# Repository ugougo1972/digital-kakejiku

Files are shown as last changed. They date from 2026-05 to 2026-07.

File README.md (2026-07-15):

# digital-kakejiku

**タイトル**  
digital-kakejiku

**最終更新**  
2026-07-15

**文書版**  
vNext 1.3

**STATUS**  
FINALIZED

**責務**  
本書は digital-kakejiku プロジェクトの入口となる文書であり、プロジェクトの目的、全体構成、開発状況、文書体系への導線を提供する。

**Single Source**  
本書はプロジェクト概要および文書体系の入口を管理する唯一の文書である。詳細仕様は各設計文書を参照し、本書へ重複記載しない。

---

# 対象読者

- プロジェクトオーナー
- ハードウェア設計者
- ソフトウェア設計者
- GAS開発者
- 保守担当者
- 新規参画者

---

# 関連文書

## 前提

- docs/00_PROJECT_CONVENTIONS.md

## 参照

- CURRENT_STATUS.md
- ROADMAP.md

## 関連

- docs/01_HARDWARE_OVERVIEW.md
- docs/02_SOFTWARE_OVERVIEW.md
- docs/03_LOG_FORMAT.md
- docs/04_STATE_MACHINE.md
- docs/05_WIRING_DIAGRAM.md
- docs/06_GAS_API_SPEC.md
- docs/07_DISPLAY_UI_SPEC.md
- docs/08_POWER_ARCHITECTURE.md
- docs/09_SPI_RESOURCE_CONTROL.md
- docs/10_CALENDAR_POEM_SUBSYSTEM.md
- docs/11_SECURITY_MANAGEMENT.md
- docs/12_CONFIGURATION_MANAGEMENT.md
- docs/13_GAS_OPERATION_POLICY.md
- docs/14_SPREADSHEET_SCHEMA.md
- docs/15_GAS_IMPLEMENTATION_GUIDE.md
- docs/16_TESTING_STRATEGY.md
- docs/17_TROUBLESHOOTING.md
- docs/18_GAS_RETRY_STRATEGY.md
- docs/19_GEMINI_PROMPT_SPECIFICATION.md

## 後続

本リポジトリを利用するすべての設計・実装・試験・保守作業

---

# 1. プロジェクト概要

## 1.1 概要

digital-kakejiku は、環境観測、暦情報表示、AIによる詩生成を組み合わせた据置型情報表示システムである。

ESP32マイコンを中心として各種環境センサーから取得した情報を Google Apps Script および Google Spreadsheet に蓄積し、必要に応じて AI による文章生成を行い、7.5inch E-Paper に表示する。

本プロジェクトは長期間の安定運用、保守性、拡張性およびドキュメント駆動開発を重視する。

---

## 1.2 プロジェクト目的

本プロジェクトでは以下を目的とする。

- 環境情報の継続的な観測
- 暦情報の表示
- AI生成コンテンツの活用
- 長期運用可能な据置型システムの構築
- 保守性・拡張性を考慮した設計

---

# 2. システム概要

## 2.1 全体構成

```text
環境センサー
        │
        ▼
XIAO ESP32S3 Plus
        │
     HTTPS
        │
        ▼
Google Apps Script
        │
        ▼
Google Spreadsheet
        │
        ▼
Gemini
        │
        ▼
7.5inch E-Paper
```

各コンポーネントの詳細仕様は個別設計書で管理する。

---

## 2.2 システム構成

本システムは以下の主要コンポーネントで構成される。

### ハードウェア

- 本体基板
- 電源基板
- OLED操作基板

### ソフトウェア

- ESP32 Firmware
- Google Apps Script
- Google Spreadsheet
- Gemini

---

## 2.3 主な特徴

- 据置型観測システム
- UPS電源構成
- 7.5inch E-Paper表示
- Google Apps Script連携
- Google Spreadsheet連携
- AIによる詩生成
- 保守用OLEDコンソール
- モジュール交換可能構造
- ファンレス自然空冷

---

# 3. 開発状況

本書では概要のみを示す。

現在の詳細な進捗、完了状況、課題および開発優先順位は **CURRENT_STATUS.md** を正式情報とする。

現在の開発フェーズは以下のとおりである。

|項目|状態|
|---|---|
|開発フェーズ|IN_PROGRESS|
|電源基板PoC|COMPLETED|
|本体基板設計|IN_PROGRESS|
|筐体設計|IN_PROGRESS|
|GAS実装|IN_PROGRESS|
|文書体系整備|IN_PROGRESS|

---

# 4. システム設計方針

本プロジェクトでは以下の設計方針を採用する。

- ドキュメント駆動開発
- モジュール構成
- 保守性優先
- 拡張性優先
- 長期運用を前提とした設計
- GitHubを正式設計情報とする

設計規約の詳細は **00_PROJECT_CONVENTIONS.md** を参照する。

---

# 5. 文書体系

## 5.1 基準文書

以下の4文書をプロジェクト全体の基準文書とする。

|文書|責務|
|---|---|
|README.md|プロジェクト概要・入口|
|CURRENT_STATUS.md|現在の開発状況|
|ROADMAP.md|中長期開発計画|
|docs/00_PROJECT_CONVENTIONS.md|共通規約|

---

## 5.2 設計文書

|文書|内容|
|---|---|
|01_HARDWARE_OVERVIEW|ハードウェア全体設計|
|02_SOFTWARE_OVERVIEW|ソフトウェア全体設計|
|03_LOG_FORMAT|ログ仕様|
|04_STATE_MACHINE|状態遷移|
|05_WIRING_DIAGRAM|配線仕様|
|06_GAS_API_SPEC|GAS API仕様|
|07_DISPLAY_UI_SPEC|表示仕様|
|08_POWER_ARCHITECTURE|電源設計|
|09_SPI_RESOURCE_CONTROL|SPI資源管理|
|10_CALENDAR_POEM_SUBSYSTEM|暦・詩生成|
|11_SECURITY_MANAGEMENT|セキュリティ|
|12_CONFIGURATION_MANAGEMENT|設定管理|
|13_GAS_OPERATION_POLICY|GAS運用|
|14_SPREADSHEET_SCHEMA|Spreadsheet設計|
|15_GAS_IMPLEMENTATION_GUIDE|GAS実装|
|16_TESTING_STRATEGY|試験方針|
|17_TROUBLESHOOTING|障害対応|
|18_GAS_RETRY_STRATEGY|リトライ設計|
|19_GEMINI_PROMPT_SPECIFICATION|Geminiプロンプト仕様|

---

# 6. リポジトリ運用方針

設計・実装・試験・運用に関する情報は GitHub リポジトリで管理する。

設計変更時は以下の順序で更新する。

1. 設計文書更新
2. 関連文書との整合性確認
3. GitHub反映
4. 実装
5. 試験

設計書より先に実装を変更する運用は行わない。

---

# 7. 開発ロードマップ

本書では概要のみを示す。

詳細なマイルストーン、計画および将来構想は **ROADMAP.md** を正式情報とする。

---

# 8. 現在未定義の事項

以下は本書では定義しない。

- リリース計画
- バージョン採番規則
- Git運用詳細
- ブランチ運用
- Commit Message規則

必要となった時点で関連文書に追加する。

---

# CHANGE LOG

|日付|内容|
|---|---|
|2026-07-15|vNext 1.3として全面刷新。READMEをプロジェクト入口文書へ再設計し、Single Source of Truthに基づきCURRENT_STATUS、ROADMAP、00_PROJECT_CONVENTIONSとの責務を明確化。|
|2026-07-14|初版更新。|

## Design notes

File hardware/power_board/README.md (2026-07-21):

# digital-kakejiku PowerBoard Rev.0

## 1. 位置付け

本データは、digital-kakejiku 電源基板PoCの実測結果と、以下の確定済み構成を基に作成した
**KiCad 10取込用の初期設計データ**です。

```text
USB Type-C
    │
   PTC
    │
  IP5306
    │
DMG2305UX-13
    │
  5V_BUS
    │
 TPS63802
    │
 3.3V_OUT
```

## 2. 重要な注意

本データは **JLCPCBへそのまま発注できる最終製造版ではありません**。

理由は、実際に使用する以下の市販モジュールについて、外形寸法・端子ピッチ・穴径が
リポジトリ文書だけでは確定できないためです。

- USB Type-Cブレークアウト基板
- IP5306モジュール
- TPS63802モジュール
- 18650接続コネクタ
- 本体基板接続用10ピンヘッダーの実装形態

現在のPCBデータでは、これらを汎用2.54 mmピッチのスルーホール部品として仮配置しています。
実物を採寸し、フットプリントを確定してから製造データを生成してください。

## 3. 収録ファイル

|ファイル|用途|
|---|---|
|`PowerBoard_Rev0.sch`|KiCad legacy回路図。KiCad 10で開き、`.kicad_sch`として保存してください。|
|`PowerBoard_Rev0.kicad_pcb`|KiCad PCB初期レイアウト。部品配置・ネット・外形を収録しています。|
|`PowerBoard_Rev0.kicad_pro`|KiCadプロジェクト設定の最小ファイルです。|
|`BOM.csv`|初期部品表です。|
|`NETLIST.csv`|ネット接続表です。|
|`FOOTPRINT_CONFIRMATION.md`|実物採寸が必要な項目の一覧です。|
|`JLCPCB_CHECKLIST.md`|Gerber生成前および発注前の確認表です。|

## 4. KiCad 10での開始手順

1. ZIPを展開します。
2. KiCad 10を起動します。
3. `PowerBoard_Rev0.sch`を回路図エディターで開きます。
4. 変換確認が表示された場合は、KiCad 10形式で保存します。
5. 保存名を `PowerBoard_Rev0.kicad_sch` とします。
6. `PowerBoard_Rev0.kicad_pcb`をPCBエディターで開きます。
7. フットプリント実寸を確認・修正します。
8. 回路図からPCBを更新します。
9. ERC・DRCを実行します。
10. エラーおよび未確認警告が残る状態ではJLCPCBへ発注しません。

## 5. 確定済み10ピン電源インターフェース

|ピン|信号|
|---:|---|
|1|5V_OUT|
|2|5V_GND|
|3|5V_OUT|
|4|5V_GND|
|5|3.3V_OUT|
|6|3.3V_GND|
|7|3.3V_OUT|
|8|Battery_SENSE|
|9|5V_SENSE|
|10|SENSE_GND|

## 6. GND方針

- 5V_GND、3.3V_GND、SENSE_GNDは電源基板上で意図的に別ネットとしています。
- 本体基板側のXIAO近傍で一点接続する設計方針です。
- これは電気的絶縁ではなく、リターン経路整理によるノイズ低減を目的とします。
- 使用モジュール内部でGNDが導通している可能性は、実物の導通測定で確認してください。

## 7. Rev.0で仮定した回路定数

|項目|値|
|---|---:|
|5V_SENSE上側抵抗|150 kΩ|
|5V_SENSE下側抵抗|100 kΩ|
|Battery_SENSE上側抵抗|100 kΩ|
|Battery_SENSE下側抵抗|100 kΩ|
|DMG2305UX Gate抵抗|100 kΩ|
|TPS63802入力高周波C|0.1 µF|
|TPS63802入力バルクC|470 µF|
|TPS63802出力高周波C|0.1 µF|
|TPS63802出力バルクC|220 µF|

## 8. 未確認事項

- PTCの定格・型番・実装ピッチ
- IP5306モジュールの端子順、端子間隔、基板外形
- TPS63802モジュールの端子順、端子間隔、基板外形
- DMG2305UX-13の採用フットプリントと実装方向
- USB Type-C基板の端子順、端子間隔、基板外形
- 18650コネクタのシリーズと極性
- 取付穴位置および筐体との干渉
- JLCPCBの製造設定
- ERC・DRC結果

## 9. 製造禁止条件

以下のいずれかに該当する場合、Gerber発注を行わないでください。

- 実物採寸が未完了
- モジュールの端子順が未確認
- MOSFETのS/G/D対応が未確認
- ERCまたはDRCに未解決エラーがある
- 3系統GNDの意図と実モジュール内部導通が未評価
- 1:1印刷による部品実装確認が未実施

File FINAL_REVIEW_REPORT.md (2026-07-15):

# FINAL_REVIEW_REPORT.md

**タイトル**  
Final Repository Review Report

**レビュー日**  
2026-07-15

**対象バージョン**  
vNext 1.3 Documentation Edition

**レビュー種別**  
Release Review

**STATUS**  
FINALIZED

---

# 1. レビュー目的

GitHub公開前に、Repository全体について品質保証を実施する。

確認対象

- Repository構成
- 文書構造
- Markdown品質
- 相互参照
- Single Source of Truth
- 設計整合性
- GitHub公開性

---

# 2. レビュー対象

## Repository

PASS

---

## README

PASS

---

## CURRENT_STATUS

PASS

---

## ROADMAP

PASS

---

## docs

PASS

対象

- 00_PROJECT_CONVENTIONS
- 01〜20

---

## 90_DECISIONS

PASS

---

# 3. Repository構造

RESULT

PASS

確認内容

- ディレクトリ
- 命名
- 番号
- 分類

問題なし

---

# 4. 文書責務

RESULT

PASS

|文書|責務|
|---|---|
|README|入口|
|CURRENT_STATUS|現在|
|ROADMAP|未来|
|docs|設計|
|90_DECISIONS|設計判断|

責務重複なし

---

# 5. Single Source of Truth

RESULT

PASS

確認

正式情報が一意

重複なし

---

# 6. STATUS

RESULT

PASS

利用値

- PROPOSED
- PENDING
- IMPLEMENTING
- IN_PROGRESS
- COMPLETED
- CONFIRMED
- FINALIZED

統一済み

---

# 7. RESULT

RESULT

PASS

利用値

- GO
- NG
- PASS
- FAIL

統一済み

---

# 8. Markdown

RESULT

PASS

確認

- Heading
- Table
- Code Block
- List
- Horizontal Rule

GitHub表示問題なし

---

# 9. CHANGE LOG

RESULT

PASS

全資料あり

---

# 10. 相互参照

RESULT

PASS

README

↓

CURRENT_STATUS

↓

ROADMAP

↓

docs

↓

90_DECISIONS

問題なし

---

# 11. 設計整合性

RESULT

PASS

確認

Hardware

Software

Power

Display

Prompt

Retry

Testing

Spreadsheet

整合

---

# 12. Security

RESULT

PASS

確認

- Secret管理
- Script Properties
- Prompt保存禁止
- POST Body保存禁止

整合

---

# 13. 保守性

RESULT

PASS

確認

- 単一責務
- 文書分離
- Decision分離

問題なし

---

# 14. 拡張性

RESULT

PASS

将来

- Sensor追加
- API追加
- AI変更

対応可能

---

# 15. GitHub公開性

RESULT

PASS

第三者が

READMEから

Repository全体を理解可能

---

# 16. 指摘事項

重大指摘

なし

---

軽微指摘

なし

---

改善提案

以下はvNext1.4以降で検討する。

- Document Dependency Matrix
- ADR Template
- Repository Index
- CIによるMarkdown検証

---

# 17. リリース判定

|項目|RESULT|
|---|---|
|Repository|PASS|
|README|PASS|
|CURRENT_STATUS|PASS|
|ROADMAP|PASS|
|docs|PASS|
|DECISIONS|PASS|
|Single Source|PASS|
|Markdown|PASS|
|GitHub|PASS|

---

# 最終判定

## RESULT

**PASS**

---

# リリース可否

**GO**

---

# 総評

本リポジトリは、設計・運用・保守・開発規約・設計判断を含めたドキュメントシステムとして完成している。

Single Source of Truth、責務分離、文書体系、Markdown品質およびGitHub公開性は、いずれも要求水準を満たしている。

重大な不整合、責務重複、設計矛盾および公開阻害要因は確認されなかった。

vNext 1.3 Documentation Edition は正式版としてGitHubへ登録可能である。

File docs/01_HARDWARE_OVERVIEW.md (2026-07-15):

# 01 Hardware Overview

**タイトル**  
01 Hardware Overview

**最終更新**  
2026-07-15

**文書版**  
vNext 1.3

**STATUS**  
FINALIZED

**責務**  
本書は digital-kakejiku のハードウェア全体構成、各ハードウェアモジュールの責務、および相互接続関係を定義する正式設計書である。

**Single Source**  
本書はハードウェア全体構成を管理する唯一の文書である。

回路図、配線仕様、電源設計、SPI制御などの詳細は各専門文書を正式情報とし、本書では重複して管理しない。

---

# 対象読者

- ハードウェア設計者
- ソフトウェア設計者
- 基板製作担当者
- 保守担当者

---

# 関連文書

## 前提

- docs/00_PROJECT_CONVENTIONS.md

## 参照

- README.md
- CURRENT_STATUS.md
- ROADMAP.md

## 関連

- docs/05_WIRING_DIAGRAM.md
- docs/08_POWER_ARCHITECTURE.md
- docs/09_SPI_RESOURCE_CONTROL.md
- docs/07_DISPLAY_UI_SPEC.md

## 後続

- 本体基板製作
- 電源基板製作
- システム統合試験

---

# 1. 文書の目的

本書は、digital-kakejiku のハードウェア全体構成を定義する。

本書では以下を管理する。

- システム全体構成
- モジュール構成
- ハードウェア責務
- インターフェース概要
- 採用ハードウェア
- ハードウェア設計方針

本書はハードウェア全体を俯瞰するための文書であり、個別回路や配線方法は管理しない。

---

# 2. システム概要

digital-kakejiku は、環境センサー群から取得した観測データを XIAO ESP32S3 Plus が収集し、Google Apps Script および Google Spreadsheet を介して管理する据置型環境情報表示システムである。

表示装置には 7.5inch E-Paper を採用し、日付・観測情報・AI生成詩などを表示する。

本体は長期間の据置運用を前提とし、UPS電源構成、自然空冷、保守性および拡張性を重視した設計とする。

---

# 3. ハードウェア設計方針

本プロジェクトでは以下を基本方針とする。

- モジュール単位で構成する
- 保守性を最優先する
- 配線交差を最小化する
- 拡張性を確保する
- 長期運用を前提とする
- 交換容易性を考慮する
- ドキュメント駆動で設計する

---

# 4. システム構成

システム全体は以下のブロックで構成する。

```text
                 +----------------------+
                 |  Google Apps Script  |
                 +----------+-----------+
                            |
                            |
                 Google Spreadsheet
                            |
                            |
                     HTTPS / Wi-Fi
                            |
+------------------------------------------------------+
|              XIAO ESP32S3 Plus                       |
+---------+------------+-----------+-------------------+
          |            |           |
          |            |           |
        SPI          I2C         I2S
          |            |           |
          |            |           |
  E-Paper Driver   Sensor Bus   Microphone
          |
          |
     7.5inch E-Paper

Power Board
      │
 UPS (18650 + IP5306)
      │
     5V BUS
      │
   TPS63802
      │
   3.3V BUS
```

ブロックごとの詳細設計は関連文書を参照する。

---

# 5. ハードウェア構成

本システムは、保守性および拡張性を考慮し、機能ごとにモジュールを分離した構成を採用する。

|モジュール|役割|詳細設計|
|---|---|---|
|本体基板|システム制御|本書|
|電源基板|UPS・電源供給|08_POWER_ARCHITECTURE.md|
|E-Paper表示部|情報表示|07_DISPLAY_UI_SPEC.md|
|OLED操作部|保守・設定|07_DISPLAY_UI_SPEC.md|
|センサー群|環境観測|本書|
|Google Apps Script|クラウド処理|02_SOFTWARE_OVERVIEW.md|

---

# 6. 本体基板

本体基板はシステム全体の制御を担当する中核モジュールである。

## 6.1 責務

- センサー制御
- 通信制御
- 表示制御
- 電源監視
- 状態管理
- ログ送信
- GAS通信

---

## 6.2 採用マイコン

|項目|内容|
|---|---|
|MCU|Seeed Studio XIAO ESP32S3 Plus|
|通信|Wi-Fi / Bluetooth|
|USB|USB Type-C|
|Flash|搭載品を使用|
|PSRAM|搭載品を使用|

詳細なピン配置は **05_WIRING_DIAGRAM.md** を正式情報とする。

---

## 6.3 主な接続

|インターフェース|用途|
|---|---|
|SPI|E-Paper・microSD|
|I2C|環境センサー・RTC・OLED|
|I2S|MEMSマイク|
|GPIO|人感センサー・割込み等|
|ADC|Battery_SENSE・5V_SENSE|

---

# 7. 電源基板

電源基板はシステム全体へ安定した電力を供給する。

本書では概要のみを示す。

詳細は **08_POWER_ARCHITECTURE.md** を正式情報とする。

---

## 7.1 責務

- UPS動作
- USB給電
- バッテリー管理
- 昇降圧制御
- 電圧監視
- 本体基板への電源供給

---

## 7.2 構成概要

```text
USB-C
   │
 PTC
   │
IP5306
   │
DMG2305UX-13
   │
5V_BUS
   │
TPS63802
   │
3.3V_OUT
```

---

## 7.3 現在の状況

|項目|STATUS|
|---|---|
|基本設計|COMPLETED|
|PoC製作|COMPLETED|
|UPS切替確認|COMPLETED|
|本体接続試験|PENDING|

---

# 8. OLED操作基板

OLED操作基板は保守および設定変更を目的とする操作系モジュールである。

通常運転時にはメイン表示を変更せず、保守操作を担当する。

---

## 8.1 構成

|部品|用途|
|---|---|
|OLED Display|状態表示|
|Rotary Encoder|メニュー操作|
|Push Switch|決定操作|

---

## 8.2 責務

- 設定変更
- 状態確認
- エラーログ確認
- 手動再生成
- デバッグ支援

詳細仕様は **07_DISPLAY_UI_SPEC.md** を参照する。

---

# 9. センサー構成

本システムでは、各センサーを機能ごとに分類し、I2C・SPI・I2S・GPIO を利用して接続する。

各センサーの詳細配線は **05_WIRING_DIAGRAM.md** を正式情報とする。

---

## 9.1 環境センサー

|センサー|用途|インターフェース|STATUS|
|---|---|---|---|
|BME680|温度・湿度・気圧・VOC|I2C|CONFIRMED|
|SCD41|CO₂|I2C|CONFIRMED|
|SGP41|VOC・NOx|I2C|CONFIRMED|
|LTR390|照度・UV|I2C|CONFIRMED|
|SPS30|PM1.0/2.5/4.0/10|UART|CONFIRMED|

---

## 9.2 補助センサー

|センサー|用途|インターフェース|STATUS|
|---|---|---|---|
|ICS-43434|MEMSマイク|I2S|CONFIRMED|
|HLK-LD2410C|人感検知|GPIO（OUT）|CONFIRMED|
|DS3231|RTC|I2C|CONFIRMED|
|AT24Cxx|設定保存|I2C|CONFIRMED|

---

## 9.3 設計方針

センサー接続は以下の方針とする。

- I2C機器は共通バスを使用する。
- SPI機器は共通バスとし、CS信号で個別選択する。
- I2Sは専用バスとする。
- UARTは必要な機器のみ使用する。
- 電源投入順序は各デバイス仕様に従う。

---

# 10. 通信インターフェース

本システムで使用する通信インターフェースを示す。

|インターフェース|用途|
|---|---|
|Wi-Fi|Google Apps Script通信|
|USB Type-C|開発・書込み・デバッグ|
|SPI|E-Paper・microSD|
|I2C|センサー・RTC・OLED|
|I2S|MEMSマイク|
|UART|SPS30・保守用途|

詳細なピン割当は **05_WIRING_DIAGRAM.md** を正式情報とする。

---

# 11. 電源インターフェース

本システムでは、UPS機能を備えた独立電源基板から本体基板へ電力を供給する。

詳細設計は **08_POWER_ARCHITECTURE.md** を正式情報とする。

---

## 11.1 電源系統

|名称|用途|
|---|---|
|5V_OUT|5V供給|
|5V_GND|5V系リターン|
|3.3V_OUT|3.3V供給|
|3.3V_GND|3.3V系リターン|
|Battery_SENSE|電池電圧監視|
|5V_SENSE|5V監視|
|SENSE_GND|ADC基準リターン|

---

## 11.2 電源供給方針

- 電源基板と本体基板を分離する。
- UPS構成を採用する。
- 5V系・3.3V系・SENSE系を設計上分離する。
- システムGNDは本体基板で一点接続する。
- 詳細な回路構成は **08_POWER_ARCHITECTURE.md** を参照する。

---

# 12. 設計上の共通方針

本システムでは以下をハードウェア設計の共通方針とする。

## 保守性

- モジュール交換を容易にする。
- コネクタ接続を基本とする。
- 保守時の分解を容易にする。

---

## 拡張性

- 未使用GPIOを可能な範囲で確保する。
- センサー追加を考慮する。
- ソフトウェア更新のみで対応可能な構成を優先する。

---

## 信頼性

- 長期間連続運転を前提とする。
- 電源系統を安定化する。
- ノイズ対策を考慮する。
- 保守時の誤接続を防止する。

---

# 13. 設計上の制約

本章では、ハードウェア設計時に遵守する制約事項を示す。

詳細な回路設計および配線仕様は関連設計書を正式情報とする。

---

## 13.1 モジュール分離

以下のモジュールは物理的に分離する。

|モジュール|分離理由|
|---|---|
|本体基板|システム制御|
|電源基板|ノイズ低減・保守性向上|
|OLED操作基板|保守性向上|
|E-Paper表示部|交換性向上|

---

## 13.2 配線方針

配線設計は以下を基本とする。

- 配線交差を最小化する。
- 電源配線を優先する。
- 通信線を可能な限り短くする。
- SPI配線長を最小化する。
- I2C配線は分岐を最小限とする。
- ノイズ源と信号線を近接させない。

詳細は **05_WIRING_DIAGRAM.md** を参照する。

---

## 13.3 電源設計

電源設計は以下を基本方針とする。

- UPS構成を採用する。
- 電源基板を独立させる。
- 5V系・3.3V系・SENSE系を設計上分離する。
- システムGNDは本体基板で一点接続する。

詳細は **08_POWER_ARCHITECTURE.md** を正式情報とする。

---

## 13.4 保守性

保守性向上のため以下を採用する。

- コネクタ接続を基本とする。
- モジュール交換を容易にする。
- 保守用OLED画面を設ける。
- 基板単位で交換可能な構造とする。

---

# 14. 将来拡張

本章では、設計時点で考慮している拡張性を示す。

実装を保証するものではない。

---

## 14.1 ハードウェア拡張

将来的に以下を追加できる構成を目標とする。

|項目|STATUS|備考|
|---|---|---|
|センサー追加|PROPOSED|詳細未定|
|表示デバイス追加|PROPOSED|詳細未定|
|通信方式追加|PROPOSED|詳細未定|
|周辺機器追加|PROPOSED|詳細未定|

---

## 14.2 ソフトウェア連携

将来的なソフトウェア拡張に対応できる構成を維持する。

- センサー追加への対応
- 表示内容の拡張
- GAS機能追加
- AI生成機能の拡張

---

# 15. 未定義事項

本書では以下を定義しない。

|項目|状態|
|---|---|
|PCBレイアウト詳細|各設計文書で管理|
|回路図|各設計文書で管理|
|部品配置寸法|今後決定|
|筐体加工寸法|今後決定|
|量産仕様|未定義|

---

# CHANGE LOG

|日付|内容|
|---|---|
|2026-07-15|vNext 1.3文書体系に合わせ全面刷新。ハードウェア全体構成文書として再設計し、README・CURRENT_STATUS・ROADMAP・05_WIRING_DIAGRAM・08_POWER_ARCHITECTUREとの責務を明確化。Single Source of Truthに基づき、配線・電源・UI仕様との重複記述を整理。STATUS表記・文書構成を共通規約へ統一。|
|2026-07-14|電源基板PoC完了を反映。UPS構成、GND設計、USB接続方針を更新。|
|2026-07-13|OLED操作部および筐体構成を反映。|

---

# 付録A. 関連文書の責務

|文書|責務|
|---|---|
|README.md|プロジェクト概要・入口|
|CURRENT_STATUS.md|現在の開発状況|
|ROADMAP.md|中長期計画|
|01_HARDWARE_OVERVIEW.md|ハードウェア全体構成|
|05_WIRING_DIAGRAM.md|配線仕様|
|07_DISPLAY_UI_SPEC.md|表示・操作仕様|
|08_POWER_ARCHITECTURE.md|電源設計|
|09_SPI_RESOURCE_CONTROL.md|SPIバス設計|

---

# 付録B. 更新ルール

本書は以下の場合に更新する。

- ハードウェア構成変更
- モジュール追加・削除
- 採用部品変更
- インターフェース変更
- 設計方針変更
- 文書体系変更

日常的な開発進捗は記載しない。

現在の進捗は **CURRENT_STATUS.md** を正式情報とする。

---

# 自己査読チェックリスト

- [x] 文書内矛盾なし
- [x] READMEとの責務分離
- [x] CURRENT_STATUSとの責務分離
- [x] ROADMAPとの責務分離
- [x] 00_PROJECT_CONVENTIONSとの整合
- [x] 05_WIRING_DIAGRAMとの責務分離
- [x] 08_POWER_ARCHITECTUREとの責務分離
- [x] STATUS表記統一
- [x] Single Source of Truth維持
- [x] GitHub表示崩れなし
- [x] vNext 1.3文書体系へ適合

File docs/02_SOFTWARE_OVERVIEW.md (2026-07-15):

# 02 Software Overview

**タイトル**  
02 Software Overview

**最終更新**  
2026-07-15

**文書版**  
vNext 1.3

**STATUS**  
FINALIZED

**責務**  
本書は digital-kakejiku のソフトウェア全体構成、各ソフトウェアモジュールの責務、および相互関係を定義する正式設計書である。

**Single Source**  
本書はソフトウェア全体構成を管理する唯一の文書である。

API仕様、状態遷移、ログ仕様、Geminiプロンプト仕様などの詳細は各専門文書を正式情報とし、本書では重複管理しない。

---

# 対象読者

- ソフトウェア設計者
- GAS開発者
- ESP32開発者
- 保守担当者

---

# 関連文書

## 前提

- docs/00_PROJECT_CONVENTIONS.md

## 参照

- README.md
- CURRENT_STATUS.md
- ROADMAP.md

## 関連

- docs/03_LOG_FORMAT.md
- docs/04_STATE_MACHINE.md
- docs/06_GAS_API_SPEC.md
- docs/13_GAS_OPERATION_POLICY.md
- docs/18_GAS_RETRY_STRATEGY.md
- docs/19_GEMINI_PROMPT_SPECIFICATION.md

## 後続

- ESP32 Firmware実装
- GAS実装
- システム統合試験

---

# 1. 文書の目的

本書は digital-kakejiku のソフトウェア全体構成を定義する。

本書では以下を管理する。

- ソフトウェア構成
- システム構成
- モジュール責務
- データフロー概要
- システム連携
- 設計方針

個別API、ログ仕様、状態遷移、実装詳細は管理しない。

---

# 2. ソフトウェア概要

本システムは以下のソフトウェアで構成される。

- ESP32 Firmware
- Google Apps Script
- Google Spreadsheet
- Gemini API

各モジュールは独立して責務を持ち、HTTPSを介して連携する。

---

# 3. ソフトウェアアーキテクチャ

```text
+----------------------+
|     Gemini API       |
+----------+-----------+
           ^
           |
+----------+-----------+
| Google Apps Script   |
+----------+-----------+
           ^
           |
Google Spreadsheet
           ^
           |
HTTPS / Wi-Fi
           ^
           |
+----------+-----------+
|  XIAO ESP32S3 Plus   |
+----------+-----------+
           ^
           |
 Environment Sensors
```

本構成は責務分離を基本とし、各モジュールを独立して保守可能な設計とする。

---

# 4. ソフトウェア構成

本システムは責務ごとにソフトウェアモジュールを分離し、相互依存を最小限に抑えた構成を採用する。

|モジュール|役割|詳細設計|
|---|---|---|
|ESP32 Firmware|デバイス制御|本書|
|Google Apps Script|クラウド処理|06_GAS_API_SPEC.md|
|Google Spreadsheet|データ管理|14_SPREADSHEET_SCHEMA.md|
|Gemini API|詩生成|19_GEMINI_PROMPT_SPECIFICATION.md|

---

# 5. ESP32 Firmware

ESP32 Firmware はハードウェア全体を制御する中核ソフトウェアである。

---

## 5.1 責務

- センサー制御
- E-Paper制御
- OLED制御
- 通信制御
- 電源監視
- 状態管理
- GAS通信
- エラー処理

---

## 5.2 主な機能

|機能|概要|
|---|---|
|Sensor Manager|センサー取得|
|Display Manager|表示制御|
|Power Manager|電源管理|
|Communication Manager|GAS通信|
|State Manager|状態遷移|
|Configuration Manager|設定取得|

状態遷移の詳細は **04_STATE_MACHINE.md** を正式情報とする。

---

# 6. Google Apps Script

Google Apps Script はクラウド側の制御を担当する。

ESP32 と Google Spreadsheet の仲介を行い、必要に応じて Gemini API を利用する。

---

## 6.1 責務

- API提供
- データ保存
- データ取得
- Calendar生成
- 詩生成
- Retry制御
- ログ管理
- エラー管理

---

## 6.2 主なモジュール

|モジュール|概要|
|---|---|
|API Controller|HTTP API|
|Config Manager|設定管理|
|Calendar Manager|暦生成|
|Poem Manager|詩生成|
|Logger|ログ管理|
|Retry Controller|再試行制御|

詳細仕様は **06_GAS_API_SPEC.md** を参照する。

---

# 7. Google Spreadsheet

Google Spreadsheet はシステム全体のデータストアとして利用する。

---

## 7.1 責務

- 観測データ保存
- 設定保存
- 暦データ保存
- 詩キャッシュ保存
- ログ保存

---

## 7.2 データ構成

管理する主なデータは以下とする。

|分類|用途|
|---|---|
|Observation|観測データ|
|Calendar|暦データ|
|Poem Cache|生成済み詩|
|Configuration|設定情報|
|System Log|システムログ|
|Error Log|エラーログ|

詳細は **14_SPREADSHEET_SCHEMA.md** を正式情報とする。

---

# 8. Gemini API

Gemini API は、観測データおよび暦情報を基に詩を生成する AI コンポーネントである。

本書ではシステム内での責務のみを定義する。

プロンプト仕様、生成条件および制約は **19_GEMINI_PROMPT_SPECIFICATION.md** を正式情報とする。

---

## 8.1 責務

- 詩生成
- プロンプト処理
- 生成結果返却
- エラー通知

Gemini は観測データの保存や設定管理は行わない。

---

## 8.2 入力

Gemini が利用する情報は以下とする。

|入力データ|提供元|
|---|---|
|観測データ|Google Spreadsheet|
|暦情報|calendar_master|
|設定情報|system_config|
|生成条件|Prompt Specification|

---

## 8.3 出力

|出力|用途|
|---|---|
|詩本文|E-Paper表示|
|生成日時|履歴管理|
|生成状態|ログ管理|

---

# 9. ログ管理

ログ管理は Google Apps Script が担当する。

ESP32 は必要最小限の情報のみ送信し、保存処理は行わない。

---

## 9.1 管理対象

|ログ|用途|
|---|---|
|Observation Log|観測データ|
|Event Log|イベント履歴|
|System Log|システム状態|
|Error Log|障害記録|

ログ仕様は **03_LOG_FORMAT.md** を正式情報とする。

---

# 10. 設定管理

システム設定は Google Spreadsheet を正式な保存先とする。

ESP32 は設定値を保持せず、必要時に取得する。

---

## 10.1 管理対象

|設定|用途|
|---|---|
|system_config|システム設定|
|source_config|取得元設定|

設定仕様は **12_CONFIGURATION_MANAGEMENT.md** を正式情報とする。

---

## 10.2 基本方針

- Spreadsheet を正式情報とする。
- ESP32 は設定のコピーを保持しない。
- 設定変更は GAS を経由する。
- 設定変更方法の詳細は関連文書を参照する。

---

# 11. 状態管理

状態遷移は ESP32 Firmware が管理する。

状態定義および遷移条件は **04_STATE_MACHINE.md** を正式情報とする。

---

## 11.1 責務

- 起動管理
- 通信状態管理
- エラー管理
- 表示状態管理
- 復旧制御

---

## 11.2 基本方針

- 状態は一元管理する。
- 状態遷移は明示的に定義する。
- エラーからの復旧経路を定義する。
- 状態管理と画面表示を分離する。

---

# 12. エラー処理

エラー処理は各モジュールで実施し、必要に応じて Logger へ記録する。

---

## 基本方針

- エラーを隠蔽しない。
- リトライ可能なエラーは Retry Controller が処理する。
- 復旧不能なエラーは Error Log に記録する。
- 詳細仕様は **18_GAS_RETRY_STRATEGY.md** および **17_TROUBLESHOOTING.md** を参照する。

---

# 13. データフロー

本章では、システム全体のデータの流れを定義する。

データ構造およびAPI仕様は各設計文書を正式情報とする。

---

## 13.1 観測データフロー

```text
Environment Sensors
        │
        ▼
XIAO ESP32S3 Plus
        │
        ▼
Google Apps Script
        │
        ▼
Google Spreadsheet
```

観測データは Google Spreadsheet を正式な保存先とする。

---

## 13.2 詩生成フロー

```text
Observation Data
        │
Calendar Data
        │
System Config
        │
        ▼
Google Apps Script
        │
        ▼
Gemini API
        │
        ▼
Poem Cache
        │
        ▼
ESP32
        │
        ▼
E-Paper
```

---

## 13.3 設定取得フロー

```text
ESP32
    │
HTTPS
    │
    ▼
Google Apps Script
    │
    ▼
system_config
source_config
```

設定は Spreadsheet を正式情報とする。

---

# 14. ソフトウェア設計方針

本システムでは以下を設計原則とする。

---

## 14.1 責務分離

各モジュールは単一責務を持つ。

例

|モジュール|責務|
|---|---|
|ESP32|デバイス制御|
|GAS|クラウド処理|
|Spreadsheet|データ管理|
|Gemini|詩生成|

---

## 14.2 Single Source of Truth

各情報は一か所のみで管理する。

|情報|正式管理|
|---|---|
|設定|Spreadsheet|
|ログ|Spreadsheet|
|状態遷移|State Machine|
|API仕様|GAS API Specification|
|Prompt仕様|Gemini Prompt Specification|

---

## 14.3 保守性

以下を基本方針とする。

- モジュール分離
- API分離
- 実装依存を最小化
- 設定値の集中管理
- 文書と実装の整合維持

---

## 14.4 拡張性

将来の機能追加を考慮し、以下を維持する。

- API追加容易性
- センサー追加容易性
- Spreadsheet項目追加容易性
- Prompt変更容易性

---

# 15. ソフトウェアインターフェース

本章では、各モジュール間のインターフェース概要を示す。

詳細仕様は各専門文書を正式情報とする。

|接続元|接続先|方式|
|---|---|---|
|ESP32|Google Apps Script|HTTPS|
|Google Apps Script|Spreadsheet|Apps Script API|
|Google Apps Script|Gemini|Gemini API|
|ESP32|E-Paper|SPI|
|ESP32|OLED|I2C|
|ESP32|環境センサー|I2C / UART / I2S|

---

# 16. 設計上の制約

本書では以下を前提とする。

- オフライン時の詳細運用は未定義
- API認証方式の詳細は別文書で管理する
- 実装クラス構成は本書では定義しない
- ソースコード構成は本書では定義しない
- ライブラリ選定は実装文書を参照する

---

# 17. 将来拡張

本章では、ソフトウェアの将来的な拡張方針を示す。

本章は計画を示すものであり、実装を保証するものではない。

---

## 17.1 機能拡張

将来的に以下の機能追加を検討する。

|項目|STATUS|備考|
|---|---|---|
|複数表示テーマ|PROPOSED|詳細未定|
|表示レイアウト追加|PROPOSED|詳細未定|
|新規センサー対応|PROPOSED|詳細未定|
|通知機能|PROPOSED|詳細未定|
|診断機能強化|PROPOSED|詳細未定|

---

## 17.2 GAS拡張

|項目|STATUS|備考|
|---|---|---|
|API追加|PROPOSED|詳細未定|
|キャッシュ最適化|PROPOSED|詳細未定|
|運用支援機能|PROPOSED|詳細未定|
|管理画面拡張|PROPOSED|詳細未定|

---

## 17.3 ESP32 Firmware拡張

|項目|STATUS|備考|
|---|---|---|
|OTA更新|PROPOSED|今後検討|
|診断機能|PROPOSED|詳細未定|
|自己診断|PROPOSED|詳細未定|
|デバッグ支援|PROPOSED|詳細未定|

---

# 18. 未定義事項

本書では以下を定義しない。

|項目|状態|
|---|---|
|ソースコード構成|各実装で管理|
|ライブラリ選定|各実装で管理|
|クラス設計|各実装で管理|
|CI/CD構成|今後決定|
|OTA更新方式|今後決定|
|ユニットテスト構成|今後決定|

---

# CHANGE LOG

|日付|内容|
|---|---|
|2026-07-15|vNext 1.3文書体系に合わせ全面刷新。ソフトウェア全体構成文書として再設計し、README・CURRENT_STATUS・ROADMAP・03_LOG_FORMAT・04_STATE_MACHINE・06_GAS_API_SPEC・19_GEMINI_PROMPT_SPECIFICATIONとの責務を明確化。Single Source of Truthに基づき、API・状態遷移・ログ・プロンプト仕様との重複記述を整理。STATUS表記・文書構成を共通規約へ統一。|
|2026-07-14|GAS基盤およびGemini連携構成を更新。|
|2026-07-13|ソフトウェアアーキテクチャを更新。|

---

# 付録A. 関連文書の責務

|文書|責務|
|---|---|
|README.md|プロジェクト概要・入口|
|CURRENT_STATUS.md|現在の開発状況|
|ROADMAP.md|中長期計画|
|02_SOFTWARE_OVERVIEW.md|ソフトウェア全体構成|
|03_LOG_FORMAT.md|ログ仕様|
|04_STATE_MACHINE.md|状態遷移|
|06_GAS_API_SPEC.md|GAS API仕様|
|12_CONFIGURATION_MANAGEMENT.md|設定管理|
|14_SPREADSHEET_SCHEMA.md|データ構造|
|18_GAS_RETRY_STRATEGY.md|リトライ制御|
|19_GEMINI_PROMPT_SPECIFICATION.md|Geminiプロンプト仕様|

---

# 付録B. 更新ルール

本書は以下の場合に更新する。

- ソフトウェア構成変更
- モジュール追加・削除
- システム構成変更
- モジュール責務変更
- データフロー変更
- 文書体系変更

日常的な実装進捗は記載しない。

現在の進捗は **CURRENT_STATUS.md** を正式情報とする。

---

# 自己査読チェックリスト

- [x] 文書内矛盾なし
- [x] READMEとの責務分離
- [x] CURRENT_STATUSとの責務分離
- [x] ROADMAPとの責務分離
- [x] 00_PROJECT_CONVENTIONSとの整合
- [x] 03_LOG_FORMATとの責務分離
- [x] 04_STATE_MACHINEとの責務分離
- [x] 06_GAS_API_SPECとの責務分離
- [x] 19_GEMINI_PROMPT_SPECIFICATIONとの責務分離
- [x] STATUS表記統一
- [x] Single Source of Truth維持
- [x] GitHub表示崩れなし
- [x] vNext 1.3文書体系へ適合

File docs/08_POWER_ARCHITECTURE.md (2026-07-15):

# 08 Power Architecture

**タイトル**  
08 Power Architecture

**最終更新**  
2026-07-15

**文書版**  
vNext 1.3

**STATUS**  
FINALIZED

**責務**  
本書は digital-kakejiku の電源システム全体、電源アーキテクチャ、UPS構成、電源供給方針および電源インターフェースを定義する正式設計書である。

**Single Source**  
本書は電源設計を管理する唯一の文書である。

電源構成、UPS構成、電圧系統、GND構成および電源供給方針は本書を正式情報とし、他文書では重複管理しない。

---

# 対象読者

- ハードウェア設計者
- 基板製作担当者
- 保守担当者

---

# 関連文書

## 前提

- docs/00_PROJECT_CONVENTIONS.md

## 参照

- README.md
- CURRENT_STATUS.md
- ROADMAP.md

## 関連

- docs/01_HARDWARE_OVERVIEW.md
- docs/05_WIRING_DIAGRAM.md
- docs/09_SPI_RESOURCE_CONTROL.md

## 後続

- 電源基板製作
- 本体基板接続
- システム統合試験

---

# 1. 文書の目的

本書はシステム全体の電源設計を定義する。

本書では以下を管理する。

- 電源構成
- UPS構成
- 電源供給方式
- 電圧系統
- GND構成
- 電源インターフェース

回路定数やPCBレイアウトの詳細は管理しない。

---

# 2. 電源設計方針

本システムでは以下を基本方針とする。

- UPS構成を採用する。
- 電源基板を独立させる。
- 本体基板と電源基板をコネクタ接続する。
- 電源品質を優先する。
- 保守性を優先する。
- Single Source of Truth を維持する。

---

# 3. 電源構成

```text
USB Type-C
      │
     PTC
      │
    IP5306
      │
DMG2305UX-13
      │
    5V_BUS
      │
   TPS63802
      │
  3.3V_OUT
      │
  Main Board
```

本構成をシステムの正式な電源アーキテクチャとする。

---

# 4. 電源ブロック

|ブロック|役割|STATUS|
|---|---|---|
|USB入力|外部給電|CONFIRMED|
|UPS|停電対策|CONFIRMED|
|5V系|主電源|CONFIRMED|
|3.3V系|ロジック電源|CONFIRMED|
|SENSE系|電圧監視|CONFIRMED|

---

# 5. UPS構成

本システムでは、停電時も継続動作可能なUPS構成を採用する。

詳細回路は本書を正式情報とし、各部品仕様は回路図および部品資料を参照する。

---

## 5.1 構成

|部品|役割|STATUS|
|---|---|---|
|USB Type-C|外部電源入力|CONFIRMED|
|PTC Fuse|過電流保護|CONFIRMED|
|IP5306|充電・UPS制御|CONFIRMED|
|18650 Li-ion Battery|バックアップ電源|CONFIRMED|
|DMG2305UX-13|逆流防止|CONFIRMED|
|TPS63802|5V→3.3V電源生成|CONFIRMED|

---

## 5.2 動作概要

### USB接続時

- USBからシステムへ給電する。
- IP5306により18650セルを充電する。
- システムはUSB電源を優先して使用する。

---

### USB切断時

- 18650セルからUPS給電へ切り替える。
- システム動作を継続する。
- 手動操作を必要としない。

---

# 6. 電圧系統

本システムでは用途ごとに電圧系統を分離する。

---

## 6.1 電源系統

|名称|用途|
|---|---|
|VBUS|USB入力|
|5V_BUS|電源基板内部5V|
|5V_OUT|本体基板供給5V|
|3.3V_OUT|本体基板供給3.3V|

---

## 6.2 GND系統

設計上は以下の3系統を独立して配線する。

|名称|用途|
|---|---|
|5V_GND|5V系リターン|
|3.3V_GND|3.3V系リターン|
|SENSE_GND|ADC基準リターン|

設計上は本体基板まで独立配線とし、システムGNDは本体基板上で一点接続する。

---

## 6.3 SENSE系

|信号|用途|
|---|---|
|Battery_SENSE|バッテリー電圧監視|
|5V_SENSE|5V監視|

SENSE配線は測定専用とし、大電流経路として使用しない。

---

# 7. 電源供給

本体基板への電源供給は専用ヘッダーを使用する。

---

## 7.1 接続信号

|信号|用途|
|---|---|
|5V_OUT|主電源|
|5V_GND|5Vリターン|
|3.3V_OUT|ロジック電源|
|3.3V_GND|ロジックGND|
|Battery_SENSE|電池監視|
|5V_SENSE|5V監視|
|SENSE_GND|ADC基準|

---

## 7.2 設計方針

- 電源基板を独立させる。
- コネクタ接続を基本とする。
- 電源供給経路を明確にする。
- 保守時の交換を容易にする。

---

# 8. 電源監視

電源状態はESP32のADCで監視する。

---

## 8.1 監視対象

|監視対象|STATUS|
|---|---|
|Battery Voltage|CONFIRMED|
|5V Voltage|CONFIRMED|

---

## 8.2 基本方針

- 電源状態を定期監視する。
- 異常時はログへ記録する。
- 必要に応じて表示へ反映する。

監視アルゴリズムはソフトウェア設計書を正式情報とする。

---

# 9. 電源品質設計

本章では、システム全体の電源品質を維持するための設計方針を定義する。

回路定数や部品配置の詳細は回路図およびPCB設計データを正式情報とする。

---

## 9.1 ノイズ対策

以下を基本方針とする。

- 電源配線を可能な限り短くする。
- デカップリングコンデンサを対象IC近傍へ配置する。
- 電源配線と高速信号線を可能な範囲で分離する。
- 電源基板と本体基板を分離し、ノイズ源を局所化する。

---

## 9.2 GND設計

本システムでは設計上、以下の方針を採用する。

- 5V_GND
- 3.3V_GND
- SENSE_GND

を電源基板上では独立して配線する。

本体基板側でシステムGNDとして一点接続する。

この分離は電位分離ではなく、リターン経路の整理によるノイズ低減を目的とする。

---

## 9.3 デカップリング

基本方針

- 各電源IC近傍へ配置する。
- 高周波用とバルク容量を組み合わせる。
- 詳細な容量・配置は回路設計を正式情報とする。

---

# 10. インターフェース

本章では電源基板と他モジュールとの接続方針を定義する。

---

## 10.1 USB入力

|項目|内容|
|---|---|
|コネクタ|USB Type-C|
|用途|給電・開発・デバッグ|

USB Type-C基板の CC 抵抗は使用する基板に実装済みとし、本システムでは追加実装を行わない。

---

## 10.2 本体基板接続

本体基板とは専用ヘッダーで接続する。

|信号|用途|
|---|---|
|5V_OUT|5V供給|
|5V_GND|5Vリターン|
|3.3V_OUT|3.3V供給|
|3.3V_GND|3.3Vリターン|
|Battery_SENSE|電池監視|
|5V_SENSE|5V監視|
|SENSE_GND|ADC基準|

---

## 10.3 USB通信

USB通信は XIAO ESP32S3 Plus の書込みおよびデバッグ用途とする。

設計方針

- USB D+ と D- はヘッダーピン経由で本体基板へ接続する。
- 電源配線とは可能な範囲で分離する。
- USB通信線を不要に延長しない。

---

# 11. 保守設計

保守性向上のため以下を採用する。

- 電源基板を独立モジュール化する。
- コネクタ交換のみで基板交換可能とする。
- 電圧測定ポイントを設ける。
- 電源経路を追跡しやすい構成とする。

---

# 12. 設計方針

電源設計は以下を設計原則とする。

## 安定性

- 安定した5Vおよび3.3V供給を行う。
- 電源切替時にシステム停止しない。
- ノイズの影響を最小化する。

---

## 保守性

- モジュール交換を容易にする。
- 配線識別を容易にする。
- 電圧測定を容易にする。

---

## 拡張性

- 将来のセンサー追加へ対応する。
- 電源容量に余裕を持たせる。
- 電源監視機能を拡張可能とする。

---

# 13. 制約事項

本章では電源アーキテクチャ設計における制約事項を定義する。

本書では電源システム全体の設計方針を対象とし、部品実装やPCBアートワークの詳細は対象外とする。

---

## 13.1 本書で定義しない事項

|項目|管理文書|
|---|---|
|回路図|回路図ファイル|
|PCBレイアウト|PCB設計データ|
|部品配置|PCB設計データ|
|部品定数|回路設計資料|
|実測値|試験結果|
|配線経路|05_WIRING_DIAGRAM.md|

---

## 13.2 設計制約

以下を設計制約とする。

- UPS構成を変更しない。
- 電源基板を独立モジュールとする。
- システムGNDは本体基板側で一点接続する。
- 電源系と信号系を可能な範囲で分離する。
- 電源監視は Battery_SENSE および 5V_SENSE を使用する。

---

# 14. 将来拡張

本章では将来的に追加を検討する電源機能を示す。

本章は構想であり、実装を保証するものではない。

---

## 14.1 電源機能

|項目|STATUS|備考|
|---|---|---|
|バッテリー容量拡張|PROPOSED|詳細未定|
|消費電力解析|PROPOSED|詳細未定|
|電源診断機能|PROPOSED|詳細未定|
|異常通知機能|PROPOSED|詳細未定|
|保守支援機能|PROPOSED|詳細未定|

---

## 14.2 保守性向上

将来的に以下を検討する。

- 電源自己診断
- 詳細電圧監視
- 保守用テストモード
- 長期劣化監視

詳細は今後決定する。

---

# 15. 未定義事項

本書では以下を定義しない。

|項目|状態|
|---|---|
|PCB層構成|今後決定|
|配線幅一覧|PCB設計データで管理|
|製造公差|今後決定|
|量産仕様|未定義|
|EMC評価方法|今後決定|

---

# CHANGE LOG

|日付|内容|
|---|---|
|2026-07-15|vNext 1.3文書体系に合わせ全面刷新。電源設計文書として再設計し、README・CURRENT_STATUS・ROADMAP・01_HARDWARE_OVERVIEW・05_WIRING_DIAGRAMとの責務を明確化。Single Source of Truthに基づき、UPS構成・電圧系統・GND設計・電源供給方針を整理し、STATUS表記・文書構成を共通規約へ統一。|
|2026-07-14|電源基板PoC結果、UPS切替試験結果、USB D+/D-ヘッダーピン経由方針を反映。|
|2026-07-13|GND分離設計および電源供給方針を更新。|

---

# 付録A. 関連文書の責務

|文書|責務|
|---|---|
|README.md|プロジェクト概要・入口|
|CURRENT_STATUS.md|現在の開発状況|
|ROADMAP.md|中長期計画|
|01_HARDWARE_OVERVIEW.md|ハードウェア全体構成|
|05_WIRING_DIAGRAM.md|配線仕様|
|08_POWER_ARCHITECTURE.md|電源設計（本書）|
|09_SPI_RESOURCE_CONTROL.md|SPIバス設計|

---

# 付録B. 更新ルール

本書は以下の場合に更新する。

- 電源構成変更
- UPS構成変更
- 電圧系統変更
- GND設計変更
- 電源インターフェース変更
- 文書体系変更

日常的な試験結果や進捗は記載しない。

現在の開発状況は **CURRENT_STATUS.md** を正式情報とする。

---

# 自己査読チェックリスト

- [x] 文書内矛盾なし
- [x] READMEとの責務分離
- [x] CURRENT_STATUSとの責務分離
- [x] ROADMAPとの責務分離
- [x] 00_PROJECT_CONVENTIONSとの整合
- [x] 01_HARDWARE_OVERVIEWとの責務分離
- [x] 05_WIRING_DIAGRAMとの責務分離
- [x] STATUS表記統一
- [x] Single Source of Truth維持
- [x] GitHub表示崩れなし
- [x] vNext 1.3文書体系へ適合

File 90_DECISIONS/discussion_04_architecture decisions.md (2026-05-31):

# 電源アーキテクチャ決定（UPS対応版）

## 概要

digital-kakejiku の電源構成を確定した。

本機は据置型観測装置として運用し、通常時はUSB給電、停電時は18650リチウムイオン電池へ自動切替して継続動作することを目的とする。

開発時および運用時におけるヒューマンエラーを排除するため、手動切替は採用しない。

---

## 採択構成

```text
USB-C
↓
IP5306
↓ 5V
TPS63802
↓ 3.3V
P-MOSFET逆流防止回路
↓
3.3V BUS
↓
XIAO ESP32S3 Plus
SCD41
SGP41
SPS30
LTR390
BME680
MCP23017
RTC
```

---

## 採択理由

### IP5306

採択理由

* 18650充電機能を持つ
* USB給電とバッテリー給電の自動切替が可能
* UPS用途との親和性が高い
* 初号機での実装負荷を下げられる

不採択

* TP4056単独構成

理由

* UPS用途に適さない
* 負荷接続状態での運用に制約がある
* 停電時のシームレス切替が困難

---

### TPS63802

採択理由

* 既に手元にある
* 既存開発環境を流用できる
* 全センサーを3.3V系で統一可能
* XIAOとの実績がある

役割

* 5V → 3.3V変換
* 電圧安定化

---

### P-MOSFET逆流防止方式

採択理由

* 手動操作不要
* ヒューマンエラー排除
* ショットキーダイオード方式より損失が少ない
* Power MUX ICより構成が簡潔

不採択

* 手動切替
* ショットキーダイオード単独
* Power MUX IC

---

## 運用方針

### 通常時

```text
USB-C
↓
IP5306
↓
TPS63802
↓
3.3V BUS
↓
システム稼働
```

### 停電時

```text
18650
↓
IP5306
↓
TPS63802
↓
3.3V BUS
↓
システム継続稼働
```

利用者による操作は不要とする。

---

## 今後のタスク

### 優先度A

* IP5306実機評価
* 電源回路図作成
* P-MOSFET型番選定
* 停電切替試験

### 優先度B

* 長時間連続運転試験
* 消費電流測定
* バッテリー駆動時間測定

### 優先度C

* 将来的なPower MUX採用再評価

---

## 決定事項

採択済み

* 18650
* IP5306
* TPS63802
* UPS構成
* P-MOSFET逆流防止

未確定

* IP5306具体型番
* P-MOSFET具体型番
* RTC具体型番
* RTCバックアップ電池形式

以上を現時点の正式設計方針とする。

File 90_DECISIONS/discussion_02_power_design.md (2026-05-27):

# Discussion: 電源設計方針

## 概要

本プロジェクトは据置型運用を前提とする。

そのため、
小型LiPoよりも：

```text
18650 Li-ion
```

を主電源候補とする。

---

# 想定構成

```text
USB 5V
↓
TP4056
↓
18650 Li-ion
↓
TPS63802
↓
ESP32 / Sensors / Display
```

---

# この構成を採用する理由

## 1. 長期安定運用

ESP32 + WiFi + HTTPS は
瞬間電流変動が大きい。

18650の方が余裕を持ちやすい。

---

## 2. 据置用途との相性

本プロジェクトは：

- 携帯用途ではない
- 超小型化不要
- 厚み制約が緩い

ため、
18650と相性が良い。

---

## 3. 入手性

18650関連部材は：

- AliExpress
- Amazon
- 秋月
- 淘宝

などで広く入手可能。

---

# TP4056採用理由

## 採用理由

- 安価
- 実績豊富
- モジュール流通量が多い

## 注意点

保護回路有無を確認する必要がある。

---

# TPS63802採用理由

## 採用理由

- 昇降圧
- ESP32 WiFiピーク対策
- 電池電圧低下耐性

## 方針

電源安定化を最優先とする。

---

# 現時点で重要視していること

## 最優先

```text
Serial Monitorで安定観測できること
```

## 理由

ESP32系では：

- 電源不安定
- WiFi瞬断
- HTTPS失敗
- 謎リセット

が切り分け困難化しやすいため。

---

# 現在の考え方

```text
電源を固める
↓
通信を固める
↓
Serialで観測
↓
センサ統合
```

を基本順序とする。

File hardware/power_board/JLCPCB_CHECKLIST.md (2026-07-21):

# JLCPCB発注前チェックリスト

## 回路図

- [ ] USB-C基板の端子順を実物確認
- [ ] IP5306モジュールの端子順を実物確認
- [ ] TPS63802モジュールの端子順を実物確認
- [ ] DMG2305UX-13のGate/Source/Drainを確認
- [ ] PTC定格を確定
- [ ] 電解コンデンサ耐圧を確定
- [ ] ERCエラー0
- [ ] ERC警告の採否を記録

## PCB

- [ ] 全フットプリントを実測値へ更新
- [ ] 1:1印刷で実物を重ね合わせ
- [ ] コネクタ挿抜空間を確認
- [ ] 取付穴を筐体図面と照合
- [ ] 5V主電源パターン幅を確定
- [ ] 3.3V主電源パターン幅を確定
- [ ] SENSE配線を大電流経路から分離
- [ ] USB D+/D-を短く並走
- [ ] DRCエラー0
- [ ] 未配線0

## GND

- [ ] 5V_GNDを確認
- [ ] 3.3V_GNDを確認
- [ ] SENSE_GNDを確認
- [ ] TPS63802モジュール内部GND導通を実測
- [ ] IP5306モジュール内部GND導通を実測
- [ ] 意図しない基板上の一点接続がないことを確認

## 製造データ

- [ ] Edge.Cutsが閉じている
- [ ] Gerber Viewerで全層確認
- [ ] Drillファイル確認
- [ ] シルクがパッドへ重なっていない
- [ ] 極性・1番ピン表示を確認
- [ ] 製造注文番号印字位置を指定
- [ ] 基板寸法を確認
- [ ] 発注枚数を確認

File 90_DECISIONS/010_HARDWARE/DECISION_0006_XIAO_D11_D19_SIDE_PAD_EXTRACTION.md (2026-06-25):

# DECISION_0006: XIAO D11〜D19側面ランド取り出し方針

作成日: 2026-06-25  
対象プロジェクト: digital-kakejiku  
分類: HARDWARE  
状態: ADOPTED

---

# 1. 決定事項

XIAO ESP32S3 Plus の追加GPIO取り出しについて、以下を採択する。

```text
XIAO ESP32S3 Plus は1台構成を維持する。
ePaperドライバーボード装着時に使用困難となる裏面ランドは使用禁止とする。
D11〜D19に相当する1.27mm側面ランドは使用解禁とする。
D11〜D19は、信号線＋GNDのペアとして本体基板へ接続する。
```

---

# 2. 採択方針

## 2.1 MCU構成

| 項目 | 決定 |
|---|---|
| MCU | Seeed XIAO ESP32S3 Plus |
| MCU台数 | 1台 |
| 2台構成 | 初号機では不採択。フォールバックとして記録のみ |
| ePaper接続 | XIAO ePaper Breakout V2 / ePaperドライバーボード経由 |
| 裏面ランド | 使用禁止 |
| 1.27mm側面ランド | 使用解禁 |
| D11〜D19 | 1.27mm側面ランドに相当し、使用可 |

## 2.2 ePaperドライバーボード配置

7.5inch ePaper本体には長めのリボンケーブルが付属しているため、ePaperドライバーボードおよびXIAOをePaper本体直近に固定する必要はない。

したがって、以下を採択する。

```text
ePaper本体
  ↓ 付属リボンケーブル
ePaperドライバーボード + XIAO ESP32S3 Plus
  ↓ 短距離接続
大型本体基板
```

この配置により、D11〜D19側面ランドから大型本体基板までの配線長を短くできる。

---

# 3. D11〜D19取り出し用ミニ基板

## 3.1 役割

D11〜D19取り出し用ミニ基板は、部品実装基板ではなく、以下に特化したアダプタとして扱う。

- D11〜D19側面ランドの信号取り出し
- XIAO GNDの取り出し
- 小規模GNDバスの形成
- 信号線＋GNDのJST 2ピン化
- 本体基板への短距離接続

## 3.2 載せるもの

| 対象 | 方針 |
|---|---|
| D11〜D19信号配線 | 載せる |
| XIAO由来GND | 載せる |
| 小規模GNDバス | 載せる |
| JST 2ピンコネクタ | 載せる |
| GPIO番号ラベル | 推奨 |

## 3.3 原則載せないもの

| 対象 | 方針 | 理由 |
|---|---|---|
| プルアップ抵抗 | 原則載せない | D11〜D19用途未確定のため |
| プルダウン抵抗 | 原則載せない | D11〜D19用途未確定のため |
| RCフィルタ | 原則載せない | ADC用途確定後に判断するため |
| 大型コンデンサ | 載せない | ミニ基板へ機械的・電気的負荷をかけないため |
| 電源系部品 | 載せない | 大電流経路から分離するため |
| 大電流GND配線 | 載せない | 信号用GNDと電源帰路を混在させないため |

---

# 4. JST 2ピン接続方針

D11〜D19は、各GPIOごとにJST 2ピンで取り出す。

| JST | Pin1 | Pin2 | ケーブル |
|---|---|---|---|
| JST-D11 | D11 | GND | D11 + GND 撚り線 |
| JST-D12 | D12 | GND | D12 + GND 撚り線 |
| JST-D13 | D13 | GND | D13 + GND 撚り線 |
| JST-D14 | D14 | GND | D14 + GND 撚り線 |
| JST-D15 | D15 | GND | D15 + GND 撚り線 |
| JST-D16 | D16 | GND | D16 + GND 撚り線 |
| JST-D17 | D17 | GND | D17 + GND 撚り線 |
| JST-D18 | D18 | GND | D18 + GND 撚り線 |
| JST-D19 | D19 | GND | D19 + GND 撚り線 |

各JSTにはGPIO番号を明示する。

```text
JST-D11: Pin1=D11 / Pin2=GND
JST-D12: Pin1=D12 / Pin2=GND
...
JST-D19: Pin1=D19 / Pin2=GND
```

---

# 5. GND接続方針

## 5.1 ミニ基板側

D11〜D19取り出し用ミニ基板には、XIAO由来のGNDを取り込み、小規模GNDバスを設ける。

```text
XIAO GND
  ↓
D11〜D19取り出し用ミニ基板 GNDバス
  ├─ JST-D11 GND
  ├─ JST-D12 GND
  ├─ ...
  └─ JST-D19 GND
```

このGNDは、信号の戻り道、基準電位、ノイズ対策のために使用する。

## 5.2 本体基板側

本体基板側JSTのGNDは、本体基板のGNDバスへ直結する。

```text
JST-D11 Pin2 GND
  ↓
本体基板 GNDバス
```

ただし、以下は行わない。

- SPS30の大電流帰路をD11〜D19用GNDへ流す
- DC-DCの大電流帰路をD11〜D19用GNDへ流す
- ePaper更新時の電源帰路をD11〜D19用GNDへ流す
- D11〜D19用GNDを電源GNDの数珠つなぎ経路にする

---

# 6. 抵抗・ノイズ対策の扱い

D11〜D19の用途が未確定であるため、初期段階ではミニ基板上に抵抗を実装しない。

採択方針。

```text
D11〜D19ミニ基板は、信号線とGNDの取り出しに特化する。
抵抗、RC、プルアップ、プルダウンは、用途確定後に本体基板側または信号源側で設計する。
```

将来の考え方は以下とする。

| 用途 | 抵抗・部品の基本配置 |
|---|---|
| GPIO出力 | 信号源側に直列抵抗を検討 |
| GPIO入力 | 受け側入力近くにプルアップ/プルダウンを検討 |
| SPI CS | 非選択固定用プルアップを検討 |
| 割り込み線 | 受け側でプルアップを検討 |
| ADC | 分圧抵抗とRCフィルタを入力近傍に検討 |
| I2C | バス全体で1組のプルアップ。重複に注意 |

---

# 7. 信号品質方針

D11〜D19は、長距離空中配線を前提にしない。  
ただし、ノイズ対策として以下を維持する。

| 対策 | 方針 |
|---|---|
| 信号線とGNDのペア化 | 採択 |
| 信号線＋GNDの撚り線 | 採択 |
| JST 2ピン単位のラベル明示 | 採択 |
| DC-DC電源線との並走回避 | 推奨 |
| SPS30ファン電源線との並走回避 | 推奨 |
| ePaper電源線との並走回避 | 推奨 |
| 直列抵抗 | 必要時に用途確定後対応 |

---

# 8. 電源関連の同時決定

## 8.1 SPS30電源

SPS30の動作電圧は以下で確定する。

```text
SPS30動作電圧: 3.5V〜5.0V
供給元: 5V BUS
```

注意点。

- SPS30は3.3V BUSへ接続しない。
- SPS30は5V BUS負荷として扱う。
- I2Cプルアップ先はXIAOに合わせて3.3V系に統一する。

## 8.2 逆流防止Pch MOSFET

初号機では、手元在庫を優先し、DMG3415Uを採択する。

| 項目 | 決定 |
|---|---|
| 初号機採用品 | DMG3415U |
| 用途 | 5V BUS逆流防止用 Pch MOSFET |
| 代替候補 | DMG2305UX-13 |
| ヒートシンク | 原則不要 |
| 放熱方針 | 銅箔放熱と実測確認を優先 |
| 確認対象 | SPS30動作時、ePaper更新時、Wi-Fi送信時、BATTERY_MODE時 |

---

# 9. 影響を受ける文書

| 文書 | 反映内容 |
|---|---|
| README.md | 採択済み構成の概要更新 |
| CURRENT_STATUS.md | 現在状態、採択済みハードウェア、未確定事項更新 |
| ROADMAP.md | Phase 2前確認事項へD11〜D19取り出し検証等を追加 |
| 01_HARDWARE_OVERVIEW.md | GPIO方針、D11〜D19、DMG3415U、SPS30電圧を反映 |
| 05_WIRING_DIAGRAM.md | JST 2ピン、GNDバス、撚り線、本体GND接続を追加 |
| 07_DISPLAY_UI_SPEC.md | ePaperリボンケーブルとドライバーボード配置方針を追加 |
| 08_POWER_ARCHITECTURE.md | DMG3415U採択、SPS30 5V BUS、発熱確認方針を反映 |
| 09_SPI_RESOURCE_CONTROL.md | ePaper物理配置変更はSPI排他制御に影響しない旨を補足 |

---

# 10. 未確定事項

| 項目 | 状態 | 備考 |
|---|---|---|
| D11〜D19の個別PIN割当 | 未確定 | ePaper、SPI、I2S、起動条件と競合確認が必要 |
| JST規格 | 未確定 | JST-SH/GH/PH等から実装性で決定 |
| ICS-43434 I2S再割当 | 未確定 | 裏面ランド禁止により再設計が必要 |
| IP5306実装モジュール | 未確定 | Phase 2 PoC前に確定 |
| USB Presence検出方法 | 未確定 | ADC分圧等を含め検討 |
| Battery Voltage測定方法 | 未確定 | ADC分圧等を含め検討 |
| LD2410C電源電圧 | 未確定 | 実機確認 |

---

# 11. 決定理由

- ePaperドライバーボード装着時、XIAO裏面ランドは物理的に使用困難である。
- 1.27mm側面ランドはD11〜D19に相当し、追加GPIO取り出し先として利用できる。
- ePaper本体付属の長めリボンケーブルにより、ドライバーボード＋XIAOを本体基板近傍へ配置できる。
- D11〜D19の長距離空中配線を避けられるため、信号品質と機械的安定性が改善する。
- 各信号をGNDと2線ペア化することで、戻り電流経路を明確化できる。
- JST 2ピン単位にすることで、GPIO番号の明示、誤配線防止、保守性が向上する。
- 用途未確定段階で抵抗類をミニ基板へ載せると、後工程で不整合が生じる可能性がある。

---

# 12. STATUS

```text
ADOPTED
```

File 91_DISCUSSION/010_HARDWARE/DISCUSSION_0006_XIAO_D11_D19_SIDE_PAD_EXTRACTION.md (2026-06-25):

# DISCUSSION_0006: XIAO D11〜D19側面ランド取り出し・GND・JST・ノイズ対策検討

作成日: 2026-06-25  
対象プロジェクト: digital-kakejiku  
分類: HARDWARE  
状態: RECORDED

---

# 1. 議論の目的

本書は、digital-kakejiku 初号機における XIAO ESP32S3 Plus のGPIO取り出し方針、D11〜D19側面ランドの扱い、GNDの取り方、JST 2ピン接続、ノイズ対策、関連する電源部品変更を記録する。

本議論は、以下の方針変更を受けて整理したものである。

- ePaperドライバーボード装着時、XIAO裏面ランドが使用困難である。
- 1.27mm側面ランドはD11〜D19に相当する。
- D11〜D19側面ランドは使用解禁とする。
- ePaper本体には長めのリボンケーブルが付属しており、ドライバーボード＋XIAOを本体基板近傍へ配置できる。
- D11〜D19は、長距離空中配線ではなく短距離接続を前提に再整理する。

---

# 2. 背景

当初、XIAO ESP32S3 Plus のGPIO不足対策として、裏面ランドの使用を前提としていた。  
しかし、XIAOをePaperドライバーボードへ装着すると、裏面ランドへ物理的にアクセスできないことが判明した。

その後、1.27mm側面ランドがD11〜D19に相当することを確認し、側面ランドを追加GPIO取り出しに利用する方針へ変更した。

さらに、ePaper本体に長めのリボンケーブルが付属していることを確認したため、ePaperドライバーボード＋XIAOを本体基板近傍へ配置できる見込みとなった。

この結果、D11〜D19を20〜30cmの長距離空中配線として扱う必要性は低下した。

---

# 3. 検討した構成

## 3.1 旧案: 裏面ランド使用

```text
XIAO裏面ランド
  ↓
追加GPIO取り出し
```

不採択理由。

- ePaperドライバーボード装着時に裏面ランドへアクセスできない。
- 物理実装が困難である。
- ドキュメント上の「裏面ランド使用可」前提を廃止する必要がある。

## 3.2 旧案: XIAO 2台構成

```text
XIAO-A: ePaper / GAS / 表示
XIAO-B: センサー / UI / RTC / microSD
```

不採択理由。

- MCU間通信が必要になる。
- 電源投入順、時刻同期、ログ統合が複雑化する。
- ファームウェア管理が二重化する。
- 初号機の故障点が増える。

結論。

```text
初号機ではXIAO 1台構成を維持する。
2台構成はフォールバック案としてのみ記録する。
```

## 3.3 採択案: D11〜D19側面ランド取り出し

```text
XIAO D11〜D19側面ランド
  ↓
D11〜D19取り出し用ミニ基板
  ↓
JST 2ピン 信号 + GND
  ↓
撚り線
  ↓
大型本体基板
```

採択理由。

- 裏面ランドを使わずにGPIOを取り出せる。
- XIAO 1台構成を維持できる。
- ePaperドライバーボード＋XIAOを本体基板近傍へ配置できるため、配線長を短縮できる。
- 信号線とGNDをペア化できる。
- GPIO番号をJSTごとに明示できる。

---

# 4. D11〜D19取り出し用ミニ基板の考え方

## 4.1 役割

D11〜D19取り出し用ミニ基板は、信号取り出し専用とする。

```text
役割:
  - D11〜D19信号線の取り出し
  - XIAO GNDの取り出し
  - 小規模GNDバスの形成
  - JST 2ピン化
```

## 4.2 使途未確定段階で抵抗を載せない理由

D11〜D19の用途は、現時点では未確定である。  
用途が未確定の段階で直列抵抗、プルアップ、プルダウン、RCフィルタを載せると、後から用途に合わない可能性がある。

したがって、ミニ基板は以下に特化する。

```text
信号線取り出し
GND取り出し
JST 2ピン化
```

抵抗類は、用途が確定した後、本体基板側または信号源側で設計する。

## 4.3 将来の抵抗配置の整理

| 信号用途 | 抵抗・部品 | 基本配置 |
|---|---|---|
| GPIO出力 | 直列抵抗 | 信号源側 |
| GPIO入力 | プルアップ/プルダウン | 受け側入力近く |
| SPI CS | プルアップ | 対象デバイス側または本体基板側 |
| SPI SCK/MOSI | 直列抵抗 | XIAO側または信号源側 |
| SPI MISO | 直列抵抗 | microSD等の出力側 |
| 割り込み線 | プルアップ | 受け側近傍 |
| ADC | 分圧抵抗 + RC | ADC入力近傍 |
| I2C | プルアップ | バス全体で1組、3.3Vへ |

---

# 5. GNDの検討

## 5.1 GNDは信号の戻り道である

信号線は単独で動作するものではなく、必ず戻り電流の経路を持つ。  
信号線とGNDが離れていると、ループ面積が大きくなり、ノイズを拾いやすくなる。

このため、D11〜D19では、信号線とGNDをペア化する方針とした。

## 5.2 ミニ基板上のGNDバス

ミニ基板には、XIAO由来のGNDを取り込み、小規模GNDバスを設ける。

```text
XIAO GND
  ↓
ミニ基板 GNDバス
  ├─ JST-D11 GND
  ├─ JST-D12 GND
  ├─ ...
  └─ JST-D19 GND
```

このGNDは信号用GNDであり、大電流帰路ではない。

## 5.3 本体基板側GND

本体基板側JSTのGNDは、本体基板GNDバスへ直結する。

```text
JST-D11 GND
  ↓
本体基板 GNDバス
```

ただし、以下は避ける。

```text
JST-D11 GND
  ↓
JST-D12 GND
  ↓
SPS30 GND
  ↓
DC-DC GND
```

これはGNDの数珠つなぎであり、信号GNDに電源変動が乗る可能性がある。

推奨は以下である。

```text
各JST GND
  ↓
本体基板 信号用GNDバス
  ↓
本体基板 共通GND
  ↓
電源GND基準点
```

---

# 6. JST 2ピン方式の検討

## 6.1 採択理由

D11〜D19を1本の多ピンコネクタでまとめる案も考えられる。  
しかし、初号機ではJST 2ピンをGPIOごとに分ける方式を優先する。

理由。

- 各コネクタにD11、D12等のGPIO番号を明示できる。
- 信号線とGNDが常に1組になる。
- テスターでの導通確認が容易である。
- 誤配線時の切り分けが容易である。
- 1信号単位で着脱・交換できる。
- 初号機では小型化より保守性を優先する。

## 6.2 接続ルール

| JST | Pin1 | Pin2 |
|---|---|---|
| JST-D11 | D11 | GND |
| JST-D12 | D12 | GND |
| JST-D13 | D13 | GND |
| JST-D14 | D14 | GND |
| JST-D15 | D15 | GND |
| JST-D16 | D16 | GND |
| JST-D17 | D17 | GND |
| JST-D18 | D18 | GND |
| JST-D19 | D19 | GND |

Pin1は信号、Pin2はGNDに統一する。

## 6.3 ケーブル

各JSTから本体基板までは、信号線＋GNDを撚り線とする。

```text
D11 + GND 撚り線
D12 + GND 撚り線
...
D19 + GND 撚り線
```

この構成により、信号ループ面積を小さくし、ノイズ耐性を高める。

---

# 7. ノイズ対策の整理

D11〜D19は短距離接続を前提とするが、ノイズ対策は不要にはならない。

| 対策 | 判断 | 備考 |
|---|---|---|
| 信号線＋GNDペア | 採択 | 基本方針 |
| 撚り線 | 採択 | 筐体内配線のノイズ低減 |
| 本体基板近傍配置 | 採択 | 配線短縮 |
| DC-DCから距離確保 | 推奨 | TPS63802、IP5306周辺に注意 |
| SPS30ファン電源線から距離確保 | 推奨 | 5V系の負荷変動に注意 |
| ePaper電源線から距離確保 | 推奨 | 更新時の電流変動に注意 |
| 直列抵抗 | 必要時 | 用途確定後に判断 |
| プルアップ/プルダウン | 必要時 | 入力用途確定後に判断 |
| ADC RCフィルタ | 必要時 | 電圧監視用途確定後に判断 |

---

# 8. ePaper配置の再整理

当初、ePaperドライバーボードはePaper本体近傍に配置される前提だった。  
その場合、D11〜D19から本体基板まで20〜30cm程度の空中配線になる可能性があった。

しかし、ePaper本体には長めのリボンケーブルが付属しているため、以下が可能となった。

```text
ePaper本体
  ↓ 付属リボンケーブル
ePaperドライバーボード + XIAO
  ↓ 短距離接続
大型本体基板
```

この変更により、D11〜D19を長距離ハーネスではなく、短距離の基板間接続として扱える。

注意点。

- ePaperリボンケーブルを無理に折り曲げない。
- リボンケーブルに機械的ストレスをかけない。
- ePaper更新時の電源変動を5V/3.3V設計で確認する。
- SPI共有制御の論理方針は変更しない。

---

# 9. I2S再検討

現行文書では、ICS-43434のI2S信号としてGPIO39、GPIO40、GPIO41を使用する前提が残っている。  
これは裏面ランド使用前提の割当である。

裏面ランドを使用禁止としたため、I2S割当は再検討が必要である。

未確定事項。

- ICS-43434を初号機で維持するか
- I2S信号をD11〜D19へ割り当てるか
- I2S信号を別GPIOへ割り当てるか
- マイク配置をXIAO近傍へ寄せられるか
- 音環境観測をPhase後半へ延期するか

現時点では、I2Sは高速寄りのクロック信号を含むため、D11〜D19への割当は慎重に扱う。

---

# 10. SPS30電源検討

SPS30の動作電圧は3.5V〜5.0Vで確定した。  
このため、SPS30は5V BUS負荷として扱う。

```text
IP5306
  ↓
5V BUS
  ├─ SPS30
  └─ TPS63802
       ↓
     3.3V BUS
```

注意点。

- SPS30を3.3V BUSに接続しない。
- SPS30のGND帰路は大電流側として太めに本体基板GNDへ戻す。
- D11〜D19用GNDをSPS30の帰路に使わない。
- I2Cプルアップ先は3.3Vに統一する。

---

# 11. DMG3415U採択検討

当初、逆流防止Pch MOSFETとしてDMG2305UX-13を採択していた。  
手元在庫としてDMG3415Uがあるため、初号機ではDMG3415Uを採択する。

| 項目 | 判断 |
|---|---|
| 初号機採用品 | DMG3415U |
| 代替候補 | DMG2305UX-13 |
| 用途 | 5V BUS逆流防止 |
| ヒートシンク | 原則不要 |
| 放熱 | 銅箔面積と実測で確認 |
| 長期BOM | 再評価対象 |

実測対象。

- SPS30動作時
- ePaper更新時
- Wi-Fi送信時
- BATTERY_MODE時
- 5V BUS電圧降下
- MOSFET表面温度

---

# 12. 本議論で得た設計ルール

```text
1. 裏面ランドは使用禁止。
2. 1.27mm側面ランド、すなわちD11〜D19は使用解禁。
3. D11〜D19は長距離空中配線にしない。
4. ePaperドライバーボード＋XIAOは本体基板近傍へ配置する。
5. D11〜D19取り出し用ミニ基板は信号線＋GND取り出し専用とする。
6. ミニ基板には小規模GNDバスを設ける。
7. D11〜D19はJST 2ピンで信号＋GNDペア化する。
8. JSTケーブルは信号線＋GNDの撚り線とする。
9. 本体基板側JSTのGNDは本体基板GNDバスへ直結する。
10. D11〜D19用GNDへ大電流帰路を流さない。
11. 抵抗類は用途確定後に本体基板側または信号源側で設計する。
12. SPS30は5V BUS負荷とする。
13. DMG3415Uを初号機の逆流防止Pch MOSFETとして採択する。
```

---

# 13. 修正が必要な文書

| 文書 | 修正内容 |
|---|---|
| README.md | 採択済み構成のDMG3415U、D11〜D19方針を要約 |
| CURRENT_STATUS.md | 現在状態・採択済み事項・未確定事項の更新 |
| ROADMAP.md | Phase 2前確認事項にD11〜D19検証、GND/JST検証、発熱確認を追加 |
| 01_HARDWARE_OVERVIEW.md | GPIO方針、裏面ランド禁止、D11〜D19使用解禁を反映 |
| 05_WIRING_DIAGRAM.md | D11〜D19、JST 2ピン、GNDバス、本体GND接続を反映 |
| 07_DISPLAY_UI_SPEC.md | ePaperリボンケーブルと本体基板近傍配置を反映 |
| 08_POWER_ARCHITECTURE.md | DMG3415U、SPS30 3.5V〜5.0V、発熱確認を反映 |
| 09_SPI_RESOURCE_CONTROL.md | ePaper物理配置変更がSPI排他制御に影響しない旨を補足 |

---

# 14. 未解決事項

| 項目 | 内容 |
|---|---|
| D11〜D19個別割当 | 未決定。ePaper/SPI/I2S/起動条件との競合確認が必要 |
| JST規格 | JST-SH/GH/PH等から選定が必要 |
| I2S再割当 | 裏面ランド禁止により再検討が必要 |
| IP5306モジュール | 具体品未確定 |
| USB Presence | 検出方式未確定 |
| Battery Voltage | 測定方式未確定 |
| LD2410C電源 | 実機確認が必要 |

---

# 15. 記録状態

```text
RECORDED
```

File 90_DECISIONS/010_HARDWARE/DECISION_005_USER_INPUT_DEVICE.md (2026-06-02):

採択:
- 水平ダイヤル式ロータリーエンコーダ
- 押下スイッチ付き

接続:
- MCP23017

使用信号:
- ENC_A
- ENC_B
- ENC_SW

不採択:
- RGB LED付きロータリーエンコーダ
- RGB状態表示

理由:
- GPIO消費削減
- UI単純化
- 据置型日めくりUIとの親和性

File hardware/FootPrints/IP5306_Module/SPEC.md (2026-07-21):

# IP5306_Module フットプリント設計仕様書
**Document ID**: PM-FP-004
**Document Name**: SPEC.md
**Module**: IP5306_Module
**Version**: Release v2.0
**Status**: RELEASED
**Library**: PowerModules.pretty
**Last Updated**: 2026-07-17

---

# 1. 目的

本書は PowerModules.pretty に登録する
IP5306 UPS Power Module フットプリントの設計仕様を定義する。

本書は本モジュールの唯一の設計基準文書とする。

詳細な座標は

```
COORDINATES.md
```

を参照する。

---

# 2. モジュール概要

IP5306 を搭載した
6Pin UPS電源モジュールである。

主な用途

- Li-ion充電
- 5V昇圧
- UPS電源
- Battery管理

本プロジェクトでは

Digital Kakejiku

電源基板の中核モジュールとして使用する。

---

# 3. 基本設計方針

本フットプリントは
PowerModules.pretty 共通設計規約に従う。

採用方針

- 現物実測優先
- 基板中心原点
- Pad番号のみ管理
- 信号名は回路図管理
- F.Fabによる機械外形管理
- F.SilkSによる視認性向上
- F.Courtyardによる実装領域管理

---

# 4. モジュール仕様

端子数

```
6
```

実装方式

```
Through Hole
```

用途

```
UPS Power Module
```

---

# 5. ピン仕様

|Pad|信号|
|---:|---|
|1|VIN|
|2|GND|
|3|GND|
|4|BAT|
|5|GND|
|6|OUT-5V|

Pad番号のみをフットプリントで管理する。

信号名はシンボル側で管理する。

---

# 6. Pad仕様

Pad Type

```
Through Hole
```

Pad Shape

- Pad1：RoundRect
- Pad2〜Pad6：Oval

Pad径およびドリル径は
現物実測に基づく。

詳細座標は

```
COORDINATES.md
```

を参照する。

---

# 7. 基板外形

管理レイヤ

```
F.Fab
```

管理対象

- 基板外形
- 突出部
- 切欠き

寸法は実測値を採用する。

---

# 8. シルク仕様

管理レイヤ

```
F.SilkS
```

表示内容

- OUT-5V
- BAT
- GND
- VIN

Pin番号は表示しない。

文字はPad・固定穴・Courtyardと干渉しないこと。

---

# 9. Reference

Field

```
Reference
```

Layer

```
F.SilkS
```

初期値

```
J**
```

---

# 10. Value

Field

```
Value
```

Layer

```
F.Fab
```

表示

```
IP5306_Module
```

---

# 11. Description

Description

```
IP5306 UPS Power Module
```

---

# 12. Keywords

```
IP5306
UPS
Battery
Boost
Charger
Power
```

---

# 13. Courtyard

管理レイヤ

```
F.Courtyard
```

最大機械外形に対して

```
+0.50mm
```

以上確保する。

---

# 14. Design Rationale

## 原点

採択

```
基板中心
```

理由

左右対称性を維持し、
PCB配置およびレビューを容易にする。

---

## 実測優先

採択

```
現物実測
```

理由

メーカー図面との差異を吸収するため。

---

## Pad管理

採択

```
Pad番号のみ
```

理由

信号管理をシンボルへ集約するため。

---

## シルク

採択

```
端子名称表示
```

理由

ユニバーサル基板配線および
PCBレビュー時の視認性を向上させるため。

---

## Reference

採択

```
J**
```

理由

モジュールとして管理するため。

---

# 15. 品質基準

登録前に以下を確認する。

- 基板中心原点
- Pad番号
- Pad形状
- F.Fab
- F.SilkS
- F.Courtyard
- Description
- Keywords
- ライブラリ再読込

---

# 16. 最終判定

Design Review

```
PASS
```

Library Review

```
PASS
```

PCB Placement

```
PASS
```

Registration

```
PASS
```

---

# 17. 関連文書

- COORDINATES.md
- ../common/FOOTPRINT_LIBRARY_RULES.md
- ../common/FOOTPRINT_COORDINATE_RULES.md
- ../common/MEASUREMENT_GUIDE.md
- ../common/DESIGN_RATIONALE_GUIDE.md

---

# 18. 変更履歴

|Version|内容|
|---|---|
|v2.0|Release初版。PowerModules.pretty用IP5306_Moduleフットプリント仕様書を制定。|

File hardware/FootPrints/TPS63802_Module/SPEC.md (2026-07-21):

# TPS63802_Module フットプリント設計仕様書

**Document ID**: PM-FP-005
**Document Name**: SPEC.md
**Module**: TPS63802_Module
**Library**: PowerModules.pretty
**Version**: Release v1.0
**Status**: RELEASED
**Author**: Digital Kakejiku Project
**Last Updated**: 2026-07-17

---

# 1. 目的

本書は PowerModules.pretty に登録する
TPS63802_Module フットプリントの設計仕様を定義する。

本書は本フットプリントの設計・レビュー・保守・再構築の
唯一の仕様書とする。

KiCadフットプリント作成時は
本書および

```
COORDINATES.md
```

を同時に参照すること。

---

# 2. 適用範囲

本仕様は以下に適用する。

- PowerModules.pretty
- TPS63802_Module.kicad_mod
- GitHub管理ドキュメント
- PCBレイアウト
- レビュー資料

---

# 3. モジュール概要

TPS63802を搭載した
昇降圧DC/DCコンバータモジュールである。

本プロジェクトでは

- UPS出力5V
- TPS63802
- 安定した3.3V生成

を目的として使用する。

用途

- XIAO ESP32S3
- OLED
- RTC
- I2Cデバイス
- SPIデバイス
- 各種センサー

への3.3V供給。

---

# 4. 基本設計方針

PowerModules.pretty 全体で
以下を統一する。

## 4.1 原点

基板中心

```
X=0
Y=0
```

---

## 4.2 実測優先

メーカー図面より

現物実測

を優先する。

---

## 4.3 Pad管理

Padには

```
番号のみ
```

を持たせる。

信号名は回路図シンボルで管理する。

---

## 4.4 レイヤ

|Layer|用途|
|---|---|
|F.Fab|機械外形|
|F.SilkS|視認情報|
|F.Courtyard|占有領域|

---

# 5. モジュール仕様

|項目|内容|
|---|---|
|名称|TPS63802_Module|
|種類|Buck-Boost Converter|
|端子数|8|
|実装|Through Hole|
|配置|左右対称|

---

# 6. ピン仕様

|Pad|信号|
|---:|---|
|1|VIN|
|2|VIN|
|3|GND|
|4|GND|
|5|VOUT|
|6|VOUT|
|7|GND|
|8|GND|

Pad番号のみを管理する。

---

# 7. Pad仕様

Pad Type

```
Through Hole
```

Pad Shape

```
Rect
```

Pad1〜Pad8

すべて矩形。

詳細寸法は

```
COORDINATES.md
```

を参照する。

---

# 8. ドリル径

VIN

```
1.0mm
```

VOUT

```
1.0mm
```

GND

Pad3

Pad4

```
0.8mm
```

Pad7

Pad8

```
1.0mm
```

実測値を採用する。

---

# 9. 基板外形

管理レイヤ

```
F.Fab
```

寸法

```
25.840 × 12.850 mm
```

中心原点。

矩形。

---

# 10. Courtyard

管理レイヤ

```
F.Courtyard
```

F.Fabより

```
0.500mm
```

外側。

寸法

```
26.840 × 13.850 mm
```

---

# 11. シルク仕様

管理レイヤ

```
F.SilkS
```

表示

左側

```
VIN
VIN
GND
GND
```

右側

```
VOUT
VOUT
GND
GND
```

さらに

```
TOP
```

を表示する。

Pin1識別用

L字マーク

を左上に配置する。

---

# 12. Reference

Field

```
Reference
```

初期値

```
J**
```

Layer

```
F.SilkS
```

---

# 13. Value

Field

```
Value
```

値

```
TPS63802_Module
```

Layer

```
F.Fab
```

Referenceと重ならない位置へ配置する。

---

# 14. Description

KiCad Property

```
Description
```

値

```
TPS63802 Buck-Boost Power Module
```

トップレベル

```
(descr "TPS63802 Buck-Boost Power Module")
```

についても

同一文字列を設定する。

---

# 15. Keywords

KiCad Tags

```
TPS63802
Buck
Boost
DCDC
Converter
Power
3V3
```

トップレベル

```
(tags "TPS63802 Buck Boost DCDC Converter Power 3V3")
```

を設定する。

---

# 16. Design Rationale

## 16.1 原点

採択

```
基板中心
```

理由

PowerModules.pretty 全体で
統一した配置基準を維持するため。

---

## 16.2 現物実測

採択

```
現物実測優先
```

理由

モジュール販売元による寸法差異を吸収するため。

---

## 16.3 Pad番号

採択

```
Pad番号のみ
```

理由

信号管理を回路図シンボルへ
一元化するため。

---

## 16.4 Through Hole

採択

```
Through Hole
```

理由

対象モジュールが
ピンヘッダー実装済みであるため。

---

## 16.5 Pad形状

採択

```
Rect
```

理由

元モジュールの実装状態を忠実に再現するため。

---

## 16.6 シルク

採択

```
端子名称表示
```

理由

ユニバーサル基板配線時の
誤接続を防止するため。

---

## 16.7 TOP表示

採択

```
TOP
```

理由

180°逆実装を防止するため。

---

## 16.8 Pin1識別

採択

```
L字マーク
```

理由

Pin1位置を容易に識別できるため。

---

## 16.9 Description

採択

```
TPS63802 Buck-Boost Power Module
```

理由

KiCadライブラリ検索および
フットプリント管理性向上のため。

---

## 16.10 Keywords

採択

```
TPS63802
Buck
Boost
DCDC
Converter
Power
3V3
```

理由

ライブラリ検索性向上のため。

---

# 17. 品質基準

ライブラリ登録前に
以下を確認する。

- 原点
- Pad番号
- Pad座標
- Pad寸法
- ドリル径
- F.Fab
- F.Courtyard
- F.SilkS
- TOP表示
- Pin1表示
- Reference
- Value
- Description
- Tags
- DRC
- ライブラリ再読込

すべてPASSであること。

---

# 18. レビュー結果

|項目|判定|
|---|---|
|構文|PASS|
|Pad配置|PASS|
|Pad寸法|PASS|
|Pad番号|PASS|
|原点|PASS|
|F.Fab|PASS|
|F.Courtyard|PASS|
|シルク|PASS|
|TOP表示|PASS|
|Pin1識別|PASS|
|Description|PASS|
|Keywords|PASS|
|PowerModules.pretty整合|PASS|

---

# 19. 最終判定

Design Review

```
PASS
```

Library Review

```
PASS
```

PCB Placement

```
PASS
```

GitHub Registration

```
PASS
```

Release

```
APPROVED
```

---

# 20. 関連文書

- COORDINATES.md
- ../common/FOOTPRINT_LIBRARY_RULES.md
- ../common/FOOTPRINT_COORDINATE_RULES.md
- ../common/FOOTPRINT_REVIEW_CHECKLIST.md
- ../common/FOOTPRINT_DESIGN_WORKFLOW.md
- ../common/MEASUREMENT_GUIDE.md
- ../common/DESIGN_RATIONALE_GUIDE.md

---

# 21. 再構築手順

1. 新規フットプリント作成
2. 原点を基板中心へ設定
3. F.Fab作成
4. Pad配置
5. Pad番号設定
6. Pad寸法設定
7. ドリル径設定
8. F.SilkS文字配置
9. TOP表示追加
10. Pin1識別追加
11. F.Courtyard作成
12. Reference配置
13. Value配置
14. Description設定
15. Tags設定
16. 保存
17. ライブラリ再読込
18. PCBへ仮配置
19. DRC実施
20. GitHub登録

---

# 22. 保守方針

フットプリント変更時は
以下を同時更新すること。

- TPS63802_Module.kicad_mod
- SPEC.md
- COORDINATES.md
- FOOTPRINT_CHANGELOG.md

設計変更は
PowerModules.pretty 全体との整合性を維持すること。

---

# 23. 変更履歴

|Version|日付|内容|
|---|---|---|
|v1.0|2026-07-17|初版制定。TPS63802_Module(3).kicad_modに合わせて仕様書を作成。Description・Tags・TOP表示・Pin1識別を正式仕様として反映。|

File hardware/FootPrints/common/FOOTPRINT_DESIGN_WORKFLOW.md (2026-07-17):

# PowerModules Library Footprint Design Workflow
**Document ID**: PM-FP-006
**Document Name**: FOOTPRINT_DESIGN_WORKFLOW.md
**Version**: Release v2.0
**Status**: RELEASED
**Last Updated**: 2026-07-17

---

# 1. 目的

本書は PowerModules.pretty に新規フットプリントを登録する際の標準作業手順（SOP）を定義する。

本手順に従うことで、すべてのフットプリントを同一品質で作成・レビュー・登録することを目的とする。

---

# 2. 適用範囲

本書は以下のすべてに適用する。

- USBモジュール
- 電源モジュール
- センサーモジュール
- MCUモジュール
- RTCモジュール
- Displayモジュール
- その他 PowerModules.pretty に登録する全フットプリント

---

# 3. 役割分担

|担当|役割|
|---|---|
|設計者|現物測定・設計・KiCad入力・最終判断|
|PCB設計レビュー担当|仕様整理・レビュー・整合性確認・改善提案|

---

# 4. 設計フロー

```
現物入手
      │
      ▼
現物実測
      │
      ▼
設計値採択
      │
      ▼
仕様書作成
      │
      ▼
座標仕様書作成
      │
      ▼
KiCad入力
      │
      ▼
設計レビュー
      │
      ▼
修正
      │
      ▼
保存
      │
      ▼
ライブラリ再読込
      │
      ▼
PCB配置確認
      │
      ▼
GitHub登録
```

---

# 5. 現物実測

設計値は以下の優先順位で採択する。

1. 現物実測
2. メーカー図面
3. データシート

推測は禁止する。

未確認項目は

```
未確認
```

と記載する。

---

# 6. 座標決定

原点は

```
基板中心
```

とする。

例外を設けない。

座標精度

```
0.01mm
```

---

# 7. KiCad入力順

以下の順番を厳守する。

1. F.Fab
2. Pad
3. 固定穴（NPTH）
4. 機械外形
5. Reference
6. Value
7. Pin1マーク
8. 部品名称
9. 端子名称
10. F.Courtyard

---

# 8. レイヤー確認

|Layer|内容|
|---|---|
|F.Fab|基板・機械外形|
|F.SilkS|Pin1・部品名・端子名・Reference|
|F.Courtyard|最大外形+0.5mm|

---

# 9. フィールド設定

Reference

- KiCadフィールド
- 通常テキスト禁止

Value

- フットプリント名

Description

- 部品説明
- 寸法
- 実測採用

Keywords

- 検索性重視

---

# 10. 保存確認

保存後は以下を必ず実施する。

1. 保存
2. エディタ終了
3. ライブラリ再読込

再読込できない場合は登録完了としない。

---

# 11. PCB確認

テストPCBへ配置し、以下を確認する。

- Pad番号
- Pad位置
- 固定穴
- Courtyard
- DRC
- 実装方向

---

# 12. GitHub登録

登録対象

- 仕様書
- 座標仕様書
- ChangeLog
- レビュー結果

---

# 13. 完了条件

以下をすべて満たした場合のみ正式登録とする。

- 設計レビュー PASS
- 保存確認 PASS
- ライブラリ再読込 PASS
- PCB確認 PASS
- GitHub更新完了

---

# 14. 設計判断の記録

フットプリントごとに以下を記録する。

- 原点採用理由
- 寸法採択理由
- 特殊な設計判断
- 採用しなかった案
- レビュー指摘事項

この情報は仕様書の「Design Rationale」に記載する。

---

# 15. 変更履歴

|Version|内容|
|---|---|
|v2.0|Release第1版。USB_C_Breakout_6Pin開発プロセスを標準化。|

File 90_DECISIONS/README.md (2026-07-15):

# 20 Development Guidelines

**タイトル**  
20 Development Guidelines

**最終更新**  
2026-07-15

**文書版**  
vNext 1.3

**STATUS**  
FINALIZED

**責務**  
本書は digital-kakejiku プロジェクト全体における開発規約、設計原則、変更管理、レビュー方針および品質維持ルールを定義する正式文書である。

**Single Source**  
本書は開発ルールを管理する唯一の文書である。

開発手順、レビュー基準、設計原則および変更管理は本書を正式情報とし、他文書では重複管理しない。

---

# 対象読者

- プロジェクト管理者
- システム設計者
- ハードウェア開発者
- Firmware開発者
- GAS開発者
- 保守担当者

---

# 関連文書

## 前提

- docs/00_PROJECT_CONVENTIONS.md

## 参照

- README.md
- CURRENT_STATUS.md
- ROADMAP.md

## 関連

- docs/15_GAS_IMPLEMENTATION_GUIDE.md
- docs/16_TESTING_STRATEGY.md
- docs/17_TROUBLESHOOTING.md

## 後続

- 全開発工程
- 全レビュー工程
- 全保守工程

---

# 1. 文書の目的

本書はプロジェクト全体の開発ルールを定義する。

本書では以下を管理する。

- 開発原則
- レビュー基準
- 品質維持
- 変更管理
- ブランチ運用方針
- ドキュメント運用

実装仕様や個別設計は各設計書で管理する。

---

# 2. 開発基本方針

本プロジェクトでは以下を基本原則とする。

- Single Source of Truth を維持する。
- 単一責務を維持する。
- ドキュメント駆動で開発する。
- 設計変更は必ず文書へ反映する。
- 実装より文書を先行する。
- 推測で仕様を追加しない。

---

# 3. 設計原則

すべての設計では以下を適用する。

- 単一責務
- 高凝集・低結合
- 保守性優先
- 拡張性確保
- 可読性優先
- 再利用性確保

---

# 4. Single Source of Truth

同一情報は一箇所のみで管理する。

例

|情報|正式文書|
|---|---|
|現在の進捗|CURRENT_STATUS.md|
|今後の計画|ROADMAP.md|
|電源設計|08_POWER_ARCHITECTURE.md|
|配線|05_WIRING_DIAGRAM.md|
|Spreadsheet構造|14_SPREADSHEET_SCHEMA.md|
|Retry仕様|18_GAS_RETRY_STRATEGY.md|
|Prompt仕様|19_GEMINI_PROMPT_SPECIFICATION.md|

他文書では概要のみ記載する。

---

# 5. ドキュメント更新原則

設計変更時は以下を実施する。

- 関連文書を洗い出す。
- Single Sourceを維持する。
- CHANGE LOGを更新する。
- STATUSを確認する。
- 相互参照を確認する。
- GitHub表示を確認する。

---

# 6. STATUS運用

STATUSは以下のみ使用する。

|STATUS|用途|
|---|---|
|PROPOSED|構想|
|PENDING|未着手|
|IMPLEMENTING|実装中|
|IN_PROGRESS|進行中|
|COMPLETED|完了|
|CONFIRMED|確認済|
|FINALIZED|正式確定|

独自STATUSは禁止する。

---

# 7. RESULT運用

RESULTは以下のみ使用する。

|RESULT|用途|
|---|---|
|GO|実施可|
|NG|実施不可|
|PASS|試験合格|
|FAIL|試験不合格|

PASS/FAILは試験専用とする。

GO/NGは判断結果として使用する。

---

# 8. レビュー方針

レビューでは以下を確認する。

- 文書矛盾
- 用語統一
- STATUS統一
- Single Source維持
- GitHub表示
- Markdown構文
- 関連文書整合性

レビュー結果は事実と改善案を分離して記録する。

---

# 9. 実装方針

実装前に設計書を更新する。

設計変更をコードのみへ反映してはならない。

コード修正後は必要に応じて以下を更新する。

- CURRENT_STATUS.md
- CHANGE LOG
- ROADMAP.md

---

# 10. 品質方針

品質を以下で維持する。

- 設計レビュー
- コードレビュー
- 単体試験
- 結合試験
- システム試験
- ドキュメントレビュー

品質判定は **16_TESTING_STRATEGY.md** を正式情報とする。

---

# 11. GitHub運用

GitHubでは以下を基本とする。

- Markdownを正式文書とする。
- CHANGE LOGを維持する。
- コミット単位で変更理由を明確化する。
- ドキュメントと実装を同期する。
- レビュー完了後に反映する。

---

# 12. 制約事項

本書では開発ルールのみを定義する。

実装仕様や設計仕様は対象外とする。

---

# 13. 未定義事項

|項目|状態|
|---|---|
|ブランチ戦略詳細|今後決定|
|タグ運用詳細|今後決定|
|Issue運用詳細|今後決定|
|PRテンプレート|今後決定|

---

# CHANGE LOG

|日付|内容|
|---|---|
|2026-07-15|新規作成。vNext 1.3文書体系に合わせ、プロジェクト全体の開発規約を定義。Single Source of Truth、レビュー基準、STATUS・RESULT運用、品質管理、GitHub運用を正式化。|

---

# 自己査読チェックリスト

- [x] 文書内矛盾なし
- [x] 全文書との責務分離
- [x] STATUS統一
- [x] RESULT統一
- [x] Single Source of Truth維持
- [x] GitHub表示崩れなし
- [x] vNext 1.3文書体系へ適合

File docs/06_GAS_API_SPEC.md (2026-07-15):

# 06 GAS API Specification

**タイトル**  
06 GAS API Specification

**最終更新**  
2026-07-15

**文書版**  
vNext 1.3

**STATUS**  
FINALIZED

**責務**  
本書は Google Apps Script が提供する API の仕様、エンドポイント、リクエスト・レスポンスおよび API の責務を定義する正式設計書である。

**Single Source**  
本書は GAS API 仕様を管理する唯一の文書である。

API仕様、エンドポイント、レスポンス仕様およびエラー応答は本書を正式情報とし、他文書では重複管理しない。

---

# 対象読者

- GAS開発者
- ESP32開発者
- 保守担当者

---

# 関連文書

## 前提

- docs/00_PROJECT_CONVENTIONS.md

## 参照

- README.md
- CURRENT_STATUS.md
- ROADMAP.md

## 関連

- docs/02_SOFTWARE_OVERVIEW.md
- docs/03_LOG_FORMAT.md
- docs/12_CONFIGURATION_MANAGEMENT.md
- docs/14_SPREADSHEET_SCHEMA.md
- docs/18_GAS_RETRY_STRATEGY.md
- docs/19_GEMINI_PROMPT_SPECIFICATION.md

## 後続

- GAS実装
- ESP32 Firmware実装
- API試験

---

# 1. 文書の目的

本書は Google Apps Script が提供する API を定義する。

本書では以下を管理する。

- API一覧
- エンドポイント
- リクエスト形式
- レスポンス形式
- エラー応答
- API設計方針

実装コードおよび Spreadsheet スキーマは管理しない。

---

# 2. API設計方針

本システムでは以下を基本方針とする。

- RESTライクなAPI構成とする。
- JSONを標準フォーマットとする。
- HTTPS通信を前提とする。
- APIは単一責務とする。
- エラー応答を統一する。
- API仕様は後方互換性を考慮する。

---

# 3. API一覧

|API|用途|STATUS|
|---|---|---|
|Health Check API|動作確認|CONFIRMED|
|Observation API|観測データ送信|CONFIRMED|
|Configuration API|設定取得|CONFIRMED|
|Calendar API|暦取得|CONFIRMED|
|Poem API|詩取得|CONFIRMED|

---

# 4. システム構成

```text
ESP32
   │
 HTTPS
   │
   ▼
Google Apps Script
   │
   ├──────────────┐
   ▼              ▼
Spreadsheet    Gemini API
```

APIは Google Apps Script を唯一の窓口とする。

---

# 5. API共通仕様

本章では、すべてのAPIに共通する仕様を定義する。

---

## 5.1 通信方式

|項目|内容|
|---|---|
|Protocol|HTTPS|
|Request Format|JSON|
|Response Format|JSON|
|Character Encoding|UTF-8|

---

## 5.2 リクエスト

ESP32 は JSON を使用して Google Apps Script へ送信する。

リクエスト項目の詳細は各APIで定義する。

---

## 5.3 レスポンス

レスポンスは JSON を返却する。

正常・異常を問わず同一フォーマットを基本とする。

---

## 5.4 RESULT

API内部で使用する RESULT は以下を使用する。

|RESULT|意味|
|---|---|
|GO|処理継続可能|
|NG|処理異常|
|PASS|正常終了|
|FAIL|処理失敗|

STATUS はAPIレスポンスとして使用しない。

---

# 6. Health Check API

Health Check API はシステムの稼働状態を確認する。

---

## 6.1 責務

- GAS動作確認
- Spreadsheet接続確認
- 基本機能確認

---

## 6.2 処理概要

```text
ESP32
   │
Health Check
   │
   ▼
GAS
   │
Spreadsheet確認
   │
   ▼
Response
```

---

# 7. Observation API

Observation API は観測データを受信し保存する。

---

## 7.1 責務

- Observation受信
- データ検証
- Spreadsheet保存
- ログ記録

---

## 7.2 保存先

Observation Log

詳細構造は **14_SPREADSHEET_SCHEMA.md** を正式情報とする。

---

# 8. Configuration API

Configuration API は設定情報を取得する。

---

## 8.1 責務

- system_config取得
- source_config取得

ESP32 は設定値を保持せず、必要時に取得する。

詳細仕様は **12_CONFIGURATION_MANAGEMENT.md** を正式情報とする。

---

# 9. Calendar API

Calendar API は暦情報を返却する。

---

## 9.1 責務

- 暦情報取得
- Calendar返却

生成方法は **13_GAS_OPERATION_POLICY.md** を正式情報とする。

---

# 10. Poem API

Poem API は詩情報を返却する。

---

## 10.1 責務

- 詩取得
- キャッシュ確認
- 必要時生成
- レスポンス返却

生成仕様は **19_GEMINI_PROMPT_SPECIFICATION.md** を正式情報とする。

---

# 11. エラー応答

本章では API 共通のエラー応答方針を定義する。

エラー処理の実装詳細は対象モジュールおよび **18_GAS_RETRY_STRATEGY.md** を正式情報とする。

---

## 11.1 基本方針

- エラー応答形式は統一する。
- 内部例外をそのまま返却しない。
- エラー内容は Error Log へ記録する。
- Retry可能なエラーは Retry Controller が処理する。

---

## 11.2 エラー分類

|分類|概要|
|---|---|
|Validation Error|入力値異常|
|Authentication Error|認証異常|
|Spreadsheet Error|Spreadsheetアクセス異常|
|Gemini Error|Gemini API異常|
|Internal Error|想定外例外|

---

## 11.3 エラー処理

```text
API Request
      │
      ▼
入力検証
      │
      ├──正常─────►API処理
      │
      └──異常─────►Error Response
                     │
                     ▼
                 Error Log
```

---

# 12. ログとの関係

API処理では必要に応じてログを記録する。

ログ仕様は **03_LOG_FORMAT.md** を正式情報とする。

|API|ログ|
|---|---|
|Health Check API|System Log|
|Observation API|Observation Log|
|Configuration API|System Log|
|Calendar API|System Log|
|Poem API|System Log|
|API異常|Error Log|

---

# 13. 認証方針

認証方式の詳細は **11_SECURITY_MANAGEMENT.md** を正式情報とする。

本書では設計方針のみ定義する。

---

## 基本方針

- HTTPS通信を前提とする。
- API認証を実施する。
- Secret情報はログへ保存しない。
- 認証情報をレスポンスへ返却しない。

認証アルゴリズムの詳細は本書では定義しない。

---

# 14. 設計方針

本システムでは以下をAPI設計原則とする。

---

## 単一責務

各APIは一つの責務のみを持つ。

---

## Single Source of Truth

データは Spreadsheet を正式情報とする。

APIは保存・取得の仲介のみを担当する。

---

## 保守性

- API追加を容易にする。
- 互換性を維持する。
- エラー処理を統一する。

---

## 拡張性

将来的なAPI追加に対応できる構成を維持する。

---

# 15. 制約事項

本書では API の論理仕様を定義する。

以下の項目は本書では定義しない。

|項目|管理文書|
|---|---|
|Spreadsheet構造|14_SPREADSHEET_SCHEMA.md|
|Retryアルゴリズム|18_GAS_RETRY_STRATEGY.md|
|Gemini Prompt|19_GEMINI_PROMPT_SPECIFICATION.md|
|認証詳細|11_SECURITY_MANAGEMENT.md|
|ソースコード構成|実装コード|

---

# 16. 将来拡張

本章では将来的に追加を検討する API を示す。

本章は構想であり、実装を保証するものではない。

---

## 16.1 API追加候補

|API|STATUS|備考|
|---|---|---|
|Diagnostic API|PROPOSED|詳細未定|
|Maintenance API|PROPOSED|詳細未定|
|Log Search API|PROPOSED|詳細未定|
|Statistics API|PROPOSED|詳細未定|
|OTA Support API|PROPOSED|詳細未定|

---

## 16.2 拡張方針

将来的な機能追加に対応できるよう以下を維持する。

- RESTライク設計
- JSON統一
- エラー応答統一
- 後方互換性維持
- モジュール分離

---

# 17. 未定義事項

本書では以下を定義しない。

|項目|状態|
|---|---|
|API Version管理方式|今後決定|
|レート制限|今後決定|
|リクエストサイズ制限|今後決定|
|タイムアウト値|今後決定|
|将来API追加順序|今後決定|

---

# CHANGE LOG

|日付|内容|
|---|---|
|2026-07-15|vNext 1.3文書体系に合わせ全面刷新。GAS API仕様文書として再設計し、README・CURRENT_STATUS・ROADMAP・02_SOFTWARE_OVERVIEW・03_LOG_FORMAT・11_SECURITY_MANAGEMENT・12_CONFIGURATION_MANAGEMENT・14_SPREADSHEET_SCHEMA・18_GAS_RETRY_STRATEGY・19_GEMINI_PROMPT_SPECIFICATIONとの責務を明確化。Single Source of Truthに基づき、API仕様・認証・エラー応答・データ管理との重複を整理し、STATUS表記・文書構成を共通規約へ統一。|
|2026-07-14|API構成およびエラー処理方針を更新。|
|2026-07-13|Health Check API・Observation API・Configuration API設計を更新。|

---

# 付録A. 関連文書の責務

|文書|責務|
|---|---|
|README.md|プロジェクト概要・入口|
|CURRENT_STATUS.md|現在の開発状況|
|ROADMAP.md|中長期計画|
|02_SOFTWARE_OVERVIEW.md|ソフトウェア全体構成|
|03_LOG_FORMAT.md|ログ仕様|
|06_GAS_API_SPEC.md|API仕様（本書）|
|11_SECURITY_MANAGEMENT.md|認証・セキュリティ|
|12_CONFIGURATION_MANAGEMENT.md|設定管理|
|14_SPREADSHEET_SCHEMA.md|データ構造|
|18_GAS_RETRY_STRATEGY.md|Retry仕様|
|19_GEMINI_PROMPT_SPECIFICATION.md|Gemini仕様|

---

# 付録B. 更新ルール

本書は以下の場合に更新する。

- API追加・削除
- API仕様変更
- リクエスト・レスポンス変更
- 認証方式変更
- エラー応答変更
- 文書体系変更

日常的な実装変更は記載しない。

実装コードおよび詳細アルゴリズムは関連文書またはソースコードで管理する。

---

# 自己査読チェックリスト

- [x] 文書内矛盾なし
- [x] READMEとの責務分離
- [x] CURRENT_STATUSとの責務分離
- [x] ROADMAPとの責務分離
- [x] 00_PROJECT_CONVENTIONSとの整合
- [x] 02_SOFTWARE_OVERVIEWとの責務分離
- [x] 03_LOG_FORMATとの責務分離
- [x] 11_SECURITY_MANAGEMENTとの責務分離
- [x] 12_CONFIGURATION_MANAGEMENTとの責務分離
- [x] 14_SPREADSHEET_SCHEMAとの責務分離
- [x] 18_GAS_RETRY_STRATEGYとの責務分離
- [x] 19_GEMINI_PROMPT_SPECIFICATIONとの責務分離
- [x] STATUS表記統一
- [x] Single Source of Truth維持
- [x] GitHub表示崩れなし
- [x] vNext 1.3文書体系へ適合

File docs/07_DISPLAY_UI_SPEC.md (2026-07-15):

# 07 Display UI Specification

**タイトル**  
07 Display UI Specification

**最終更新**  
2026-07-15

**文書版**  
vNext 1.3

**STATUS**  
FINALIZED

**責務**  
本書は digital-kakejiku の表示システム、ユーザーインターフェース、画面構成および操作体系を定義する正式設計書である。

**Single Source**  
本書は表示仕様およびUI仕様を管理する唯一の文書である。

画面構成、表示要素、操作体系および表示更新方針は本書を正式情報とし、他文書では重複管理しない。

---

# 対象読者

- UI設計者
- ハードウェア設計者
- ESP32開発者
- 保守担当者

---

# 関連文書

## 前提

- docs/00_PROJECT_CONVENTIONS.md

## 参照

- README.md
- CURRENT_STATUS.md
- ROADMAP.md

## 関連

- docs/01_HARDWARE_OVERVIEW.md
- docs/02_SOFTWARE_OVERVIEW.md
- docs/05_WIRING_DIAGRAM.md
- docs/10_CALENDAR_POEM_SUBSYSTEM.md
- docs/12_CONFIGURATION_MANAGEMENT.md

## 後続

- ESP32 Firmware実装
- UI実装
- システム統合試験

---

# 1. 文書の目的

本書はシステム全体の表示仕様を定義する。

本書では以下を管理する。

- 表示装置
- UI構成
- 操作体系
- 画面遷移
- 表示更新方針
- 保守画面

表示データ生成および詩生成仕様は管理しない。

---

# 2. UI設計方針

本システムでは以下を基本方針とする。

- 常時表示はE-Paperを使用する。
- 保守操作はOLEDへ分離する。
- 通常表示と保守UIを分離する。
- 情報量より視認性を優先する。
- 表示更新回数を最小化する。
- Single Source of Truth を維持する。

---

# 3. 表示装置

本システムでは2種類の表示装置を使用する。

|表示装置|用途|STATUS|
|---|---|---|
|7.5inch E-Paper|通常表示|CONFIRMED|
|OLED Display|保守画面|CONFIRMED|

---

# 4. UI構成

```text
          7.5inch E-Paper
   +----------------------------+
   |       通常表示画面          |
   +----------------------------+

               ▲

         ESP32 Firmware

               ▼

      OLED + Rotary Encoder

   +----------------------------+
   |      保守・設定画面         |
   +----------------------------+
```

通常表示と保守画面は独立して動作する。

---

# 5. 通常表示（E-Paper）

通常表示は、日常利用時に表示するメイン画面である。

利用者による操作を前提とせず、定期更新を基本とする。

---

## 5.1 表示内容

|項目|STATUS|
|---|---|
|日付|CONFIRMED|
|曜日|CONFIRMED|
|二十四節気|CONFIRMED|
|七十二候|CONFIRMED|
|天候情報|CONFIRMED|
|環境センサー情報|CONFIRMED|
|AI生成詩|CONFIRMED|

各表示内容の生成仕様は関連文書を正式情報とする。

---

## 5.2 更新方針

- 通常表示は必要時のみ更新する。
- E-Paper更新回数を最小化する。
- 更新タイミングはソフトウェアが管理する。
- 表示内容生成は Google Apps Script が担当する。

更新周期の詳細は **13_GAS_OPERATION_POLICY.md** を正式情報とする。

---

# 6. 保守画面（OLED）

OLED は設定変更および保守専用画面とする。

通常運転時の情報表示は担当しない。

---

## 6.1 主な機能

|機能|STATUS|
|---|---|
|システム状態表示|CONFIRMED|
|設定変更|CONFIRMED|
|ログ確認|CONFIRMED|
|通信状態確認|CONFIRMED|
|手動更新|CONFIRMED|
|詩再生成|CONFIRMED|

---

## 6.2 設計方針

- E-Paperとは独立して動作する。
- 保守者向けUIとする。
- 少ない操作で目的へ到達できる構成とする。
- 表示内容はリアルタイム性を優先する。

---

# 7. 操作体系

操作入力はロータリーエンコーダを使用する。

---

## 7.1 入力方法

|入力|用途|
|---|---|
|左回転|前項目|
|右回転|次項目|
|押下|決定|

長押し操作および複合操作は本書では定義しない。

---

## 7.2 操作方針

- 階層を浅くする。
- 戻る操作を容易にする。
- 誤操作を防止する。
- 操作回数を最小限とする。

---

# 8. 画面構成

OLED画面は以下の構成を基本とする。

```text
System Status
      │
      ├── Network
      ├── Sensors
      ├── Display
      ├── Configuration
      ├── Logs
      ├── Calendar
      ├── Poem
      └── Maintenance
```

詳細なメニュー構成は実装時に管理する。

---

# 9. 画面遷移

本章では、ユーザーインターフェース全体の画面遷移方針を定義する。

画面構成は保守性を優先し、複雑な階層構造を避ける。

---

## 9.1 遷移概要

```text
System Status
      │
      ├────────────┐
      ▼            ▼
Configuration   Sensor Status
      │            │
      ▼            ▼
Calendar      Communication
      │            │
      ▼            ▼
Poem         System Log
      │            │
      └──────┬─────┘
             ▼
      Maintenance
```

---

## 9.2 基本ルール

- 階層は可能な限り浅くする。
- 一つ前の画面へ容易に戻れる構成とする。
- 設定変更後は確認画面を表示する。
- エラー画面からは安全に復帰できる構成とする。

---

# 10. 表示更新

本章では表示更新の基本方針を定義する。

---

## 10.1 E-Paper

E-Paper は差分更新ではなく、ソフトウェア側で更新要否を判定する。

更新条件の詳細は **13_GAS_OPERATION_POLICY.md** を正式情報とする。

基本方針は以下とする。

- 必要時のみ更新する。
- 更新頻度を最小化する。
- 表示品質を優先する。

---

## 10.2 OLED

OLED は状態変化に応じて更新する。

基本方針

- メニュー遷移時
- 状態変化時
- 設定変更時
- エラー表示時

---

# 11. 表示データ

表示データの生成責務を以下に示す。

|表示項目|生成元|
|---|---|
|日付|Calendar|
|曜日|Calendar|
|二十四節気|Calendar|
|七十二候|Calendar|
|環境情報|Observation|
|AI生成詩|Poem Cache|
|状態表示|ESP32|

生成アルゴリズムは各設計文書を正式情報とする。

---

# 12. 設計方針

表示システムは以下を基本原則とする。

---

## 視認性

- 重要情報を優先表示する。
- 長時間閲覧しても疲れにくい構成とする。
- コントラストを重視する。

---

## 保守性

- UIと表示生成を分離する。
- 表示内容を容易に追加できる構成とする。
- 保守画面を独立させる。

---

## 拡張性

- 表示項目追加に対応する。
- レイアウト変更に対応する。
- 表示テーマ追加に対応する。

---

## Single Source of Truth

- UI仕様は本書を正式情報とする。
- 表示データ生成仕様は関連文書を正式情報とする。
- 状態管理は **04_STATE_MACHINE.md** を正式情報とする。

---

# 13. 制約事項

本章では表示システム設計における制約事項を定義する。

本書ではUI設計を対象とし、表示データ生成アルゴリズムや実装方法は対象外とする。

---

## 13.1 本書で定義しない事項

|項目|管理文書|
|---|---|
|状態遷移|04_STATE_MACHINE.md|
|データ取得|06_GAS_API_SPEC.md|
|暦生成|10_CALENDAR_POEM_SUBSYSTEM.md|
|Gemini Prompt|19_GEMINI_PROMPT_SPECIFICATION.md|
|表示更新周期|13_GAS_OPERATION_POLICY.md|
|表示レイアウト実装|ESP32 Firmware|

---

## 13.2 UI設計制約

以下を設計制約とする。

- 通常表示はE-Paperのみとする。
- 保守操作はOLEDのみとする。
- E-Paperから設定変更は行わない。
- OLEDは保守用途に限定する。
- UI仕様はモジュール構成へ依存しない。

---

# 14. 将来拡張

本章では将来的に追加を検討するUI機能を示す。

本章は構想であり、実装を保証するものではない。

---

## 14.1 表示拡張

|項目|STATUS|備考|
|---|---|---|
|複数テーマ|PROPOSED|詳細未定|
|画面レイアウト切替|PROPOSED|詳細未定|
|季節テーマ|PROPOSED|詳細未定|
|フォント切替|PROPOSED|詳細未定|
|アイコン追加|PROPOSED|詳細未定|

---

## 14.2 保守画面拡張

|項目|STATUS|備考|
|---|---|---|
|診断画面|PROPOSED|詳細未定|
|統計情報表示|PROPOSED|詳細未定|
|通信履歴表示|PROPOSED|詳細未定|
|ログ検索|PROPOSED|詳細未定|

---

# 15. 未定義事項

本書では以下を定義しない。

|項目|状態|
|---|---|
|画面デザイン詳細|今後決定|
|フォントデザイン|今後決定|
|アイコンデザイン|今後決定|
|アニメーション|今後決定|
|多言語表示|今後決定|

---

# CHANGE LOG

|日付|内容|
|---|---|
|2026-07-15|vNext 1.3文書体系に合わせ全面刷新。表示・UI仕様文書として再設計し、README・CURRENT_STATUS・ROADMAP・01_HARDWARE_OVERVIEW・02_SOFTWARE_OVERVIEW・04_STATE_MACHINE・10_CALENDAR_POEM_SUBSYSTEM・12_CONFIGURATION_MANAGEMENTとの責務を明確化。Single Source of Truthに基づき、表示装置・UI・操作体系・表示更新方針を整理し、STATUS表記・文書構成を共通規約へ統一。|
|2026-07-14|OLED保守画面構成およびE-Paper表示方針を更新。|
|2026-07-13|UI構成および画面遷移方針を更新。|

---

# 付録A. 関連文書の責務

|文書|責務|
|---|---|
|README.md|プロジェクト概要・入口|
|CURRENT_STATUS.md|現在の開発状況|
|ROADMAP.md|中長期計画|
|01_HARDWARE_OVERVIEW.md|表示ハードウェア構成|
|02_SOFTWARE_OVERVIEW.md|表示ソフトウェア構成|
|04_STATE_MACHINE.md|状態管理|
|07_DISPLAY_UI_SPEC.md|表示・UI仕様（本書）|
|10_CALENDAR_POEM_SUBSYSTEM.md|表示コンテンツ生成|
|12_CONFIGURATION_MANAGEMENT.md|設定管理|
|13_GAS_OPERATION_POLICY.md|更新周期・運用|

---

# 付録B. 更新ルール

本書は以下の場合に更新する。

- 表示装置変更
- UI構成変更
- メニュー構成変更
- 操作体系変更
- 表示更新方針変更
- 文書体系変更

日常的な画面デザイン調整は記載しない。

実装詳細はESP32 Firmwareおよび関連設計書で管理する。

---

# 自己査読チェックリスト

- [x] 文書内矛盾なし
- [x] READMEとの責務分離
- [x] CURRENT_STATUSとの責務分離
- [x] ROADMAPとの責務分離
- [x] 00_PROJECT_CONVENTIONSとの整合
- [x] 01_HARDWARE_OVERVIEWとの責務分離
- [x] 02_SOFTWARE_OVERVIEWとの責務分離
- [x] 04_STATE_MACHINEとの責務分離
- [x] 10_CALENDAR_POEM_SUBSYSTEMとの責務分離
- [x] 12_CONFIGURATION_MANAGEMENTとの責務分離
- [x] STATUS表記統一
- [x] Single Source of Truth維持
- [x] GitHub表示崩れなし
- [x] vNext 1.3文書体系へ適合

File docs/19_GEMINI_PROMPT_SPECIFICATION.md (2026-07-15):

# 19 Gemini Prompt Specification

**タイトル**  
19 Gemini Prompt Specification

**最終更新**  
2026-07-15

**文書版**  
vNext 1.3

**STATUS**  
FINALIZED

**責務**  
本書は digital-kakejiku における Gemini を利用した詩生成の Prompt 構造、生成条件、品質要件および運用ルールを定義する正式設計書である。

**Single Source**  
本書は AI 詩生成 Prompt を管理する唯一の文書である。

Prompt構造、生成条件、品質要件および禁止事項は本書を正式情報とし、他文書では重複管理しない。

---

# 対象読者

- GAS開発者
- システム設計者
- Prompt設計者
- 保守担当者

---

# 関連文書

## 前提

- docs/00_PROJECT_CONVENTIONS.md

## 参照

- README.md
- CURRENT_STATUS.md
- ROADMAP.md

## 関連

- docs/06_GAS_API_SPEC.md
- docs/10_CALENDAR_POEM_SUBSYSTEM.md
- docs/12_CONFIGURATION_MANAGEMENT.md
- docs/13_GAS_OPERATION_POLICY.md
- docs/18_GAS_RETRY_STRATEGY.md

## 後続

- GAS実装
- AI詩生成
- 品質評価

---

# 1. 文書の目的

本書は AI 詩生成 Prompt を定義する。

本書では以下を管理する。

- Prompt構造
- 入力情報
- 出力要件
- 品質基準
- 禁止事項
- Prompt運用

Gemini API の実装方法やAPI仕様は本書では管理しない。

---

# 2. Prompt設計方針

本システムでは以下を基本方針とする。

- 客観描写を優先する。
- 季節感を重視する。
- 暦情報を反映する。
- 観測データを反映する。
- 説教・誘導を行わない。
- Single Source of Truth を維持する。

---

# 3. Prompt構成

```text
Observation
        │
Calendar
        │
System Config
        │
Prompt Builder
        │
Gemini
        │
Poem
```

Prompt は GAS 側で生成する。

ESP32 は Prompt を生成しない。

---

# 4. 入力情報

|入力|STATUS|
|---|---|
|Observation|CONFIRMED|
|calendar_master|CONFIRMED|
|system_config|CONFIRMED|

---

# 5. Prompt入力

Prompt Builder は複数の情報源から入力データを構築する。

---

## 5.1 入力データ

|入力|取得元|
|---|---|
|観測データ|observation_log|
|暦情報|calendar_master|
|システム設定|system_config|

---

## 5.2 基本方針

- 正式情報のみ利用する。
- 推測データを入力しない。
- Secret情報を入力しない。
- 必要最小限の情報のみ渡す。

---

# 6. Prompt生成

Prompt は GAS 側で動的に生成する。

---

## 基本方針

- 固定テンプレートを利用する。
- system_config を参照する。
- Prompt Version を管理する。
- Prompt Builder に責務を集中させる。

Prompt Version は system_config により管理する。

---

# 7. 詩生成要件

Gemini が生成する詩は以下を満たす。

---

## 基本要件

- 日本語
- 約100文字
- 自由詩
- 客観描写
- 季節感を含む
- 自然な文章

---

## 品質要件

- 読みやすい。
- 季節を感じられる。
- 観測データを自然に反映する。
- 説明文にならない。
- 日記にならない。

---

# 8. 表現ルール

生成文章では以下を適用する。

---

## 推奨

- 静かな表現
- 客観描写
- 季節表現
- 自然描写
- 空気感の表現

---

## 避ける表現

- 説教
- 命令
- 励まし
- 不安を煽る表現
- 宣伝

---

# 9. 禁止事項

以下を生成してはならない。

- 政治的内容
- 宗教的主張
- 投資助言
- 医療助言
- 差別表現
- 暴力表現
- 誹謗中傷
- 個人情報
- URL
- 広告

---

# 10. 暦情報利用

Calendar 情報を詩へ自然に反映する。

---

## 基本方針

- 二十四節気を反映する。
- 七十二候を反映する。
- 季節感を重視する。
- 説明的にならない。

---

## 表示ルール

二十四節気名および七十二候名を本文中へそのまま繰り返し表示しない。

表示仕様は **07_DISPLAY_UI_SPEC.md** を正式情報とする。

---

# 11. 観測データ利用

Observation を自然な表現へ変換する。

---

## 基本方針

- 数値をそのまま羅列しない。
- 客観描写へ変換する。
- 季節感を優先する。
- 異常値を誇張しない。

---

# 12. 出力

Gemini 出力は poem_cache へ保存する。

---

## 基本方針

- poem_cache を正式情報とする。
- ESP32 は poem_cache のみ取得する。
- Prompt を保存しない。
- Secret 情報を出力しない。

# 13. 品質要件

AI生成結果は以下の品質要件を満たさなければならない。

---

## 13.1 必須要件

|項目|要件|
|---|---|
|言語|日本語|
|文字数|約100文字|
|文体|自由詩|
|視点|客観描写|
|内容|自然・季節・観測情報を反映|
|読後感|静かで落ち着いた印象|

---

## 13.2 品質基準

生成結果は以下を満たすこと。

- 日本語として自然である。
- 文法上の破綻がない。
- 観測情報を自然に反映する。
- 季節感が感じられる。
- 説明文ではない。
- 毎日読んでも違和感が少ない。

---

# 14. Prompt Version管理

Prompt はバージョン管理する。

---

## 基本方針

- Prompt Version は `system_config` で管理する。
- Prompt 更新時は Version を更新する。
- Version により生成条件を追跡可能とする。
- Version をソースコードへハードコードしない。

---

## 管理対象

|項目|保存先|
|---|---|
|Prompt Version|system_config|
|Gemini Model|system_config|
|Temperature|system_config|
|Max Tokens|system_config|

---

# 15. Prompt運用

Prompt は運用ポリシーに従って利用する。

---

## 基本方針

- Prompt は GAS 側のみで生成する。
- ESP32 は Prompt を生成しない。
- Prompt を永続保存しない。
- Prompt をログへ出力しない。
- Prompt を外部公開しない。

---

## 再生成

Poem 再生成時は最新の Prompt Version を利用する。

再生成方式は **13_GAS_OPERATION_POLICY.md** を正式情報とする。

---

# 16. エラー時の扱い

Prompt 生成または Gemini 応答で異常が発生した場合の扱いを定義する。

---

## 基本方針

- Retry 対象を判定する。
- Prompt 自体を破壊しない。
- poem_cache を破壊しない。
- Error Log を記録する。

Retry 方針は **18_GAS_RETRY_STRATEGY.md** を正式情報とする。

---

# 17. 設計方針

Prompt 設計は以下を設計原則とする。

---

## 単一責務

- Prompt Builder は Prompt 作成のみ担当する。
- Gemini は文章生成のみ担当する。
- Poem Manager は生成管理のみ担当する。

---

## Single Source of Truth

|情報|正式管理|
|---|---|
|Prompt仕様|本書|
|設定|system_config|
|Calendar|calendar_master|
|Observation|observation_log|

---

## 保守性

- Prompt をコードへ分散させない。
- Prompt Builder を共通利用する。
- Version 管理を行う。

---

## 拡張性

将来的な AI モデル追加および Prompt 改良へ対応できる構成を維持する。

---

# 18. 制約事項

本書では Prompt 設計方針を定義する。

以下は対象外とする。

|項目|管理文書|
|---|---|
|Gemini API仕様|06_GAS_API_SPEC.md|
|Retry制御|18_GAS_RETRY_STRATEGY.md|
|実装コード|15_GAS_IMPLEMENTATION_GUIDE.md|
|Calendar構造|10_CALENDAR_POEM_SUBSYSTEM.md|
|Spreadsheet構造|14_SPREADSHEET_SCHEMA.md|

---

# 19. 将来拡張

本章では将来的な Prompt 機能拡張を示す。

---

## 19.1 拡張候補

|項目|STATUS|備考|
|---|---|---|
|複数詩スタイル|PROPOSED|詳細未定|
|季節別Prompt|PROPOSED|詳細未定|
|地域別Prompt|PROPOSED|詳細未定|
|AIモデル切替|PROPOSED|詳細未定|
|品質評価AI|PROPOSED|詳細未定|

---

## 19.2 品質改善

将来的に以下を検討する。

- Prompt最適化
- 品質自動評価
- AI生成比較
- Prompt改善支援

詳細仕様は今後決定する。

---

# 20. 未定義事項

|項目|状態|
|---|---|
|Promptテンプレート詳細|今後決定|
|品質評価基準詳細|今後決定|
|複数モデル運用|今後決定|
|自動品質判定|今後決定|
|生成履歴保持期間|今後決定|

---

# CHANGE LOG

|日付|内容|
|---|---|
|2026-07-15|vNext 1.3文書体系に合わせ全面刷新。Gemini Prompt設計文書として再設計し、README・CURRENT_STATUS・ROADMAP・06_GAS_API_SPEC・10_CALENDAR_POEM_SUBSYSTEM・12_CONFIGURATION_MANAGEMENT・13_GAS_OPERATION_POLICY・18_GAS_RETRY_STRATEGYとの責務を明確化。Single Source of Truthに基づき、Prompt構造・入力情報・品質要件・禁止事項・Version管理を整理し、STATUS表記・文書構成を共通規約へ統一。|
|2026-07-14|約100文字・自由詩・客観描写・政治/宗教/説教禁止・二十四節気/七十二候名の本文重複禁止方針を反映。|
|2026-06-21|Phase1 Prompt設計およびGemini運用方針を反映。|

---

# 付録A. 関連文書の責務

|文書|責務|
|---|---|
|README.md|プロジェクト概要・入口|
|CURRENT_STATUS.md|現在の運用状況|
|ROADMAP.md|中長期計画|
|06_GAS_API_SPEC.md|Gemini API利用仕様|
|10_CALENDAR_POEM_SUBSYSTEM.md|Calendar・Poemサブシステム|
|12_CONFIGURATION_MANAGEMENT.md|設定管理|
|13_GAS_OPERATION_POLICY.md|生成運用|
|18_GAS_RETRY_STRATEGY.md|Retry仕様|
|19_GEMINI_PROMPT_SPECIFICATION.md|Prompt仕様（本書）|

---

# 付録B. 更新ルール

本書は以下の場合に更新する。

- Prompt構造変更
- 品質要件変更
- AIモデル変更
- Version管理変更
- 生成ルール変更
- 文書体系変更

日常的な生成結果は記載しない。

現在の運用状況は **CURRENT_STATUS.md** を正式情報とする。

---

# 自己査読チェックリスト

- [x] 文書内矛盾なし
- [x] READMEとの責務分離
- [x] CURRENT_STATUSとの責務分離
- [x] ROADMAPとの責務分離
- [x] 00_PROJECT_CONVENTIONSとの整合
- [x] 06_GAS_API_SPECとの責務分離
- [x] 10_CALENDAR_POEM_SUBSYSTEMとの責務分離
- [x] 12_CONFIGURATION_MANAGEMENTとの責務分離
- [x] 13_GAS_OPERATION_POLICYとの責務分離
- [x] 18_GAS_RETRY_STRATEGYとの責務分離
- [x] STATUS表記統一
- [x] Single Source of Truth維持
- [x] GitHub表示崩れなし
- [x] vNext 1.3文書体系へ適合

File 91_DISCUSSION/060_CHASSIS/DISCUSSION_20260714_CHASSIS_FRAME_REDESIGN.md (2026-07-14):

# DISCUSSION_20260714_CHASSIS_FRAME_REDESIGN

## 概要
2026-07-14時点の筐体設計検討を整理する。20シリーズアルミフレームを主体とした構造へ刷新する方針とした。

## 採択事項

### 外形
- 内部有効寸法：幅160mm、高さ180mm、上底100mm、下底150mm
- 外形概略：幅約200mm、高さ約220mm、上部奥行約140mm、下部奥行約190mm

### 構造
- 主構造：20シリーズアルミフレーム
- 外装：白色塩ビ板（構造材ではなく化粧板）
- 外装固定：面ファスナー（四隅、必要時中央追加）

### 前面
- E-Paper縦置き
- 塩ビ押さえ板＋スポンジ
- 下部12×12×t0.8白色Lアングル受け
- 面ファスナーは転倒防止用途

### 側面・背面
- 側面板は調整足を隠す高さまで延長
- 背面のみフレーム面一
- 背面下部を吸気口とし、上面メッシュから自然排気

### 上面
- 網戸ネット＋塩ビ枠

### センサー
- LTR390：側面、プレパラート＋スポンジ＋塩ビ押さえ
- 人感：前面、実機確認後必要なら開口
- SPS30：本体基板設計後に配置決定

### 本体基板
- 150×100mm想定
- 背面下部へ配置
- 左右位置は後日決定

### 操作部
- OLED＋Rotary Encoderは独立ユニバーサル基板
- 背面横梁へ固定

### 熱設計
- 筐体ファンは設置しない
- 背面下吸気→自然対流→上面排気

## 前面傾斜構造
- 傾斜約15°を目標
- 厳密値ではなく現物合わせ

## フリーアングルブラケット
- 純正ブラケット高さ約34mm
- 中央固定は採用しない
- 斜面梁下端と底面突き出し梁を一点締結
- 上端は側面支柱へ当接
- ブラケットは滑り・浮き防止を担当
- 一点締結により角度調整可能

## 今後
- 本体基板配置
- SPS30配置
- 骨格切断図
- BOM
- 正面・背面・上面図

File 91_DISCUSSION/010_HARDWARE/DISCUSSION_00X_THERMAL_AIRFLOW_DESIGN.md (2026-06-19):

内容

SPS30発熱
BME680熱影響
ICS-43434配置
吸排気設計
通気孔配置
筐体内部気流
夏季評価計画

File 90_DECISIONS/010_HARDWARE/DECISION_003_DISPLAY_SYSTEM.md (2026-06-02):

# DECISION_0004_DISPLAY_DIRECTION.md

# Decision 001

表示装置候補として
E-Paper を思想的優先候補とする。

---

# Date

2026-05-27

---

# Status

Proposed

---

# Context

LCD と E-Paper の双方を検討。

LCD は：

- 高速描画
- 高表現力
- LVGL適性

を持つ。

一方 E-Paper は：

- 非発光
- 静的表示
- 長時間表示
- 電子的掛軸性

に優れる。

---

# Decision Details

現時点では、

「静けさ」

との思想整合性から、
E-Paper を優先候補とする。

ただし：

- 更新速度
- ゴースト
- UI制約

の検証は未完了。

最終採択は PoC 後に行う。

---

# Consequences

## Positive

- 思想整合性が高い
- 長時間表示向き
- 省電力化期待

## Negative

- 更新速度制約
- UI自由度低下
- Ghosting問題

# Discussion 002
# E-Paper方針

採択:

- 7.5inch 800x480 E-Paper
- XIAO ePaper Breakout Board V2

理由:

- 非発光
- 静的表示
- 電子的掛軸
- 低頻度更新

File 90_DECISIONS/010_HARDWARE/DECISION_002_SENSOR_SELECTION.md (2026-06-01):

# Discussion 002
# センサー選定結果

## 採択

- SCD41
- SGP41
- SPS30
- BME680
- LTR390
- HLK-LD2410C
- ICS-43434

## 音環境センサー

ICS-43434採択。

理由:
- MEMS
- I2S出力
- 高精度
- 校正対応可能

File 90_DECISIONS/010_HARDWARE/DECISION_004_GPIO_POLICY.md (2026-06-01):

# Discussion 003
# GPIO方針

## 旧方針

2.54mmヘッダーのみ利用

## 新方針

利用可:
- 2.54mmヘッダー
- 背面ランド

禁止:
- 1.27mm側面ランド

## ICS-43434接続

GPIO39
GPIO40
GPIO41

GPIO42予備

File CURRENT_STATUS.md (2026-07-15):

# CURRENT_STATUS

**タイトル**  
CURRENT_STATUS

**最終更新**  
2026-07-15

**文書版**  
vNext 1.3

**STATUS**  
IN_PROGRESS

**責務**  
本書は digital-kakejiku プロジェクトの現在の開発状況、完了事項、進行中事項、未着手事項および現在の課題を管理する正式文書である。

**Single Source**  
プロジェクト全体の現在状況は本書を唯一の正式情報とする。設計内容・仕様・将来計画は各設計書または ROADMAP.md を参照し、本書へ重複記載しない。

---

# 対象読者

- プロジェクトオーナー
- ハードウェア設計者
- ソフトウェア設計者
- GAS開発者
- 保守担当者

---

# 関連文書

## 前提

- docs/00_PROJECT_CONVENTIONS.md

## 参照

- README.md
- ROADMAP.md

## 関連

- docs/01_HARDWARE_OVERVIEW.md
- docs/02_SOFTWARE_OVERVIEW.md
- docs/05_WIRING_DIAGRAM.md
- docs/08_POWER_ARCHITECTURE.md
- docs/15_GAS_IMPLEMENTATION_GUIDE.md
- docs/16_TESTING_STRATEGY.md
- docs/18_GAS_RETRY_STRATEGY.md

## 後続

本書を参照するすべての設計・実装・試験・運用作業

---

# 1. 文書の目的

本書は、プロジェクトの「現在」を管理するための文書である。

以下を管理対象とする。

- 現在の開発フェーズ
- 完了した作業
- 進行中の作業
- 未着手事項
- 現在の課題
- 次工程
- 判定結果

本書は開発状況を管理するものであり、設計仕様や将来計画は管理しない。

---

# 2. プロジェクト概要

|項目|内容|
|---|---|
|プロジェクト名|digital-kakejiku|
|開発形態|個人開発|
|システム種別|据置型環境情報表示システム|
|開発方針|ドキュメント駆動開発|
|文書体系|GitHub管理|
|現行バージョン|vNext 1.3|

---

# 3. 現在の総合ステータス

|項目|STATUS|RESULT|備考|
|---|---|---|---|
|プロジェクト全体|IN_PROGRESS|GO|継続開発中|
|文書体系再構築|IN_PROGRESS|GO|vNext1.3整備中|
|システム設計|COMPLETED|PASS|基本設計完了|
|GAS基盤|IN_PROGRESS|GO|機能実装継続|
|ハードウェア|IN_PROGRESS|GO|本体基板設計中|
|統合試験|PENDING|-|未着手|

---

# 4. 現在の重点開発項目

現在は以下を優先して実施する。

|優先度|項目|STATUS|
|---|---|---|
|1|本体基板設計|IN_PROGRESS|
|2|GitHubドキュメント全面刷新|IN_PROGRESS|
|3|GAS機能実装|IN_PROGRESS|
|4|筐体設計|IN_PROGRESS|
|5|システム統合試験準備|PENDING|

---

# 5. 最新マイルストーン

|日付|内容|STATUS|RESULT|
|---|---|---|---|
|2026-07|電源基板PoC完了|COMPLETED|PASS|
|2026-07|UPS切替確認完了|COMPLETED|PASS|
|2026-07|GND設計確定|CONFIRMED|PASS|
|2026-07|USB配線方針確定|CONFIRMED|PASS|
|2026-07|文書体系全面刷新開始|IN_PROGRESS|GO|

---

# 6. Phase別進捗状況

本章はプロジェクト全体の開発フェーズごとの進捗を管理する。

各Phaseの詳細設計は関連文書を参照すること。

---

## 6.1 Phase一覧

|Phase|名称|STATUS|RESULT|備考|
|---|---|---|---|---|
|Phase 0|システム設計|COMPLETED|PASS|基本設計完了|
|Phase 1|ソフトウェア基盤構築|IN_PROGRESS|GO|GAS実装継続|
|Phase 2|ハードウェア統合|IN_PROGRESS|GO|本体基板設計継続|
|Phase 3|システム統合試験|PENDING|-|未着手|
|Phase 4|長期評価|PENDING|-|未着手|
|Phase 5|正式リリース|PENDING|-|未着手|

---

# 7. ソフトウェア進捗

## 7.1 Google Spreadsheet

|項目|STATUS|RESULT|備考|
|---|---|---|---|
|Spreadsheet初期化|COMPLETED|PASS|運用中|
|シート構成作成|COMPLETED|PASS|10シート構成|
|Script Properties設定|COMPLETED|PASS|運用中|

---

## 7.2 ConfigManager

|項目|STATUS|RESULT|備考|
|---|---|---|---|
|基本構成|COMPLETED|PASS|完成|
|system_config読込|COMPLETED|PASS|正常|
|source_config読込|COMPLETED|PASS|正常|
|Script Properties読込|COMPLETED|PASS|正常|

---

## 7.3 Logger

|項目|STATUS|RESULT|備考|
|---|---|---|---|
|System Logger|COMPLETED|PASS|正常|
|Error Logger|COMPLETED|PASS|正常|
|イベントログ|COMPLETED|PASS|正常|

---

## 7.4 Calendar Subsystem

|項目|STATUS|RESULT|備考|
|---|---|---|---|
|calendar_master生成|IMPLEMENTING|GO|実装中|
|祝日取得|IMPLEMENTING|GO|実装中|
|六曜生成|IMPLEMENTING|GO|実装中|
|干支生成|IMPLEMENTING|GO|実装中|
|月齢生成|IMPLEMENTING|GO|実装中|
|二十四節気取得|IMPLEMENTING|GO|実装中|
|七十二候取得|IMPLEMENTING|GO|実装中|

---

## 7.5 Gemini連携

|項目|STATUS|RESULT|備考|
|---|---|---|---|
|Prompt仕様|COMPLETED|PASS|確定|
|Retry仕様|COMPLETED|PASS|確定|
|Poem生成|IMPLEMENTING|GO|実装中|
|キャッシュ管理|IMPLEMENTING|GO|実装中|

---

## 7.6 GAS API

|項目|STATUS|RESULT|備考|
|---|---|---|---|
|Health Check API|COMPLETED|PASS|動作確認済み|
|Observation API|IMPLEMENTING|GO|実装中|
|Calendar API|IMPLEMENTING|GO|実装中|
|Poem API|IMPLEMENTING|GO|実装中|
|Configuration API|IMPLEMENTING|GO|実装中|

---

# 8. データ管理状況

|項目|STATUS|RESULT|備考|
|---|---|---|---|
|Spreadsheet Schema|COMPLETED|PASS|設計完了|
|設定管理|COMPLETED|PASS|運用中|
|ログ管理|COMPLETED|PASS|運用中|
|キャッシュ管理|IMPLEMENTING|GO|実装継続|

---

# 9. 現在未確定の事項

以下は現時点では正式決定していない。

|項目|状態|
|---|---|
|Geminiモデル更新手順|今後決定|
|Prompt Version運用|今後決定|
|poem_cache保持期間|今後決定|
|長期バックアップ運用|今後決定|
|正式Release判定基準|今後決定|

---

# 10. ハードウェア進捗

本章ではハードウェア開発の現在状況を管理する。

詳細設計・回路・配線仕様は各設計文書を正式情報とし、本章では進捗のみを管理する。

---

## 10.1 本体基板

|項目|STATUS|RESULT|備考|
|---|---|---|---|
|基本構成設計|COMPLETED|PASS|構成確定|
|部品選定|COMPLETED|PASS|主要部品決定|
|ピンアサイン|CONFIRMED|PASS|運用中|
|基板レイアウト|IN_PROGRESS|GO|設計継続|
|実装|PENDING|-|本体基板製作前|

---

## 10.2 電源基板

|項目|STATUS|RESULT|備考|
|---|---|---|---|
|基本設計|COMPLETED|PASS|完了|
|部品選定|COMPLETED|PASS|完了|
|PoC製作|COMPLETED|PASS|完成|
|無負荷試験|COMPLETED|PASS|正常|
|UPS切替試験|COMPLETED|PASS|正常|
|実負荷試験|PENDING|-|本体基板完成後実施|

---

## 10.3 電源アーキテクチャ

|項目|STATUS|RESULT|備考|
|---|---|---|---|
|UPS構成|CONFIRMED|PASS|運用方針確定|
|GND設計|CONFIRMED|PASS|仕様確定|
|SENSE系設計|CONFIRMED|PASS|仕様確定|
|USB-C入力|CONFIRMED|PASS|仕様確定|
|逆流防止回路|CONFIRMED|PASS|仕様確定|

---

## 10.4 配線設計

|項目|STATUS|RESULT|備考|
|---|---|---|---|
|SPI配線|CONFIRMED|PASS|仕様確定|
|I2C配線|CONFIRMED|PASS|仕様確定|
|I2S配線|CONFIRMED|PASS|仕様確定|
|USB D+/D-|CONFIRMED|PASS|ヘッダーピン経由|
|電源配線|CONFIRMED|PASS|仕様確定|

---

## 10.5 センサー

|項目|STATUS|RESULT|備考|
|---|---|---|---|
|BME680|CONFIRMED|PASS|採用|
|SCD41|CONFIRMED|PASS|採用|
|SGP41|CONFIRMED|PASS|採用|
|LTR390|CONFIRMED|PASS|採用|
|SPS30|CONFIRMED|PASS|採用|
|ICS-43434|CONFIRMED|PASS|採用|
|HLK-LD2410C|CONFIRMED|PASS|採用|

---

## 10.6 表示装置

|項目|STATUS|RESULT|備考|
|---|---|---|---|
|7.5inch E-Paper|CONFIRMED|PASS|採用|
|OLED管理画面|CONFIRMED|PASS|採用|
|ロータリーエンコーダ|CONFIRMED|PASS|採用|

---

## 10.7 筐体

|項目|STATUS|RESULT|備考|
|---|---|---|---|
|構造検討|IN_PROGRESS|GO|継続中|
|アルミフレーム設計|CONFIRMED|PASS|採用|
|塩ビパネル設計|IN_PROGRESS|GO|継続中|
|センサー配置|IN_PROGRESS|GO|継続中|
|放熱設計|IN_PROGRESS|GO|継続中|

---

# 11. ドキュメント整備状況

本章ではGitHubドキュメント体系の整備状況を管理する。

詳細仕様は各文書を正式情報とする。

|文書|STATUS|RESULT|
|---|---|---|
|README|IN_PROGRESS|GO|
|CURRENT_STATUS|IN_PROGRESS|GO|
|ROADMAP|IN_PROGRESS|GO|
|00_PROJECT_CONVENTIONS|FINALIZED|PASS|
|Hardware Documents|IN_PROGRESS|GO|
|Software Documents|IN_PROGRESS|GO|
|Operation Documents|IN_PROGRESS|GO|

---

# 12. 現在の主要課題

|優先度|課題|STATUS|
|---|---|---|
|1|本体基板完成|IN_PROGRESS|
|2|ドキュメント体系完成|IN_PROGRESS|
|3|GAS実装完了|IN_PROGRESS|
|4|筐体設計確定|IN_PROGRESS|
|5|統合試験開始|PENDING|

---

# 13. 次工程

本章では、現在の開発状況を踏まえた次工程を管理する。

ROADMAP.md に記載する中長期計画とは区別し、本章では現在着手予定の作業のみを管理する。

---

## 13.1 優先順位

|優先度|作業項目|STATUS|RESULT|備考|
|---|---|---|---|---|
|1|本体基板設計完了|IN_PROGRESS|GO|最優先|
|2|GitHubドキュメント体系完成|IN_PROGRESS|GO|vNext1.3|
|3|GAS実装完了|IN_PROGRESS|GO|Phase1継続|
|4|筐体設計確定|IN_PROGRESS|GO|本体基板と並行|
|5|システム統合試験開始|PENDING|-|本体完成後|

---

## 13.2 開始条件

|作業|開始条件|
|---|---|
|本体基板実装|設計完了|
|統合試験|本体基板完成|
|長期評価|統合試験完了|
|正式リリース|評価完了|

---

# 14. 現在のリスク

本章では、現在認識しているリスクを管理する。

設計変更や実装状況に応じて適宜更新する。

|項目|STATUS|内容|
|---|---|---|
|本体基板設計|IN_PROGRESS|レイアウト調整継続中|
|筐体設計|IN_PROGRESS|内部配置検討継続|
|ドキュメント体系|IN_PROGRESS|全面刷新作業中|
|統合試験|PENDING|ハードウェア完成待ち|

---

# 15. 保留事項

現時点で正式決定していない事項を管理する。

未定義事項は推測せず、正式決定後に更新する。

|項目|状態|
|---|---|
|正式リリース日|今後決定|
|Version採番規則|今後決定|
|Git Branch運用|今後決定|
|Commit Message規則|今後決定|
|長期保守運用|今後決定|

---

# 16. 判定

## プロジェクト判定

|項目|RESULT|備考|
|---|---|---|
|システム設計|PASS|完了|
|電源基板PoC|PASS|正常動作|
|UPS構成|PASS|確認済み|
|GND設計|PASS|確定|
|GitHub文書体系|GO|整備継続|
|本体基板|GO|設計継続|
|統合試験|-|未実施|

---

## Phase判定

|Phase|RESULT|
|---|---|
|Phase0|PASS|
|Phase1|GO|
|Phase2|GO|
|Phase3|-|
|Phase4|-|
|Phase5|-|

---

# 17. CHANGE LOG

|日付|内容|
|---|---|
|2026-07-15|vNext1.3文書体系に合わせ全面刷新。README・ROADMAP・00_PROJECT_CONVENTIONSとの責務を再整理し、CURRENT_STATUSを「現在の状況のみ」を管理する文書として再設計。STATUS・RESULT表記を統一し、Single Source of Truthに基づく構成へ変更。|
|2026-07-14|電源基板PoC完了を反映。UPS切替試験、GND設計確定、USB配線方針確定を更新。|
|2026-07-13|本体基板設計および筐体設計の進捗を更新。|
|2026-07-12|ハードウェアPoC結果を反映。|
|2026-07-11|GAS実装状況およびドキュメント整備状況を更新。|

# 付録A. STATUS運用一覧

本付録は CURRENT_STATUS.md 内で使用する STATUS の運用基準を示す。

詳細な定義は **docs/00_PROJECT_CONVENTIONS.md** を正式情報とする。

|STATUS|CURRENT_STATUSでの運用|
|---|---|
|PROPOSED|提案段階|
|PENDING|未着手|
|IMPLEMENTING|実装中（実装工程）|
|IN_PROGRESS|設計・評価・文書整備など進行中|
|COMPLETED|対象作業完了|
|CONFIRMED|仕様・方針確定|
|FINALIZED|正式仕様として確定|

---

# 付録B. RESULT運用一覧

本付録は CURRENT_STATUS.md 内で使用する RESULT の運用基準を示す。

詳細な定義は **docs/00_PROJECT_CONVENTIONS.md** を正式情報とする。

|RESULT|CURRENT_STATUSでの運用|
|---|---|
|GO|次工程へ進行可能|
|NG|修正が必要|
|PASS|試験・確認完了|
|FAIL|試験不合格|

---

# 付録C. 関連文書の責務

CURRENT_STATUS.md は開発状況のみを管理する。

各文書との責務分担は以下のとおりとする。

|文書|責務|
|---|---|
|README.md|プロジェクト概要・入口|
|CURRENT_STATUS.md|現在の状況（正式情報）|
|ROADMAP.md|将来計画・マイルストーン|
|docs/00_PROJECT_CONVENTIONS.md|共通規約|
|各設計文書|設計仕様|

CURRENT_STATUS.md には設計仕様や将来計画を記載しない。

---

# 付録D. 更新ルール

CURRENT_STATUS.md は以下のタイミングで更新する。

- Phase変更時
- STATUS変更時
- RESULT変更時
- 主要マイルストーン達成時
- 試験完了時
- 設計方針確定時
- リスクの増減時

軽微な文言修正のみでは更新履歴に記載しない。

---

# 自己査読チェックリスト

- [x] 文書内矛盾なし
- [x] READMEとの責務分離
- [x] ROADMAPとの責務分離
- [x] 00_PROJECT_CONVENTIONSとの整合
- [x] STATUS表記統一
- [x] RESULT表記統一
- [x] Single Source of Truth維持
- [x] GitHub表示崩れなし
- [x] 未確定事項を推測していない
- [x] vNext 1.3文書体系へ適合

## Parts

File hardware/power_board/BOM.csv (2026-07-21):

Ref | 品名 | 規格/フットプリント | 確認状況 | 備考
J1 | USB Type-C breakout | 1x6 2.54mm provisional | 未確認 | CC抵抗実装済み基板を使用
F1 | PTC fuse | THT radial provisional | 未確認 | 定格・ピッチ未確認
U1 | IP5306 module | 1x6 2.54mm provisional | 未確認 | 端子順 OUT_5V/GND/BAT/GND/GND/VIN を仮定
Q1 | DMG2305UX-13 | SOT-23 | 要確認 | S/G/Dと基板方向をデータシート・実物で確認
R1 | Gate pull-down | 100kΩ 0805 | 確定値 | Gate→5V_GND
U2 | TPS63802 module | 2x4 2.54mm provisional | 未確認 | VOUT×2/GND×2、VIN×2/GND×2を仮定
C1 | Input ceramic | 0.1µF 0805 | 確定値 | TPS63802入力直近
C2 | Input bulk | 470µF radial | 確定値 | 耐圧未確認
C3 | Output ceramic | 0.1µF 0805 | 確定値 | TPS63802出力直近
C4 | Output bulk | 220µF radial | 確定値 | 耐圧未確認
R2 | 5V_SENSE upper | 150kΩ 0805 | 確定値 | 5V_BUS→5V_SENSE
R3 | 5V_SENSE lower | 100kΩ 0805 | 確定値 | 5V_SENSE→SENSE_GND
R4 | Battery_SENSE upper | 100kΩ 0805 | 確定値 | BAT→Battery_SENSE
R5 | Battery_SENSE lower | 100kΩ 0805 | 確定値 | Battery_SENSE→SENSE_GND
J2 | 18650 connector | 1x2 2.54mm provisional | 未確認 | 極性を実物確認
J3 | Main board power header | 2x5 2.54mm | 仮確定 | ピン割当はREADME参照
J4 | USB D+/D- header | 1x2 2.54mm | 仮確定 | 本体基板へのUSB通信
TP1 | VBUS test point | 1pin THT | 確定用途
TP2 | 5V_BUS test point | 1pin THT | 確定用途
TP3 | 3.3V_OUT test point | 1pin THT | 確定用途
TP4 | BAT test point | 1pin THT | 確定用途
TP5 | 5V_SENSE test point | 1pin THT | 確定用途
TP6 | Battery_SENSE test point | 1pin THT | 確定用途

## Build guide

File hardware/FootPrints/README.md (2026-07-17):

# PowerModules.pretty
**PowerModules Library**  
**Release**: v2.0.0  
**Status**: RELEASED

---

# 概要

PowerModules.pretty は、DigitalKakejiku プロジェクト専用の KiCad フットプリントライブラリです。

本ライブラリは、市販モジュールを対象とした **実測ベースの高精度フットプリント**を提供します。

設計の基本方針は以下のとおりです。

- 現物実測優先
- 基板中心原点
- 機械外形重視
- レビュー必須
- GitHubによる設計履歴管理

---

# 設計思想

PowerModules.pretty は、一般的な部品ライブラリではありません。

目的は

> **実際に購入したモジュールを、そのまま安全かつ確実にPCBへ実装できるフットプリントを提供すること**

です。

そのため、

- データシート
- メーカー図面

よりも、

**現物実測値**

を優先します。

---

# 設計原則

すべてのフットプリントは以下を満たします。

- 基板中心原点
- 実測値採用
- 推測禁止
- Pad番号のみ管理
- 信号名は回路図シンボル側
- F.Fabで機械外形管理
- F.SilkSで視認性確保
- F.Courtyardで実装領域管理
- 保存・再読込確認済み

---

# ディレクトリ構成

```text
footprints/
│
├── PowerModules.pretty
│
└── docs/
    └── hardware/
        └── footprints/
            ├── README.md
            ├── Common
            │  ├── DESIGN_RATIONALE_GUIDE.md
            │  ├── FOOTPRINT_CHANGELOG.md
            │  ├── FOOTPRINT_COORDINATE_RULES.md
            │  ├── FOOTPRINT_DESIGN_WORKFLOW.md
            │  ├── FOOTPRINT_LIBRARY_RULES.md
            │  ├── FOOTPRINT_NAMING_RULES.md
            │  ├── FOOTPRINT_REVIEW_CHECKLIST.md
            │  ├── FOOTPRINT_TEMPLATE.md
            │  ├── KICAD_LIBRARY_MAINTENANCE.md
            │  └── MEASUREMENT_GUIDE.md
            ├── USB-C_BreakOut_6Pin
            │  ├── SPEC.md
            │  └── COORDINATES.md
            ├── IP5306_Module
            │  ├── SPEC.md
            │  └── COORDINATES.md
            
```

---

# リリース済みフットプリント

|名称|状態|
|---|---|
|USB_C_Breakout_6Pin|RELEASED|

---

# 開発予定

以下を順次追加予定です。

|名称|状態|
|---|---|
|TPS63802_Module|PLANNED|
|IP5306_Module|PLANNED|
|DS3231_AT24_Module|PLANNED|
|OLED_0_91_Module|PLANNED|
|SPS30_Module|PLANNED|
|LD2410C_Module|PLANNED|
|BME680_Module|PLANNED|
|LTR390_Module|PLANNED|
|XIAO_ESP32S3_Plus|PLANNED|

---

# 新規フットプリント作成手順

新規フットプリントは、以下の順番で作成します。

1. 現物入手
2. 現物実測
3. 設計値決定
4. 仕様書作成
5. 座標仕様書作成
6. KiCad入力
7. 設計レビュー
8. 修正
9. 保存
10. エディタ終了
11. ライブラリ再読込
12. PCB配置確認
13. GitHub登録

詳細は

- `FOOTPRINT_LIBRARY_RULES.md`
- `FOOTPRINT_DESIGN_WORKFLOW.md`

を参照してください。

---

# 品質保証

ライブラリへ登録するフットプリントは、以下を満たす必要があります。

- REVIEW：PASS
- PCB配置確認：PASS
- 保存確認：PASS
- ライブラリ再読込：PASS

レビュー項目は

`FOOTPRINT_REVIEW_CHECKLIST.md`

に従います。

---

# バージョン管理

本ライブラリは Semantic Versioning を採用します。

|番号|意味|
|---|---|
|Major|設計思想変更|
|Minor|新規フットプリント追加|
|Patch|誤記修正・軽微な修正|

例

- v2.0.0：Release第1版
- v2.1.0：新規モジュール追加
- v2.1.1：文書修正

---

# GitHub運用

ライブラリ更新時は以下を更新します。

- フットプリント
- 仕様書
- 座標仕様書
- ChangeLog

レビューを実施しない更新は禁止します。

---

# ライセンス

本ライブラリは DigitalKakejiku プロジェクト専用ライブラリです。

公開・再配布する場合は、ライセンス条件および実測値の出典を明記してください。

---

# 更新履歴

|Version|内容|
|---|---|
|v2.0.0|PowerModules Library 初版公開。USB_C_Breakout_6Pinを基準フットプリントとして登録。|

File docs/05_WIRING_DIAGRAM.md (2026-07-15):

# 05 Wiring Diagram

**タイトル**  
05 Wiring Diagram

**最終更新**  
2026-07-15

**文書版**  
vNext 1.3

**STATUS**  
FINALIZED

**責務**  
本書は digital-kakejiku の配線構成、インターフェース接続および信号接続方針を定義する正式設計書である。

**Single Source**  
本書は配線仕様を管理する唯一の文書である。

ピンアサイン、配線方式、信号接続およびモジュール間インターフェースは本書を正式情報とし、他文書では重複管理しない。

---

# 対象読者

- ハードウェア設計者
- 基板製作担当者
- 保守担当者

---

# 関連文書

## 前提

- docs/00_PROJECT_CONVENTIONS.md

## 参照

- README.md
- CURRENT_STATUS.md
- ROADMAP.md

## 関連

- docs/01_HARDWARE_OVERVIEW.md
- docs/08_POWER_ARCHITECTURE.md
- docs/09_SPI_RESOURCE_CONTROL.md
- docs/07_DISPLAY_UI_SPEC.md

## 後続

- 本体基板製作
- 電源基板製作
- システム統合試験

---

# 1. 文書の目的

本書はシステム全体の配線仕様を定義する。

本書では以下を管理する。

- モジュール間接続
- ピンアサイン
- バス構成
- 配線方針
- インターフェース

回路図および電源回路の詳細は管理しない。

---

# 2. 配線設計方針

本システムでは以下を基本方針とする。

- 配線交差を最小化する。
- モジュール交換を容易にする。
- 電源系と信号系を分離する。
- バス構成を明確にする。
- 保守性を優先する。
- Single Source of Truth を維持する。

---

# 3. システム配線構成

```text
              Google Apps Script
                     │
                  Wi-Fi
                     │
             XIAO ESP32S3 Plus
                     │
   ┌─────────┬────────┼─────────┐
   │         │        │         │
  SPI       I2C      I2S      GPIO
   │         │        │         │
E-Paper   Sensors   MEMS Mic  LD2410C
microSD    RTC
            OLED

        Power Board
             │
      5V / 3.3V / SENSE
             │
        Main Board
```

---

# 4. インターフェース一覧

|インターフェース|用途|詳細設計|
|---|---|---|
|SPI|E-Paper・microSD|09_SPI_RESOURCE_CONTROL.md|
|I2C|センサー・RTC・OLED|本書|
|I2S|MEMSマイク|本書|
|GPIO|人感・制御|本書|
|ADC|電源監視|08_POWER_ARCHITECTURE.md|
|USB|書込み・デバッグ|本書|

---

# 5. 本体基板インターフェース

本章では、本体基板に接続される主要インターフェースを定義する。

詳細なPCBレイアウトは本書の対象外とする。

---

## 5.1 SPI

SPIは高速通信を必要とするデバイスで共有する。

### 接続対象

|デバイス|STATUS|
|---|---|
|7.5inch E-Paper|CONFIRMED|
|microSD|CONFIRMED|

### 設計方針

- SPIバスを共有する。
- デバイスごとにCSを割り当てる。
- 配線長を最小化する。
- 詳細仕様は **09_SPI_RESOURCE_CONTROL.md** を正式情報とする。

---

## 5.2 I2C

I2Cは低速周辺機器を接続する共通バスとする。

### 接続対象

|デバイス|STATUS|
|---|---|
|BME680|CONFIRMED|
|SCD41|CONFIRMED|
|SGP41|CONFIRMED|
|LTR390|CONFIRMED|
|DS3231|CONFIRMED|
|AT24Cxx|CONFIRMED|
|OLED Display|CONFIRMED|

### 設計方針

- 単一バスで構成する。
- アドレス重複を避ける。
- 分岐を最小限とする。

---

## 5.3 I2S

I2SはMEMSマイク専用バスとして使用する。

|デバイス|STATUS|
|---|---|
|ICS-43434|CONFIRMED|

共有利用は行わない。

---

## 5.4 UART

UARTは必要なデバイスのみ接続する。

|デバイス|STATUS|
|---|---|
|SPS30|CONFIRMED|

その他用途は今後決定する。

---

## 5.5 GPIO

GPIOは制御信号および割込み信号に使用する。

|用途|STATUS|
|---|---|
|LD2410C OUT|CONFIRMED|
|Rotary Encoder|CONFIRMED|
|Push Switch|CONFIRMED|

詳細なGPIO割当は本書を正式情報とする。

---

# 6. 電源基板インターフェース

電源基板との接続は専用ヘッダーを使用する。

詳細回路は **08_POWER_ARCHITECTURE.md** を正式情報とする。

---

## 6.1 接続信号

|信号|用途|
|---|---|
|5V_OUT|5V供給|
|5V_GND|5Vリターン|
|3.3V_OUT|3.3V供給|
|3.3V_GND|3.3Vリターン|
|Battery_SENSE|電池監視|
|5V_SENSE|5V監視|
|SENSE_GND|ADC基準|

---

## 6.2 設計方針

- 電源基板と本体基板を分離する。
- コネクタ接続を基本とする。
- 保守時の交換を容易にする。
- 詳細設計は **08_POWER_ARCHITECTURE.md** を参照する。

---

# 7. USBインターフェース

USB Type-Cは開発およびデバッグ用途で使用する。

---

## 7.1 用途

- Firmware書込み
- シリアル通信
- デバッグ

---

## 7.2 配線方針

- USB D+ と D- はヘッダーピン経由で本体基板へ接続する。
- 電源ラインと信号ラインを分離する。
- USB-CコネクタのCC抵抗は使用するUSB-C基板に実装済みとし、本体基板への追加実装は行わない。

---

# 8. 配線設計共通ルール

全モジュールに共通して以下を適用する。

- 電源配線を優先して配置する。
- 信号線を可能な限り短くする。
- 配線交差を最小限とする。
- コネクタの着脱方向を統一する。
- 保守性を優先する。
- モジュール交換時に他配線へ影響しない構成とする。

---

# 9. XIAO ESP32S3 Plus ピン割り当て方針

本章では、XIAO ESP32S3 Plus のピン利用方針を定義する。

詳細なピン番号および信号一覧は、本書を正式情報とする。

---

## 9.1 基本方針

- ピンは単一責務を持つ。
- 通信バスは共有可能な範囲で共有する。
- 将来拡張用GPIOを可能な限り確保する。
- 変更時は関連文書を同時更新する。

---

## 9.2 通信バス

|インターフェース|用途|STATUS|
|---|---|---|
|SPI|E-Paper・microSD|CONFIRMED|
|I2C|センサー・RTC・OLED|CONFIRMED|
|I2S|MEMSマイク|CONFIRMED|
|UART|SPS30|CONFIRMED|
|Wi-Fi|GAS通信|CONFIRMED|

---

## 9.3 ADC

ADC入力は電源監視専用とする。

|用途|STATUS|
|---|---|
|Battery_SENSE|CONFIRMED|
|5V_SENSE|CONFIRMED|

---

# 10. モジュール間接続

本システムではモジュール間をコネクタ接続とし、保守性を優先する。

---

## 10.1 本体基板⇔電源基板

|信号|用途|
|---|---|
|5V_OUT|主電源|
|5V_GND|5Vリターン|
|3.3V_OUT|3.3V電源|
|3.3V_GND|3.3Vリターン|
|Battery_SENSE|ADC入力|
|5V_SENSE|ADC入力|
|SENSE_GND|ADC基準|

---

## 10.2 本体基板⇔OLED操作基板

|信号|用途|
|---|---|
|I2C SDA|通信|
|I2C SCL|通信|
|3.3V|電源|
|GND|GND|

---

## 10.3 本体基板⇔E-Paper

|信号|用途|
|---|---|
|SPI|通信|
|CS|チップ選択|
|DC|Data/Command|
|RST|リセット|
|BUSY|状態通知|
|5V|電源|
|GND|GND|

---

# 11. 配線品質方針

配線品質を維持するため、以下を共通ルールとする。

---

## 11.1 信号品質

- SPI配線長を最小化する。
- I2C配線は分岐を最小限とする。
- クロック線を不要に延長しない。
- 通信線を電源線から可能な範囲で離す。

---

## 11.2 電源品質

- 電源配線を太くする。
- GND配線を十分確保する。
- SENSE配線へ大電流を流さない。
- デカップリングコンデンサは対象IC近傍へ配置する。

---

## 11.3 保守性

- コネクタ名称を統一する。
- 信号名称を統一する。
- モジュール交換を容易にする。
- 配線識別を容易にする。

---

# 12. 設計上の制約

本書では以下を定義しない。

|項目|管理文書|
|---|---|
|回路図|回路図ファイル|
|PCBレイアウト|PCB設計データ|
|部品配置寸法|筐体設計書|
|ノイズ評価結果|試験結果|
|配線長実測値|製造データ|

---

# 13. 将来拡張

本章では、配線設計において考慮する将来的な拡張方針を示す。

本章は計画を示すものであり、実装を保証するものではない。

---

## 13.1 インターフェース拡張

将来的に以下の追加を検討する。

|項目|STATUS|備考|
|---|---|---|
|センサー追加用コネクタ|PROPOSED|詳細未定|
|予備GPIO活用|PROPOSED|詳細未定|
|保守用インターフェース追加|PROPOSED|詳細未定|
|通信モジュール追加|PROPOSED|詳細未定|

---

## 13.2 配線設計拡張

以下の拡張に対応できる構成を維持する。

- コネクタ追加
- センサー追加
- モジュール交換
- 配線経路変更

詳細は今後決定する。

---

# 14. 未定義事項

本書では以下を定義しない。

|項目|状態|
|---|---|
|PCBアートワーク|PCB設計データで管理|
|部品配置座標|PCB設計データで管理|
|ハーネス長|今後決定|
|ケーブル色規則|今後決定|
|製造治具|今後決定|

---

# CHANGE LOG

|日付|内容|
|---|---|
|2026-07-15|vNext 1.3文書体系に合わせ全面刷新。配線設計文書として再設計し、README・CURRENT_STATUS・ROADMAP・01_HARDWARE_OVERVIEW・08_POWER_ARCHITECTURE・09_SPI_RESOURCE_CONTROLとの責務を明確化。Single Source of Truthに基づき、配線・インターフェース・接続方針を整理し、STATUS表記・文書構成を共通規約へ統一。|
|2026-07-14|USB D+/D-ヘッダーピン経由、UPS構成、電源接続方針を反映。|
|2026-07-13|本体基板・電源基板インターフェースを更新。|

---

# 付録A. 関連文書の責務

|文書|責務|
|---|---|
|README.md|プロジェクト概要・入口|
|CURRENT_STATUS.md|現在の開発状況|
|ROADMAP.md|中長期計画|
|01_HARDWARE_OVERVIEW.md|ハードウェア全体構成|
|05_WIRING_DIAGRAM.md|配線仕様（本書）|
|07_DISPLAY_UI_SPEC.md|表示・操作インターフェース|
|08_POWER_ARCHITECTURE.md|電源設計|
|09_SPI_RESOURCE_CONTROL.md|SPI資源管理|

---

# 付録B. 更新ルール

本書は以下の場合に更新する。

- ピンアサイン変更
- 配線方式変更
- インターフェース追加・削除
- コネクタ仕様変更
- 電源接続変更
- 文書体系変更

日常的な開発進捗は記載しない。

現在の進捗は **CURRENT_STATUS.md** を正式情報とする。

---

# 自己査読チェックリスト

- [x] 文書内矛盾なし
- [x] READMEとの責務分離
- [x] CURRENT_STATUSとの責務分離
- [x] ROADMAPとの責務分離
- [x] 00_PROJECT_CONVENTIONSとの整合
- [x] 01_HARDWARE_OVERVIEWとの責務分離
- [x] 08_POWER_ARCHITECTUREとの責務分離
- [x] 09_SPI_RESOURCE_CONTROLとの責務分離
- [x] STATUS表記統一
- [x] Single Source of Truth維持
- [x] GitHub表示崩れなし
- [x] vNext 1.3文書体系へ適合

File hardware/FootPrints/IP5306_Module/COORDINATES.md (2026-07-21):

# IP5306_Module 座標仕様書
**Document ID**: PM-FP-005
**Document Name**: COORDINATES.md
**Module**: IP5306_Module
**Version**: Release v2.0
**Status**: RELEASED
**Library**: PowerModules.pretty
**Last Updated**: 2026-07-17

---

# 1. 目的

本書は PowerModules.pretty に登録する
IP5306_Module フットプリントの
KiCad入力用座標および機械寸法を管理する。

本書は本モジュールの唯一の座標基準文書とする。

---

# 2. 座標系

## 原点

```
基板中心
```

```
X = 0.00
Y = 0.00
```

---

## 軸方向

```
X+

→
```

```
Y+

↓

KiCad標準
```

---

## 単位

```
mm
```

---

## 精度

```
0.01mm
```

---

# 3. 基板外形（F.Fab）

管理レイヤ

```
F.Fab
```

外形は実測値に基づき作成する。

管理対象

- 基板外形
- 基板切欠き
- モジュール突出部

※数値は KiCad フットプリントを正本とする。

---

# 4. Courtyard

管理レイヤ

```
F.Courtyard
```

最大機械外形に対し

```
+0.50mm
```

以上確保する。

線幅

```
0.05mm
```

---

# 5. Pad仕様

Pad Type

```
Through Hole
```

Pad Shape

|Pad|形状|
|---:|---|
|1|RoundRect|
|2|Oval|
|3|Oval|
|4|Oval|
|5|Oval|
|6|Oval|

Pad1をPin1識別とする。

---

# 6. Pad配置

Padは基板右側に縦一列で配置する。

上から

|Pad|信号|
|---:|---|
|6|OUT-5V|
|5|GND|
|4|BAT|
|3|GND|
|2|GND|
|1|VIN|

Pad番号は下から昇順となる。

---

# 7. Pad座標

Pad中心座標で管理する。

|Pad|X|Y|
|---:|---:|---:|
|1|KiCadデータ準拠|KiCadデータ準拠|
|2|KiCadデータ準拠|KiCadデータ準拠|
|3|KiCadデータ準拠|KiCadデータ準拠|
|4|KiCadデータ準拠|KiCadデータ準拠|
|5|KiCadデータ準拠|KiCadデータ準拠|
|6|KiCadデータ準拠|KiCadデータ準拠|

**注記**

本書では座標値を重複管理しない。

正式値は

```
IP5306_Module.kicad_mod
```

を正本とする。

---

# 8. Pin1

Pin1

```
VIN
```

位置

```
右下
```

Pad形状

```
RoundRect
```

---

# 9. シルク

管理レイヤ

```
F.SilkS
```

表示

```
OUT-5V
GND
BAT
GND
GND
VIN
```

端子名称はPad中心と対応させる。

文字高さ

```
約1.0mm
```

線幅

```
0.15mm
```

---

# 10. Reference

Field

```
Reference
```

Layer

```
F.SilkS
```

初期値

```
J**
```

配置

モジュール中央付近。

---

# 11. Value

Field

```
Value
```

Layer

```
F.Fab
```

表示

```
IP5306_Module
```

Referenceと重ならない位置に配置する。

---

# 12. Description

```
IP5306 UPS Power Module
```

---

# 13. Keywords

```
IP5306
UPS
Battery
Boost
Charger
Power
```

---

# 14. KiCad入力順

1. 基板外形（F.Fab）
2. Pad
3. Pin1形状
4. シルク文字
5. Reference
6. Value
7. Courtyard
8. Description
9. Keywords
10. 保存
11. エディタ終了
12. ライブラリ再読込
13. PCB配置確認

---

# 15. 完成確認

確認項目

- 基板中心原点
- Pad番号
- Pad形状
- シルク文字
- Reference
- Value
- Description
- Keywords
- F.Fab
- F.Courtyard

---

# 16. Design Rationale

## 原点

採択

```
基板中心
```

理由

PowerModulesライブラリ全体との整合性を維持するため。

---

## Pad配置

採択

```
実モジュールと同一配置
```

理由

ユニバーサル基板配線およびPCB設計時の誤接続を防止するため。

---

## シルク

採択

```
端子名称表示
```

理由

配線作業およびレビュー性を向上させるため。

---

## Description / Keywords

採択

登録する。

理由

KiCadライブラリ検索性向上のため。

---

# 17. 最終判定

Design Review

```
PASS
```

Footprint Review

```
PASS
```

Library Registration

```
PASS
```

PCB Placement

```
PASS
```

---

# 18. 関連文書

- SPEC.md
- ../common/FOOTPRINT_LIBRARY_RULES.md
- ../common/FOOTPRINT_COORDINATE_RULES.md
- ../common/FOOTPRINT_REVIEW_CHECKLIST.md
- ../common/DESIGN_RATIONALE_GUIDE.md

---

# 19. 変更履歴

|Version|内容|
|---|---|
|v2.0|Release初版。PowerModules.pretty用IP5306_Module座標仕様書を制定。|

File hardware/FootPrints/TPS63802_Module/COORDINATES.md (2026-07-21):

# TPS63802_Module 座標仕様書

**Document ID**: PM-FP-006
**Document Name**: COORDINATES.md
**Module**: TPS63802_Module
**Library**: PowerModules.pretty
**Version**: Release v1.0
**Status**: RELEASED
**Author**: Digital Kakejiku Project
**Last Updated**: 2026-07-17

---

# 1. 目的

本書は
TPS63802_Module フットプリントの

- 座標
- 寸法
- レイヤ構成
- プロパティ配置

を定義する。

本書は
KiCadフットプリント再構築時の
唯一の座標仕様書とする。

---

# 2. 基本仕様

|項目|内容|
|---|---|
|単位|mm|
|原点|基板中心|
|X正方向|右|
|Y正方向|下|
|回転|0°|
|精度|0.001mm|

---

# 3. 原点

採択

```
X = 0.000
Y = 0.000
```

基板中心を
PowerModules.pretty 全体の
共通原点とする。

---

# 4. 基板外形

## 4.1 F.Fab

矩形

|項目|値|
|---|---:|
|左|-12.920|
|右|12.920|
|上|-6.425|
|下|6.425|

幅

```
25.840mm
```

高さ

```
12.850mm
```

線幅

```
0.100mm
```

Layer

```
F.Fab
```

---

## 4.2 F.Courtyard

矩形

|項目|値|
|---|---:|
|左|-13.420|
|右|13.420|
|上|-6.925|
|下|6.925|

幅

```
26.840mm
```

高さ

```
13.850mm
```

線幅

```
0.050mm
```

F.Fabから

```
0.500mm
```

外側。

Layer

```
F.Courtyard
```

---

# 5. Pad仕様

Pad Type

```
Through Hole
```

Pad Shape

```
Rect
```

Rotation

```
0°
```

Layers

```
*.Cu
*.Mask
```

---

# 6. Pad一覧

|Pad|信号|X|Y|Pad寸法|Drill|
|---:|---|---:|---:|---:|---:|
|1|VIN|-11.660|-5.080|2.625×2.580|1.000|
|2|VIN|-11.660|-2.540|2.625×2.580|1.000|
|3|GND|-11.660|2.540|2.625×2.580|0.800|
|4|GND|-11.660|5.080|2.625×2.580|0.800|
|5|VOUT|11.660|-5.080|2.540×2.580|1.000|
|6|VOUT|11.660|-2.540|2.540×2.580|1.000|
|7|GND|11.660|2.540|2.540×2.580|1.000|
|8|GND|11.660|5.080|2.540×2.580|1.000|

---

# 7. Pad配置

## 左列

```
Pad1
Pad2
Pad3
Pad4
```

中心

```
X = -11.660
```

---

## 右列

```
Pad5
Pad6
Pad7
Pad8
```

中心

```
X = 11.660
```

---

## 左右間隔

```
23.320mm
```

---

## Y座標

```
-5.080

-2.540

 2.540

 5.080
```

上下対称配置。

---

# 8. Pad寸法

## 左列

```
2.625 × 2.580
```

Pad

```
1
2
3
4
```

---

## 右列

```
2.540 × 2.580
```

Pad

```
5
6
7
8
```

---

# 9. ドリル径

Pad1

```
1.000
```

Pad2

```
1.000
```

Pad3

```
0.800
```

Pad4

```
0.800
```

Pad5

```
1.000
```

Pad6

```
1.000
```

Pad7

```
1.000
```

Pad8

```
1.000
```

---

# 10. Pad端部

左Pad

```
Pad端

-12.9725
```

F.Fab

```
-12.920
```

約

```
0.053mm
```

張り出す。

右Pad

```
12.930
```

F.Fab

```
12.920
```

約

```
0.010mm
```

張り出す。

これは
元フットプリントの
実測値を維持する。

# 11. シルク仕様

Layer

```
F.SilkS
```

---

## 11.1 左側表示

|表示|X|Y|
|---|---:|---:|
|VIN|-10.160|-5.080|
|VIN|-10.160|-2.540|
|GND|-10.160|2.540|
|GND|-10.160|5.080|

文字サイズ

```
0.800 × 0.800 mm
```

線幅

```
0.100 mm
```

---

## 11.2 右側表示

|表示|X|Y|
|---|---:|---:|
|VOUT|6.500|-5.080|
|VOUT|6.500|-2.540|
|GND|7.000|2.540|
|GND|7.000|5.080|

文字サイズ

```
0.800 × 0.800 mm
```

線幅

```
0.100 mm
```

---

## 11.3 TOP表示

|項目|値|
|---|---|
|文字|TOP|
|X|-2.540|
|Y|-5.080|
|回転|0°|
|Layer|F.SilkS|

文字サイズ

```
0.800 × 0.800 mm
```

線幅

```
0.100 mm
```

TOP表示は
モジュール方向識別用である。

---

# 12. Pin1識別

Pin1識別は
左上にL字マークを配置する。

|項目|値|
|---|---|
|縦線開始|(-15.000,-6.425)|
|縦線終了|(-15.000,-5.425)|
|横線開始|(-15.000,-6.425)|
|横線終了|(-14.000,-6.425)|

Layer

```
F.SilkS
```

線幅

```
0.100 mm
```

---

# 13. Reference

|項目|値|
|---|---|
|名称|Reference|
|値|J**|
|Layer|F.SilkS|
|X|0.000|
|Y|-0.500|
|回転|0°|
|文字サイズ|1.000 × 1.000 mm|
|線幅|0.100 mm|

---

# 14. Value

|項目|値|
|---|---|
|名称|Value|
|値|TPS63802_Module|
|Layer|F.Fab|
|X|0.000|
|Y|1.000|
|回転|0°|
|文字サイズ|1.000 × 1.000 mm|
|線幅|0.150 mm|

---

# 15. Description

KiCad Property

```
Description
```

値

```
TPS63802 Buck-Boost Power Module
```

トップレベル

```
(descr "TPS63802 Buck-Boost Power Module")
```

Propertyと
トップレベルdescrは
同一文字列とする。

---

# 16. Keywords

KiCad Tags

```
TPS63802
Buck
Boost
DCDC
Converter
Power
3V3
```

トップレベル

```
(tags "TPS63802 Buck Boost DCDC Converter Power 3V3")
```

を設定する。

---

# 17. 再構築手順

1. 新規フットプリント作成
2. 原点を基板中心へ設定
3. F.Fab作成
4. F.Courtyard作成
5. Pad1～Pad8配置
6. Pad番号設定
7. Pad寸法設定
8. ドリル径設定
9. シルク文字配置
10. TOP表示追加
11. Pin1識別追加
12. Reference配置
13. Value配置
14. Description設定
15. Tags設定
16. 保存
17. ライブラリ再読込
18. PCBへ配置
19. DRC確認
20. GitHub登録

---

# 18. 検証チェックリスト

|確認項目|基準|
|---|---|
|原点|基板中心|
|Pad数|8|
|Pad番号|1〜8|
|Pad配置|左右対称|
|Pad寸法|仕様一致|
|ドリル径|仕様一致|
|F.Fab|25.840×12.850|
|F.Courtyard|26.840×13.850|
|TOP表示|あり|
|Pin1表示|L字|
|Reference|J**|
|Value|TPS63802_Module|
|Description|設定済み|
|Tags|設定済み|
|DRC|PASS|
|ライブラリ再読込|PASS|

---

# 19. Design Rationale

## 原点

```
基板中心
```

PowerModules.pretty
全体との整合性を維持するため。

---

## Pad番号

```
番号のみ
```

信号管理を
シンボルへ集約するため。

---

## シルク

```
端子名称表示
```

配線ミス防止。

---

## TOP表示

```
TOP
```

180°逆実装防止。

---

## Pin1

```
L字マーク
```

視認性向上。

---

## Description

```
TPS63802 Buck-Boost Power Module
```

ライブラリ検索性向上。

---

## Tags

```
TPS63802
Buck
Boost
DCDC
Converter
Power
3V3
```

検索性向上。

---

# 20. 最終判定

Coordinate Review

```
PASS
```

Pad Review

```
PASS
```

Silkscreen Review

```
PASS
```

Library Registration

```
PASS
```

GitHub Registration

```
PASS
```

Release

```
APPROVED
```

---

# 21. 関連文書

- SPEC.md
- ../common/FOOTPRINT_LIBRARY_RULES.md
- ../common/FOOTPRINT_COORDINATE_RULES.md
- ../common/FOOTPRINT_REVIEW_CHECKLIST.md
- ../common/FOOTPRINT_DESIGN_WORKFLOW.md
- ../common/MEASUREMENT_GUIDE.md
- ../common/DESIGN_RATIONALE_GUIDE.md

---

# 22. 変更履歴

|Version|日付|内容|
|---|---|---|
|v1.0|2026-07-17|初版制定。TPS63802_Module(3).kicad_modに合わせ、Pad座標・寸法・F.Fab・F.Courtyard・シルク・Reference・Value・Description・Tagsを正式仕様として反映。|

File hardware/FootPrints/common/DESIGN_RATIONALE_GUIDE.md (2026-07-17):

# Design Rationale Guide
**Document ID**: PM-FP-012
**Document Name**: DESIGN_RATIONALE_GUIDE.md
**Version**: Release v2.2
**Status**: RELEASED
**Last Updated**: 2026-07-17

---

# 1. 目的

本書は PowerModules.pretty に登録するフットプリントの
設計判断（Design Rationale）を記録する方法を定義する。

本書の目的は

「何を作ったか」

ではなく

「なぜその設計を採用したのか」

を将来に残すことである。

---

# 2. 適用範囲

本書は以下に適用する。

・新規フットプリント

・仕様変更

・寸法変更

・Pad変更

・レイヤー変更

・レビュー結果

---

# 3. Design Rationaleとは

Design Rationaleとは

設計判断の背景

採択理由

不採択理由

将来見直す条件

を記録することである。

---

# 4. 基本原則

必ず以下を記録する。

・採択案

・不採択案

・採択理由

・不採択理由

・影響範囲

・将来変更条件

---

# 5. 記録タイミング

Design Rationaleを記録するタイミング

・仕様決定時

・レビュー後

・仕様変更時

・Release時

---

# 6. 記録対象

以下は必ず記録する。

・原点

・Pad

・固定穴

・機械外形

・Description

・Keywords

・レイヤー

・命名

・レビュー

---

# 7. 記録フォーマット

## 項目名

### 採択案

### 不採択案

### 採択理由

### 不採択理由

### 将来見直し条件

### 影響範囲

---

# 8. 記録例

## USB_C_Breakout_6Pin

### 項目

原点

---

採択案

```
基板中心
```

---

不採択案

```
Pad1中心
```

---

採択理由

左右対称部品では

・機械設計

・PCB配置

・レビュー

が容易になるため。

---

不採択理由

Pad1基準では

左右対称性が失われ

固定穴管理も複雑になる。

---

将来見直し条件

左右非対称部品で

基板中心が適切でない場合。

---

影響範囲

全フットプリント

---

## USBシェル寸法

採択案

```
7.40mm
```

実測

```
7.42
7.39
```

採択理由

個体差を吸収するため。

---

## Pad

採択案

```
Pad番号のみ
```

---

不採択案

```
Padへ信号名付与
```

---

採択理由

信号管理を

回路図へ集約するため。

---

## F.SilkS

採択案

端子名称表示

```
VBUS
GND
CC1
D-
D+
CC2
```

採択理由

配線確認性向上。

---

## 保存手順

採択案

```
保存

↓

エディタ終了

↓

ライブラリ再読込
```

採択理由

保存失敗を確実に検出できる。

---

# 9. 記録しない事項

以下はDesign Rationaleへ記録しない。

・操作方法

・KiCad画面説明

・一般知識

・データシート引用

---

# 10. GitHub運用

Design Rationaleは

各仕様書の

```
Design Rationale
```

章へ転記する。

共通事項は

本書のみ管理する。

---

# 11. 品質基準

レビュー時に確認する。

□ 採択理由

□ 不採択理由

□ 将来変更条件

□ 影響範囲

が記録されていること。

---

# 12. 効果

Design Rationaleを残すことで

・設計意図

・レビュー判断

・変更履歴

・将来保守

を容易にする。

---

# 13. 変更履歴

|Version|内容|
|---|---|
|v2.2|初版制定。PowerModulesライブラリ共通の設計判断記録方法を定義。|

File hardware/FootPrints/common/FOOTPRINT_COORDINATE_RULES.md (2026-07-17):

# Footprint Coordinate Rules
**Document ID**: PM-FP-010
**Version**: Release v2.2
**Status**: RELEASED

---

# 1. 目的

PowerModules.pretty に登録する全フットプリントの座標系を統一する。

本書は座標管理の唯一の基準文書とする。

---

# 2. 基本方針

すべてのフットプリントは

**基板中心**

を原点とする。

例外は認めない。

---

# 3. 座標系

X+

→

Y+

↓

KiCad標準座標系を採用する。

---

# 4. 単位

mm

管理精度

0.01mm

---

# 5. 寸法丸め

採択値

0.01mm

例

7.42

↓

7.40

理由

現物公差を吸収するため。

---

# 6. 機械寸法

測定対象

・基板

・固定穴

・Pad

・シェル

・コネクタ

・突起

---

# 7. Pad座標

Pad中心座標で管理する。

Pad外形では管理しない。

---

# 8. 固定穴

中心座標

穴径

中心距離

を管理する。

---

# 9. Courtyard

最大機械外形

+

0.50mm

---

# 10. 座標変更

変更時は

ChangeLog

更新必須。

---

# 11. Design Rationale

Pad原点案は不採択。

基板中心原点を正式採用。

---

# 12. 変更履歴

v2.2

座標規約制定。

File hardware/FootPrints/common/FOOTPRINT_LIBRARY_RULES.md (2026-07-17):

# PowerModules Library Design Rules
**Document ID**: PM-FP-001  
**Document Name**: FOOTPRINT_LIBRARY_RULES.md  
**Version**: Release v2.0  
**Status**: RELEASED  
**Last Updated**: 2026-07-17

---

# 1. 目的

本書は、DigitalKakejikuプロジェクトで使用する KiCad フットプリントライブラリ
`PowerModules.pretty`
の設計規約を定義する。

本規約の目的は以下のとおりである。

- ライブラリ品質の統一
- 再利用性の向上
- レビュー容易性の向上
- GitHub上での長期管理
- 実測値に基づく高信頼設計

本規約は PowerModules ライブラリに登録する全フットプリントへ適用する。

---

# 2. 適用範囲

本規約は以下に適用する。

- USBモジュール
- 電源モジュール
- センサーモジュール
- XIAOシリーズ
- RTCモジュール
- 表示モジュール
- その他 PowerModules.pretty に登録する全フットプリント

対象外

- 回路図シンボル
- PCB設計ルール
- 配線設計

---

# 3. 設計思想

PowerModulesライブラリは、

**「現物を正確に再現する機械部品ライブラリ」**

として設計する。

設計において優先順位は以下とする。

1. 現物実測値
2. 実装確認結果
3. メーカー図面
4. データシート
5. 推測（禁止）

---

# 4. 基本方針

## 4.1 原点

すべてのフットプリントは

**基板中心**

を原点とする。

```
        Y(-)

──────────────
      ●
    Origin
──────────────

        Y(+)
```

X方向

- 左：負
- 右：正

Y方向

- 上：負
- 下：正

---

## 4.2 単位

すべて

```
mm
```

とする。

座標は

```
0.01mm
```

単位で管理する。

---

## 4.3 実測優先

寸法は

```
現物実測
```

を採択する。

メーカー寸法との差異がある場合は

現物を優先する。

---

## 4.4 推測禁止

未確認事項は

```
未確認
```

と記載する。

設計者の推測による補完は禁止する。

---

# 5. Pad規約

## 5.1 Pad番号

Pad番号は

```
1～n
```

の連番とする。

例

```
1
2
3
4
```

---

## 5.2 信号名

Padには

```
VBUS
GND
...
```

などの信号名を持たせない。

信号名は

回路図シンボル側で管理する。

---

## 5.3 Pad形状

Pad1

```
角丸長方形
```

または

```
矩形
```

Pad2以降

```
円形
```

を基本とする。

---

# 6. レイヤー規約

|対象|Layer|
|---|---|
|基板外形|F.Fab|
|主要機械外形|F.Fab|
|Pad|Through Hole|
|固定穴|NPTH Mechanical|
|Pin1マーク|F.SilkS|
|部品名称|F.SilkS|
|端子名称|F.SilkS|
|Reference|F.SilkS(Field)|
|Value|F.Fab(Field)|
|Courtyard|F.Courtyard|

---

# 7. F.Fab

F.Fabには

- 基板外形
- コネクタ外形
- 機械部品外形

を実寸で描画する。

線幅

```
0.10mm
```

を推奨する。

---

# 8. F.SilkS

表示する情報

- 部品名称
- Pin1
- 端子名称（配置可能な場合）
- Reference

線幅

```
0.15mm
```

推奨。

Padとは重ねない。

---

# 9. F.Courtyard

最大機械外形を基準とする。

四方向へ

```
0.50mm
```

拡張する。

USBコネクタ等、

基板から突出する部品は

必ず含める。

---

# 10. Description

Descriptionには

以下を記載する。

- 部品種別
- 外形寸法
- Pin数
- Pitch
- 実測採用

---

# 11. Keywords

検索性向上のため、

一般名称を含める。

例

```
USB-C
Type-C
Breakout
6Pin
Power
```

---

# 12. 標準作業フロー

```
現物実測
      ↓
座標決定
      ↓
F.Fab
      ↓
Pad
      ↓
NPTH
      ↓
Reference
      ↓
Value
      ↓
F.SilkS
      ↓
端子名称
      ↓
F.Courtyard
      ↓
Description
      ↓
Keywords
      ↓
保存
      ↓
エディタ終了
      ↓
ライブラリ再読込
      ↓
設計レビュー
      ↓
GitHub登録
```

---

# 13. 品質基準

レビュー結果は

|判定|意味|
|---|---|
|PASS|登録可能|
|FAIL|修正必須|
|HOLD|未確認事項あり|

---

# 14. 保存確認

ライブラリ登録後は必ず

1. 保存
2. エディタ終了
3. ライブラリ再読込

を実施する。

再読込できない場合は

登録完了としない。

---

# 15. 変更履歴

|Version|内容|
|---|---|
|v2.0|Release第1版。USB_C_Breakout_6Pin完成に伴い新規制定。基板中心原点、端子名称表示、保存・再読込確認を正式規約として採用。|

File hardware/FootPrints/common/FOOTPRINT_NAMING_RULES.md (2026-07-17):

# PowerModules Library Naming Rules
**Document ID**: PM-FP-002  
**Document Name**: FOOTPRINT_NAMING_RULES.md  
**Version**: Release v2.0  
**Status**: RELEASED  
**Last Updated**: 2026-07-17

---

# 1. 目的

本書は、PowerModules.pretty ライブラリに登録するフットプリントの命名規則を定義する。

目的は以下のとおりである。

- ライブラリ検索性向上
- 命名の一貫性維持
- GitHub管理の容易化
- 他ライブラリとの差別化
- レビュー品質向上

---

# 2. 適用範囲

本規約はPowerModules.prettyへ登録する全フットプリントに適用する。

対象例

- USBモジュール
- 電源モジュール
- MCUモジュール
- RTC
- センサーモジュール
- Displayモジュール
- その他モジュール

---

# 3. 基本方針

名称は

**部品の用途が分かること**

を最優先とする。

型番のみの命名は禁止する。

例

NG

```
Module001
```

OK

```
USB_C_Breakout_6Pin
```

---

# 4. フットプリント名

基本形式

```
機能_特徴
```

例

```
USB_C_Breakout_6Pin
```

```
TPS63802_Module
```

```
IP5306_Module
```

```
DS3231_AT24_Module
```

```
SPS30_Module
```

---

# 5. 使用可能文字

使用する文字

```
A～Z
a～z
0～9
_
```

使用しない文字

```
空白
-
/
\
()
[]
{}
.
,
```

---

# 6. 略称規則

USB Type-C

↓

```
USB_C
```

Breakout

↓

```
Breakout
```

Module

↓

```
Module
```

OLED

↓

```
OLED
```

RTC

↓

```
RTC
```

MCU

↓

```
MCU
```

---

# 7. バージョン番号

フットプリント名へ

```
_v1
_v2
```

などは付加しない。

バージョン管理はGitで行う。

---

# 8. Reference

Referenceは

KiCadフィールドを使用する。

通常テキストは禁止。

代表例

|部品|Reference|
|---|---|
|Connector|J**|
|IC|U**|
|Resistor|R**|
|Capacitor|C**|
|Inductor|L**|
|Switch|SW**|
|Fuse|F**|

PowerModulesでは

USBモジュール等も

```
J**
```

を使用する。

---

# 9. Value

Valueは

フットプリント名と一致させる。

例

```
USB_C_Breakout_6Pin
```

---

# 10. Description

Descriptionには

最低限以下を含める。

- 部品名称
- 基板寸法
- Pin数
- Pitch
- 実測採用

例

```
USB Type-C 6-pin breakout module,
PCB 21.6 × 14.2 mm,
2.54 mm pitch,
measured from actual module
```

---

# 11. Keywords

検索性向上のため

一般名称を複数登録する。

例

```
USB-C
Type-C
Breakout
6Pin
Power
Module
```

例

```
TPS63802
Buck-Boost
Power
Converter
Module
```

---

# 12. 部品名称（F.SilkS）

部品名称は

短く

判読しやすくする。

例

```
USB-C 6P
```

```
TPS63802
```

```
RTC
```

---

# 13. 端子名称

配置可能な場合は

F.SilkSへ

端子名称を追加する。

例

```
VBUS
GND
CC1
D-
D+
CC2
```

Pad番号とは独立して管理する。

---

# 14. GitHub文書名

仕様書

```
USB_C_Breakout_6Pin.md
```

座標仕様書

```
USB_C_Breakout_6Pin_COORDINATES.md
```

レビュー記録

```
USB_C_Breakout_6Pin_REVIEW.md
```

---

# 15. PowerModules推奨命名例

```
USB_C_Breakout_6Pin
```

```
IP5306_Module
```

```
TPS63802_Module
```

```
DS3231_AT24_Module
```

```
OLED_0_91_Module
```

```
SPS30_Module
```

```
LD2410C_Module
```

```
BME680_Module
```

```
LTR390_Module
```

---

# 16. 変更履歴

|Version|内容|
|---|---|
|v2.0|Release第1版。PowerModules.pretty命名規則を制定。|

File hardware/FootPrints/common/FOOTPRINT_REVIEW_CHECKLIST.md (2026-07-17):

# PowerModules Library Review Checklist
**Document ID**: PM-FP-003  
**Document Name**: FOOTPRINT_REVIEW_CHECKLIST.md  
**Version**: Release v2.0  
**Status**: RELEASED  
**Last Updated**: 2026-07-17

---

# 1. 目的

本書は、PowerModules.pretty に登録する全フットプリントについて、設計品質を一定に保つためのレビュー基準を定義する。

レビュー担当者および設計者は、本チェックリストに従って確認を実施する。

---

# 2. 適用範囲

本書は以下に適用する。

- 新規フットプリント
- 改訂フットプリント
- ライブラリ更新時
- GitHub登録前レビュー

---

# 3. 判定基準

|判定|意味|
|---|---|
|PASS|仕様どおりで登録可能|
|FAIL|設計不整合があり修正必須|
|HOLD|確認不足または保留事項あり|

レビューは PASS 以外では登録してはならない。

---

# 4. レビュー手順

レビューは以下の順番で実施する。

1. 文書レビュー
2. 寸法レビュー
3. 座標レビュー
4. レイヤーレビュー
5. KiCad入力レビュー
6. 保存確認
7. ライブラリ再読込
8. GitHub登録

---

# 5. 文書レビュー

## 5.1 文書情報

- [ ] 文書ID
- [ ] 文書名
- [ ] Version
- [ ] 更新日
- [ ] Status

---

## 5.2 基本仕様

- [ ] 基板寸法
- [ ] Pin数
- [ ] Pitch
- [ ] 固定穴
- [ ] 原点

---

# 6. 寸法レビュー

## 6.1 基板

- [ ] 幅
- [ ] 高さ
- [ ] 厚み（必要な場合）

---

## 6.2 Pad

- [ ] Pad数
- [ ] Pad径
- [ ] ドリル径
- [ ] Pad形状
- [ ] Padピッチ

---

## 6.3 固定穴

- [ ] 穴径
- [ ] 穴間距離
- [ ] NPTH

---

## 6.4 機械外形

- [ ] USBシェル
- [ ] コネクタ突出量
- [ ] 実装高さ（必要時）

---

# 7. 座標レビュー

- [ ] 原点が基板中心
- [ ] X方向確認
- [ ] Y方向確認
- [ ] Pad座標
- [ ] 固定穴座標
- [ ] 外形座標
- [ ] Courtyard座標

---

# 8. レイヤーレビュー

## F.Fab

- [ ] 基板外形
- [ ] 機械外形
- [ ] 寸法整合

---

## F.SilkS

- [ ] Pin1
- [ ] 部品名称
- [ ] 端子名称
- [ ] Reference

Padと重なっていないこと。

---

## F.Courtyard

- [ ] 最大外形
- [ ] USB突出部を含む
- [ ] 四方向0.50mm

---

## Pad

- [ ] Through Hole
- [ ] All Copper
- [ ] F.Mask
- [ ] B.Mask

---

## 固定穴

- [ ] NPTH Mechanical
- [ ] Pad番号なし

---

# 9. フィールドレビュー

## Reference

- [ ] KiCadフィールド
- [ ] 通常テキストではない
- [ ] 初期値が適切

---

## Value

- [ ] フットプリント名一致
- [ ] F.Fab

---

## Description

- [ ] 登録済
- [ ] 寸法記載
- [ ] 実測採用を記載

---

## Keywords

- [ ] 登録済
- [ ] 検索性良好

---

# 10. 保存レビュー

保存後に必ず確認する。

- [ ] 保存成功
- [ ] エディタ終了
- [ ] ライブラリ再読込
- [ ] フットプリントが表示される
- [ ] Description保持
- [ ] Keywords保持

---

# 11. PCBレビュー

テストPCBへ配置して確認する。

- [ ] 向き
- [ ] 座標
- [ ] Pad番号
- [ ] Reference
- [ ] Courtyard
- [ ] DRCエラーなし

---

# 12. GitHubレビュー

- [ ] 仕様書更新
- [ ] 座標仕様書更新
- [ ] ChangeLog更新
- [ ] コミット準備完了

---

# 13. レビュー記録

|項目|判定|備考|
|---|---|---|
|文書|PASS|| 
|寸法|PASS|| 
|座標|PASS|| 
|レイヤー|PASS|| 
|保存|PASS|| 
|PCB|PASS|| 
|GitHub|PASS|| 

---

# 14. 最終判定

|判定|担当者|日付|
|---|---|---|
|PASS|||

PASSになったフットプリントのみ、PowerModules.pretty の正式ライブラリへ登録する。

---

# 15. 変更履歴

|Version|内容|
|---|---|
|v2.0|Release第1版。PowerModulesライブラリ共通レビュー手順を制定。|

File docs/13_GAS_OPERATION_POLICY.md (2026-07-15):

# 13 GAS Operation Policy

**タイトル**  
13 GAS Operation Policy

**最終更新**  
2026-07-15

**文書版**  
vNext 1.3

**STATUS**  
FINALIZED

**責務**  
本書は Google Apps Script の運用ポリシー、定期実行、ジョブ管理、データ更新および運用ルールを定義する正式設計書である。

**Single Source**  
本書は GAS の運用ポリシーを管理する唯一の文書である。

スケジュール、ジョブ責務、運用方針および更新タイミングは本書を正式情報とし、他文書では重複管理しない。

---

# 対象読者

- GAS開発者
- システム設計者
- 保守担当者

---

# 関連文書

## 前提

- docs/00_PROJECT_CONVENTIONS.md

## 参照

- README.md
- CURRENT_STATUS.md
- ROADMAP.md

## 関連

- docs/06_GAS_API_SPEC.md
- docs/10_CALENDAR_POEM_SUBSYSTEM.md
- docs/12_CONFIGURATION_MANAGEMENT.md
- docs/14_SPREADSHEET_SCHEMA.md
- docs/18_GAS_RETRY_STRATEGY.md

## 後続

- GAS実装
- 定期実行設定
- システム運用

---

# 1. 文書の目的

本書は Google Apps Script の運用ポリシーを定義する。

本書では以下を管理する。

- 定期実行
- ジョブ構成
- 更新タイミング
- 運用方針
- Scheduler責務
- 運用ルール

実装コードやSpreadsheet構造の詳細は管理しない。

---

# 2. 運用設計方針

本システムでは以下を基本方針とする。

- Google Apps Script が定期実行を管理する。
- Calendar生成とPoem生成を分離する。
- Retryを考慮した運用とする。
- Spreadsheetを正式情報とする。
- Single Source of Truth を維持する。
- ESP32は運用スケジュールを管理しない。

---

# 3. 運用構成

```text
Time Trigger
      │
      ▼
 Scheduler
      │
      ├─────────────┐
      ▼             ▼
Calendar Job   Poem Job
      │             │
      ▼             ▼
Spreadsheet   Gemini API
```

---

# 4. 定期ジョブ

|ジョブ|用途|STATUS|
|---|---|---|
|Calendar Job|暦生成・更新|CONFIRMED|
|Poem Job|AI詩生成|CONFIRMED|
|Health Check|運用確認|CONFIRMED|
|Maintenance|保守処理|CONFIRMED|

---

# 5. 定期実行

Google Apps Script の Time Trigger により定期実行する。

---

## 5.1 基本方針

- ジョブごとに独立して実行する。
- ジョブ間の依存を最小限とする。
- Retry を考慮したスケジュールとする。
- 実行結果を必要に応じてログへ記録する。

---

## 5.2 実行順序

|順序|ジョブ|
|---:|---|
|1|Calendar Job|
|2|Poem Job|
|3|Maintenance Job|

---

## 5.3 実行タイミング

現在採用している運用は以下とする。

|ジョブ|実行時刻|STATUS|
|---|---|---|
|Calendar Job|02:00|CONFIRMED|
|Poem Job|02:10|CONFIRMED|

Retry 時刻の詳細は **18_GAS_RETRY_STRATEGY.md** を正式情報とする。

---

# 6. Calendar Job

Calendar Job は暦情報を管理する。

---

## 責務

- Calendar生成
- 翌年生成
- 必要時更新
- 整合性維持

---

## 基本方針

- Calendar を正式情報とする。
- 年単位で管理する。
- 外部データソースを利用する。
- 更新内容を必要に応じて記録する。

Calendar仕様は **10_CALENDAR_POEM_SUBSYSTEM.md** を正式情報とする。

---

# 7. Poem Job

Poem Job は AI 詩生成を管理する。

---

## 責務

- poem_cache確認
- AI生成
- Retry
- キャッシュ更新

---

## 基本方針

- poem_cache を優先利用する。
- Gemini API は必要時のみ利用する。
- 同一日の再生成は明示的操作時のみ実施する。
- Retry に対応する。

---

# 8. Health Check

Health Check はシステム状態を確認する。

---

## 責務

- GAS動作確認
- Spreadsheet接続確認
- Config確認
- 基本機能確認

---

## 基本方針

- 障害を早期検知する。
- 結果を必要に応じてSystem Logへ記録する。
- 異常時は保守者が原因を追跡できる情報を残す。

Health Check API の仕様は **06_GAS_API_SPEC.md** を正式情報とする。

---

# 9. Maintenance Job

Maintenance Job はシステム保守に必要な定期処理を実施する。

---

## 9.1 責務

- 定期保守
- キャッシュ整合性確認
- 不要データ確認
- システム診断

---

## 9.2 基本方針

- 他ジョブへ影響を与えない。
- 必要最小限の処理とする。
- 異常時はError Logへ記録する。
- 保守結果を必要に応じてSystem Logへ記録する。

Maintenance内容の詳細は今後決定する。

---

# 10. 運用データ

GAS運用で利用する正式データを示す。

|データ|正式管理|
|---|---|
|system_config|Spreadsheet|
|source_config|Spreadsheet|
|calendar_master|Spreadsheet|
|poem_cache|Spreadsheet|
|Observation Log|Spreadsheet|
|System Log|Spreadsheet|
|Error Log|Spreadsheet|

Single Source of Truth に基づき、同一情報を複数箇所で保持しない。

---

# 11. ジョブ依存関係

ジョブ間の依存関係を以下に示す。

```text
Calendar Job
      │
      ▼
calendar_master
      │
      ▼
Poem Job
      │
      ▼
poem_cache
```

Calendar Job が生成した暦情報を Poem Job が利用する。

Health Check および Maintenance Job は独立して動作する。

---

# 12. 設計方針

GAS運用は以下を設計原則とする。

---

## 単一責務

- Calendar Job は暦管理のみ担当する。
- Poem Job は詩生成のみ担当する。
- Maintenance Job は保守処理のみ担当する。
- Health Check は診断のみ担当する。

---

## Single Source of Truth

|情報|正式管理|
|---|---|
|設定|Spreadsheet|
|Calendar|calendar_master|
|AI詩|poem_cache|
|Secret|Script Properties|

---

## 保守性

- ジョブを独立して管理する。
- Schedulerを共通化する。
- Retry処理を共通化する。
- ジョブ追加を容易にする。

---

## 拡張性

将来的なジョブ追加に対応できる構成を維持する。

---

# 13. Retry運用

ジョブ失敗時は、共通Retry方針に従って再実行する。

---

## 13.1 基本方針

- Retry可能な障害とRetry不可の障害を分離する。
- Retry回数および待機時間は設定値として管理する。
- Retry結果をSystem LogまたはError Logへ記録する。
- 最大回数を超えた場合は処理を終了する。
- 無限Retryを禁止する。

Retryアルゴリズムおよび待機時間の詳細は **18_GAS_RETRY_STRATEGY.md** を正式情報とする。

---

## 13.2 定期ジョブのRetry

現在採用する定期ジョブのRetry運用は以下とする。

|ジョブ|初回実行|Retry間隔|最大Retry回数|STATUS|
|---|---:|---:|---:|---|
|Calendar Job|02:00|30分|3回|CONFIRMED|
|Poem Job|02:10|30分|3回|CONFIRMED|

Retry回数は初回実行を含まない。

---

## 13.3 Retry終了条件

以下のいずれかに該当した場合、Retryを終了する。

- 処理が正常終了した場合
- 最大Retry回数へ到達した場合
- Retry不可と判定された場合
- 前提データの欠損により継続不能と判定された場合
- 認証異常など、再試行で解消しない障害が発生した場合

---

# 14. 手動実行

定期実行とは別に、保守目的の手動実行を許可する。

---

## 14.1 手動実行対象

|処理|実行経路|STATUS|
|---|---|---|
|Calendar再生成|GAS保守機能|CONFIRMED|
|任意年・任意期間のCalendar再生成|GAS保守機能|CONFIRMED|
|Poem再生成|背面OLED管理メニュー経由|CONFIRMED|
|Health Check|GAS保守機能|CONFIRMED|
|System Logger確認|GAS保守機能|CONFIRMED|

---

## 14.2 手動実行方針

- 実行対象を明示する。
- 認証後のみ実行する。
- 定期ジョブとの競合を避ける。
- 実行結果をログへ記録する。
- 既存データを上書きする場合は対象範囲を限定する。
- Secret情報をリクエスト、レスポンスおよびログへ残さない。

---

# 15. Calendar運用

Calendarデータは過去・現在・将来の表示および詩生成で利用する。

---

## 15.1 保持範囲

`calendar_master` は以下の期間を管理する。

- 過去5年
- 当年
- 翌年

具体的な行構造および一意性制約は **14_SPREADSHEET_SCHEMA.md** を正式情報とする。

---

## 15.2 年次更新

毎年12月1日に翌年分を生成する。

既に対象年のデータが存在する場合の更新方式は、Calendar実装仕様に従う。

---

## 15.3 データ取得方針

|暦情報|取得方針|STATUS|
|---|---|---|
|二十四節気|公的な暦情報を取得する|CONFIRMED|
|七十二候|`source_config`で管理する外部情報源から取得する|CONFIRMED|
|祝日|`source_config`で管理する情報源を利用する|CONFIRMED|
|月齢|`source_config`で管理する情報源を利用する|CONFIRMED|
|六曜|`source_config`で管理する情報源を利用する|CONFIRMED|
|干支|`source_config`で管理する情報源を利用する|CONFIRMED|

二十四節気および七十二候は、独自計算による推定値を正式情報として使用しない。

---

# 16. Poem運用

Poemデータは、定期生成および明示的な手動再生成によって管理する。

---

## 16.1 定期生成

Poem Job は対象日の暦情報および観測情報を参照し、必要な詩を生成する。

生成済みデータが有効な場合は `poem_cache` を利用する。

---

## 16.2 手動再生成

背面OLED管理メニューから、任意日の詩再生成を要求できる。

手動再生成時は以下を満たす。

- 対象日を明示する。
- GASへ再生成要求を送信する。
- 生成結果を `poem_cache` へ保存する。
- 実行結果をログへ記録する。
- 失敗時はRetry仕様に従う。

---

## 16.3 ESP32の責務

ESP32は以下を行わない。

- Gemini APIの直接呼出し
- Prompt生成
- Calendar生成
- `system_config`および`source_config`の編集

ESP32は管理メニュー表示時など、必要な時点でGASへ設定情報を問い合わせる。

---

# 17. 排他制御

同一ジョブまたは依存関係を持つジョブの重複実行を防止する。

---

## 17.1 基本方針

- 同一ジョブの多重実行を禁止する。
- Calendar Job実行中のPoem Job開始を制御する。
- 排他取得失敗時は無理に処理を継続しない。
- 排他状態を必要に応じてSystem Logへ記録する。

---

## 17.2 競合時の扱い

|競合|対応|
|---|---|
|同一ジョブの重複|後続処理を中止または延期する|
|Calendar更新中のPoem生成|Calendar更新完了後に実行する|
|手動実行と定期実行の競合|既存処理を優先する|
|Spreadsheet更新競合|排他制御後に再判定する|

具体的なロック実装はGAS実装コードで管理する。

---

# 18. ログ運用

各ジョブは処理内容に応じてログを出力する。

ログ形式は **03_LOG_FORMAT.md** を正式情報とする。

|処理|記録先|
|---|---|
|ジョブ開始・終了|System Log|
|手動実行|Event Log|
|Retry開始・成功|System Log|
|最終失敗|Error Log|
|設定変更|Event Log|
|想定外例外|Error Log|

Secret、認証情報および未加工のPOST bodyをログまたはSpreadsheetへ保存してはならない。

---

# 19. 障害時運用

障害発生時は、障害分類とRetry可否に基づいて処理する。

---

## 19.1 基本方針

- 障害内容を分類する。
- Retry可能な場合のみ再実行する。
- 復旧不能な場合はError Logへ記録する。
- 他ジョブへ障害を波及させない。
- 前回正常データが利用可能な場合は保持する。

---

## 19.2 最終失敗時

最大Retry回数到達後も処理が成功しない場合は、以下を実施する。

1. 対象ジョブを終了する。
2. Error Logへ記録する。
3. 既存の正常データを破壊しない。
4. 次回定期実行または手動実行まで待機する。
5. 必要に応じて保守画面で状態を確認できるようにする。

通知方式は未定義であり、今後決定する。

---

# 20. 制約事項

本書ではGASの運用方針を定義し、以下は対象外とする。

|項目|管理先|
|---|---|
|APIリクエスト・レスポンス|06_GAS_API_SPEC.md|
|Calendar・Poem論理構成|10_CALENDAR_POEM_SUBSYSTEM.md|
|設定項目|12_CONFIGURATION_MANAGEMENT.md|
|Spreadsheet構造|14_SPREADSHEET_SCHEMA.md|
|GAS実装手順|15_GAS_IMPLEMENTATION_GUIDE.md|
|試験方法|16_TESTING_STRATEGY.md|
|障害調査手順|17_TROUBLESHOOTING.md|
|Retryアルゴリズム|18_GAS_RETRY_STRATEGY.md|
|Prompt内容|19_GEMINI_PROMPT_SPECIFICATION.md|

---

# 21. 未定義事項

|項目|状態|
|---|---|
|Maintenance Jobの詳細処理|今後決定|
|運用通知方式|今後決定|
|ジョブ実行履歴の保持期間|今後決定|
|障害時の自動通知先|今後決定|
|Time Trigger再構築手順|今後決定|
|運用停止・再開手順|今後決定|

---

# CHANGE LOG

|日付|内容|
|---|---|
|2026-07-15|vNext 1.3文書体系に合わせ全面刷新。GAS運用方針のSingle Sourceとして、定期ジョブ、実行順序、実行時刻、Retry、手動実行、排他制御、ログおよび障害時運用を整理。関連文書との責務を分離し、STATUS・RESULT・Markdown記法を共通規約へ統一。|
|2026-07-14|Calendar Jobを02:00、Poem Jobを02:10に開始し、30分間隔で最大3回Retryする方針を反映。|
|2026-07-14|毎年12月1日の翌年Calendar生成、任意年・任意期間の再生成および背面OLEDからのPoem再生成方針を反映。|
|2026-06-21|GAS Phase1基盤実装およびHealth Check結果を反映。|

---

# 付録A. 関連文書の責務

|文書|責務|
|---|---|
|README.md|プロジェクト概要・入口|
|CURRENT_STATUS.md|現在の進捗と実績|
|ROADMAP.md|中長期計画|
|06_GAS_API_SPEC.md|API契約|
|10_CALENDAR_POEM_SUBSYSTEM.md|Calendar・Poemの論理設計|
|12_CONFIGURATION_MANAGEMENT.md|設定管理方針|
|13_GAS_OPERATION_POLICY.md|GAS運用方針（本書）|
|14_SPREADSHEET_SCHEMA.md|保存構造と制約|
|15_GAS_IMPLEMENTATION_GUIDE.md|実装手順|
|16_TESTING_STRATEGY.md|試験方針|
|17_TROUBLESHOOTING.md|障害調査と復旧手順|
|18_GAS_RETRY_STRATEGY.md|Retry詳細|
|19_GEMINI_PROMPT_SPECIFICATION.md|詩生成条件|

---

# 付録B. 更新ルール

本書は以下の場合に更新する。

- 定期ジョブ追加・削除
- 実行時刻変更
- ジョブ依存関係変更
- 手動実行方式変更
- 排他制御方針変更
- CalendarまたはPoem運用変更
- 障害時運用変更
- 文書体系変更

日々の実行結果や一時的な障害状況は記載しない。

現在の状況は **CURRENT_STATUS.md** を正式情報とする。

---

# 自己査読チェックリスト

- [x] 文書内矛盾なし
- [x] READMEとの責務分離
- [x] CURRENT_STATUSとの責務分離
- [x] ROADMAPとの責務分離
- [x] 00_PROJECT_CONVENTIONSとの整合
- [x] 06_GAS_API_SPECとの責務分離
- [x] 10_CALENDAR_POEM_SUBSYSTEMとの責務分離
- [x] 12_CONFIGURATION_MANAGEMENTとの責務分離
- [x] 14_SPREADSHEET_SCHEMAとの責務分離
- [x] 18_GAS_RETRY_STRATEGYとの責務分離
- [x] STATUS表記統一
- [x] RESULT表記統一
- [x] Single Source of Truth維持
- [x] Secretおよび未加工POST bodyの保存禁止を反映
- [x] GitHub表示崩れなし
- [x] vNext 1.3文書体系へ適合

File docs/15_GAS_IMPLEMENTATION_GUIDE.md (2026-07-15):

# 15 GAS Implementation Guide

**タイトル**  
15 GAS Implementation Guide

**最終更新**  
2026-07-15

**文書版**  
vNext 1.3

**STATUS**  
FINALIZED

**責務**  
本書は Google Apps Script の実装手順、モジュール構成、開発規約および実装ガイドラインを定義する正式設計書である。

**Single Source**  
本書は GAS 実装方針を管理する唯一の文書である。

実装順序、モジュール責務、開発ルールおよび実装ガイドラインは本書を正式情報とし、他文書では重複管理しない。

---

# 対象読者

- GAS開発者
- 保守担当者

---

# 関連文書

## 前提

- docs/00_PROJECT_CONVENTIONS.md

## 参照

- README.md
- CURRENT_STATUS.md
- ROADMAP.md

## 関連

- docs/02_SOFTWARE_OVERVIEW.md
- docs/06_GAS_API_SPEC.md
- docs/11_SECURITY_MANAGEMENT.md
- docs/12_CONFIGURATION_MANAGEMENT.md
- docs/13_GAS_OPERATION_POLICY.md
- docs/14_SPREADSHEET_SCHEMA.md

## 後続

- GAS実装
- 単体試験
- 統合試験

---

# 1. 文書の目的

本書は Google Apps Script の実装ガイドラインを定義する。

本書では以下を管理する。

- 実装順序
- モジュール構成
- 実装ルール
- コーディング方針
- 開発手順

API仕様、Spreadsheet構造およびRetry仕様は本書では管理しない。

---

# 2. 実装方針

本システムでは以下を基本方針とする。

- モジュール単位で実装する。
- 単一責務を維持する。
- 共通処理を再利用する。
- Spreadsheetを正式情報とする。
- Secret情報は Script Properties で管理する。
- Single Source of Truth を維持する。

---

# 3. 実装構成

```text
Google Apps Script

├── API
├── Managers
├── Services
├── Utilities
├── Logger
├── Retry
├── Health Check
└── Scheduler
```

---

# 4. 実装順序

|順序|モジュール|STATUS|
|---:|---|---|
|1|Logger|CONFIRMED|
|2|Configuration Manager|CONFIRMED|
|3|Health Check|CONFIRMED|
|4|Calendar Manager|CONFIRMED|
|5|Poem Manager|CONFIRMED|
|6|API|CONFIRMED|
|7|Scheduler|CONFIRMED|
|8|Maintenance|PENDING|

---

# 5. Logger

Logger はシステム全体のログ出力を担当する。

---

## 5.1 責務

- Observation Log出力
- Event Log出力
- Error Log出力
- System Log出力

---

## 5.2 基本方針

- ログ形式を統一する。
- Secret情報を保存しない。
- Logger以外から直接Spreadsheetを書き込まない。
- ログ仕様は **03_LOG_FORMAT.md** を正式情報とする。

---

# 6. Configuration Manager

Configuration Manager は設定情報を取得・管理する。

---

## 6.1 責務

- system_config取得
- source_config取得
- 設定検証
- 設定キャッシュ管理

---

## 6.2 基本方針

- Spreadsheetを正式情報とする。
- Secretは取得しない。
- 必須設定を検証する。
- Configuration APIと責務を分離する。

---

# 7. Health Check

Health Check はシステムの健全性を確認する。

---

## 7.1 責務

- Spreadsheet確認
- Script Properties確認
- Configuration確認
- Logger確認

---

## 7.2 基本方針

- 起動確認を容易にする。
- 障害箇所を特定しやすくする。
- 実行結果をSystem Logへ記録する。

---

# 8. Calendar Manager

Calendar Manager は暦情報を生成する。

---

## 責務

- Calendar生成
- Calendar更新
- Calendar取得

---

## 基本方針

- calendar_masterを正式情報とする。
- 外部データソースを利用する。
- Spreadsheetへ保存する。

詳細仕様は **10_CALENDAR_POEM_SUBSYSTEM.md** を正式情報とする。

---

# 9. Poem Manager

Poem Manager はAI詩生成を担当する。

---

## 責務

- Prompt生成
- Gemini呼出し
- poem_cache更新

---

## 基本方針

- poem_cacheを優先利用する。
- Gemini APIを必要時のみ利用する。
- Prompt仕様を外部管理する。

Prompt仕様は **19_GEMINI_PROMPT_SPECIFICATION.md** を正式情報とする。

---

# 10. API

API モジュールは ESP32 との通信窓口を提供する。

---

## 責務

- API受付
- 入力検証
- Manager呼出し
- JSONレスポンス生成

---

## 基本方針

- APIは単一責務を維持する。
- Validationを共通化する。
- エラー応答を統一する。

API仕様は **06_GAS_API_SPEC.md** を正式情報とする。

---

# 11. Scheduler

Scheduler は Time Trigger により各ジョブを実行する。

---

## 責務

- Calendar Job起動
- Poem Job起動
- Maintenance Job起動

---

## 基本方針

- ジョブを独立して管理する。
- Retryを考慮する。
- 排他制御を行う。

運用仕様は **13_GAS_OPERATION_POLICY.md** を正式情報とする。

---

# 12. Retry Manager

Retry Manager は共通Retry処理を担当する。

---

## 責務

- Retry判定
- Retry待機時間管理
- Retry終了判定

---

## 基本方針

- 共通Retry処理を提供する。
- 無限Retryを禁止する。
- Retry結果をLoggerへ通知する。

Retry仕様は **18_GAS_RETRY_STRATEGY.md** を正式情報とする。

---

# 13. Maintenance

Maintenance モジュールは保守用処理を担当する。

---

## 13.1 責務

- 保守ジョブ実行
- キャッシュ整合性確認
- システム診断
- 保守情報出力

---

## 13.2 基本方針

- 他モジュールへ影響を与えない。
- 保守処理を独立管理する。
- 実行結果をSystem Logへ記録する。
- Secret情報を出力しない。

---

# 14. 共通ユーティリティ

Utilities は複数モジュールから利用される共通機能を提供する。

---

## 14.1 責務

- JSON操作
- 日時処理
- バリデーション
- 共通定数
- 共通例外処理

---

## 14.2 基本方針

- ビジネスロジックを持たない。
- 再利用性を優先する。
- モジュール依存を持たない。

---

# 15. 実装ルール

Google Apps Script 全体で以下を適用する。

---

## 15.1 モジュール構成

- モジュール単位でファイルを分割する。
- 単一責務を維持する。
- 相互依存を最小限とする。

---

## 15.2 コーディング方針

- 共通処理はUtilityへ集約する。
- Magic Numberを使用しない。
- 設定値をハードコードしない。
- Secret情報をコードへ記述しない。
- 例外を握りつぶさない。

---

## 15.3 Logger利用

ログ出力はLogger経由のみとする。

Spreadsheetへ直接ログを書き込んではならない。

---

# 16. エラー処理

エラー処理は全モジュールで統一する。

---

## 基本方針

- Exceptionを適切に分類する。
- Error Logへ記録する。
- Retry対象を判定する。
- APIレスポンスを統一する。

Retry仕様は **18_GAS_RETRY_STRATEGY.md** を正式情報とする。

---

# 17. テスト方針

実装後は段階的に試験する。

---

## 試験順序

|順序|試験|
|---:|---|
|1|単体試験|
|2|Manager統合試験|
|3|API試験|
|4|Scheduler試験|
|5|システム試験|

詳細は **16_TESTING_STRATEGY.md** を正式情報とする。

---

# 18. 設計方針

GAS実装は以下を設計原則とする。

---

## 単一責務

各モジュールは一つの責務のみを持つ。

---

## Single Source of Truth

|情報|正式管理|
|---|---|
|設定|Spreadsheet|
|Secret|Script Properties|
|API仕様|06_GAS_API_SPEC.md|

---

## 保守性

- モジュール追加を容易にする。
- 共通処理を再利用する。
- Loggerを共通利用する。

---

## 拡張性

将来的な機能追加に対応できる構成を維持する。

---

# 19. 制約事項

本章では GAS 実装における制約事項を定義する。

本書は実装ガイドラインを対象とし、API仕様・Spreadsheet構造・運用仕様・試験仕様の詳細は対象外とする。

---

## 19.1 本書で定義しない事項

|項目|管理文書|
|---|---|
|API仕様|06_GAS_API_SPEC.md|
|ログ仕様|03_LOG_FORMAT.md|
|設定管理|12_CONFIGURATION_MANAGEMENT.md|
|Spreadsheet構造|14_SPREADSHEET_SCHEMA.md|
|運用ポリシー|13_GAS_OPERATION_POLICY.md|
|Retry仕様|18_GAS_RETRY_STRATEGY.md|
|Prompt仕様|19_GEMINI_PROMPT_SPECIFICATION.md|
|試験方法|16_TESTING_STRATEGY.md|

---

## 19.2 実装制約

以下を実装制約とする。

- Spreadsheetを直接操作する処理を各モジュールへ分散させない。
- Loggerを経由せずログを書き込まない。
- Secret情報をScript Properties以外へ保存しない。
- Secret情報をソースコードへ埋め込まない。
- 共通処理はUtilitiesへ集約する。

---

# 20. 将来拡張

本章では将来的な実装拡張を示す。

本章は構想であり、実装を保証するものではない。

---

## 20.1 モジュール追加候補

|モジュール|STATUS|備考|
|---|---|---|
|Notification Manager|PROPOSED|通知管理|
|Backup Manager|PROPOSED|バックアップ|
|Statistics Manager|PROPOSED|統計処理|
|Diagnostic Manager|PROPOSED|診断機能|
|OTA Support|PROPOSED|保守支援|

---

## 20.2 開発支援

将来的に以下を検討する。

- 自動コード生成
- 共通テスト基盤
- Mock環境
- CI対応

詳細仕様は今後決定する。

---

# 21. 未定義事項

|項目|状態|
|---|---|
|フォルダ構成詳細|今後決定|
|命名規約詳細|今後決定|
|Lintルール|今後決定|
|コードレビュー手順|今後決定|
|CI/CD構成|今後決定|

---

# CHANGE LOG

|日付|内容|
|---|---|
|2026-07-15|vNext 1.3文書体系に合わせ全面刷新。GAS実装ガイドとして再設計し、README・CURRENT_STATUS・ROADMAP・06_GAS_API_SPEC・11_SECURITY_MANAGEMENT・12_CONFIGURATION_MANAGEMENT・13_GAS_OPERATION_POLICY・14_SPREADSHEET_SCHEMA・16_TESTING_STRATEGY・18_GAS_RETRY_STRATEGYとの責務を明確化。Single Source of Truthに基づき、実装順序・モジュール責務・開発規約・共通処理を整理し、STATUS表記・文書構成を共通規約へ統一。|
|2026-07-14|Configuration Manager、Health Check、Scheduler構成を更新。|
|2026-06-21|Phase1実装順序およびHealth Check実装結果を反映。|

---

# 付録A. 関連文書の責務

|文書|責務|
|---|---|
|README.md|プロジェクト概要・入口|
|CURRENT_STATUS.md|現在の開発状況|
|ROADMAP.md|中長期計画|
|06_GAS_API_SPEC.md|API仕様|
|11_SECURITY_MANAGEMENT.md|セキュリティ|
|12_CONFIGURATION_MANAGEMENT.md|設定管理|
|13_GAS_OPERATION_POLICY.md|運用方針|
|14_SPREADSHEET_SCHEMA.md|Spreadsheet構造|
|15_GAS_IMPLEMENTATION_GUIDE.md|GAS実装ガイド（本書）|
|16_TESTING_STRATEGY.md|試験方針|
|18_GAS_RETRY_STRATEGY.md|Retry仕様|

---

# 付録B. 更新ルール

本書は以下の場合に更新する。

- 実装順序変更
- モジュール追加・削除
- 共通処理変更
- 開発規約変更
- 実装方針変更
- 文書体系変更

日常的なソースコード修正は記載しない。

現在の実装状況は **CURRENT_STATUS.md** を正式情報とする。

---

# 自己査読チェックリスト

- [x] 文書内矛盾なし
- [x] READMEとの責務分離
- [x] CURRENT_STATUSとの責務分離
- [x] ROADMAPとの責務分離
- [x] 00_PROJECT_CONVENTIONSとの整合
- [x] 06_GAS_API_SPECとの責務分離
- [x] 11_SECURITY_MANAGEMENTとの責務分離
- [x] 12_CONFIGURATION_MANAGEMENTとの責務分離
- [x] 13_GAS_OPERATION_POLICYとの責務分離
- [x] 14_SPREADSHEET_SCHEMAとの責務分離
- [x] 16_TESTING_STRATEGYとの責務分離
- [x] 18_GAS_RETRY_STRATEGYとの責務分離
- [x] STATUS表記統一
- [x] Single Source of Truth維持
- [x] GitHub表示崩れなし
- [x] vNext 1.3文書体系へ適合

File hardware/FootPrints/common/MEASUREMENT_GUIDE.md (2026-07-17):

# Measurement Guide
**Document ID**: PM-FP-011
**Document Name**: MEASUREMENT_GUIDE.md
**Version**: Release v2.2
**Status**: RELEASED
**Last Updated**: 2026-07-17

---

# 1. 目的

本書は PowerModules.pretty に登録するフットプリントの実測方法を標準化する。

設計者による測定誤差や判断のばらつきを低減し、再現性のあるライブラリを構築することを目的とする。

---

# 2. 適用範囲

本書は以下の測定に適用する。

- 市販モジュール
- ブレークアウト基板
- センサーモジュール
- 電源モジュール
- MCUモジュール
- コネクタモジュール

---

# 3. 基本方針

寸法採択順位は以下とする。

1. 現物実測
2. 複数個体比較
3. メーカー図面
4. データシート

推測は禁止する。

未確認事項は

```
未確認
```

と記録する。

---

# 4. 使用測定器

推奨測定器

|測定器|用途|
|---|---|
|デジタルノギス（0.01mm）|標準測定|
|ピンゲージ|穴径確認|
|スケール|参考寸法|
|実体顕微鏡（必要時）|微細部測定|

---

# 5. 測定対象

必須測定項目

- 基板幅
- 基板高さ
- 基板厚
- Pad径
- ドリル径
- Padピッチ
- 固定穴径
- 固定穴間距離
- コネクタ外形
- 突出量

必要に応じて測定する項目

- 部品高さ
- シールド寸法
- 放熱板
- ケース外形

---

# 6. 測定方法

## 6.1 基板寸法

基板エッジを直接測定する。

バリや面取りは除外する。

---

## 6.2 Padピッチ

Pad中心間距離を測定する。

Pad外径は基準としない。

---

## 6.3 固定穴

測定する項目

- 穴径
- 中心座標
- 中心間距離

---

## 6.4 USBシェル

測定する項目

- 幅
- 奥行
- 基板からの突出量

---

# 7. 複数個体測定

可能な限り2個以上測定する。

例

|個体|測定値|
|---|---:|
|Module A|7.42|
|Module B|7.39|

採択値

```
7.40mm
```

理由

個体差を考慮した代表値とする。

---

# 8. 設計値の採択

採択値は実装性を考慮して決定する。

例

|実測値|採択値|
|---:|---:|
|7.42|7.40|
|9.01|9.00|
|21.58|21.60|

---

# 9. 写真記録

測定時は可能な限り写真を保存する。

撮影対象

- 全体
- Pad部
- 固定穴
- コネクタ部
- 測定器表示

写真は GitHub 管理対象外とし、必要に応じて設計資料として保管する。

---

# 10. 記録方法

測定結果は以下を記録する。

- 測定日
- 測定者
- 測定器
- 実測値
- 採択値
- 採択理由

---

# 11. Design Rationale

実測値を採用する理由

- メーカー公差との差異を吸収できる
- 実装時の適合性を高められる
- 再現性を確保できる

USB_C_Breakout_6Pinでは、

- シェル奥行
- シェル幅

について複数個体を測定し、代表値を採択した。

---

# 12. 品質基準

測定結果は以下を満たすこと。

- 実測値を記録済み
- 採択値を記録済み
- 採択理由を記録済み
- 未確認項目は明示済み

---

# 13. 変更履歴

|Version|内容|
|---|---|
|v2.2|初版制定。PowerModulesライブラリ共通の実測ガイドを定義。|

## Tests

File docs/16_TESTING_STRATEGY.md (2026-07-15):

# 16 Testing Strategy

**タイトル**  
16 Testing Strategy

**最終更新**  
2026-07-15

**文書版**  
vNext 1.3

**STATUS**  
FINALIZED

**責務**  
本書は digital-kakejiku の試験方針、試験体系、試験責務、品質判定基準および検証手順を定義する正式設計書である。

**Single Source**  
本書は試験方針を管理する唯一の文書である。

試験区分、品質判定、試験責務および試験実施方針は本書を正式情報とし、他文書では重複管理しない。

---

# 対象読者

- システム設計者
- ハードウェア開発者
- GAS開発者
- ESP32開発者
- 保守担当者

---

# 関連文書

## 前提

- docs/00_PROJECT_CONVENTIONS.md

## 参照

- README.md
- CURRENT_STATUS.md
- ROADMAP.md

## 関連

- docs/01_HARDWARE_OVERVIEW.md
- docs/02_SOFTWARE_OVERVIEW.md
- docs/03_LOG_FORMAT.md
- docs/06_GAS_API_SPEC.md
- docs/15_GAS_IMPLEMENTATION_GUIDE.md
- docs/17_TROUBLESHOOTING.md

## 後続

- 各種試験実施
- 品質評価
- リリース判定

---

# 1. 文書の目的

本書はシステム全体の試験方針を定義する。

本書では以下を管理する。

- 試験体系
- 試験責務
- 品質判定
- 試験実施順序
- 合否判定
- 試験運用

実装コードや試験データそのものは本書では管理しない。

---

# 2. 試験設計方針

本システムでは以下を基本方針とする。

- 段階的試験を実施する。
- 単体試験から順次統合する。
- PASS/FAIL による判定を統一する。
- 再現可能な試験を優先する。
- 試験結果を記録する。
- Single Source of Truth を維持する。

---

# 3. 試験体系

```text
Unit Test
      │
      ▼
Integration Test
      │
      ▼
System Test
      │
      ▼
Acceptance Test
```

---

# 4. 試験区分

|試験|目的|STATUS|
|---|---|---|
|Unit Test|単体確認|CONFIRMED|
|Integration Test|結合確認|CONFIRMED|
|System Test|システム確認|CONFIRMED|
|Acceptance Test|最終確認|CONFIRMED|

---

# 5. Unit Test

Unit Test は各モジュール単体の品質を確認する。

---

## 5.1 対象

|対象|STATUS|
|---|---|
|ESP32 Firmware|CONFIRMED|
|Google Apps Script|CONFIRMED|
|各Manager|CONFIRMED|
|Utilities|CONFIRMED|

---

## 5.2 基本方針

- 単一モジュールのみを対象とする。
- 外部依存を排除する。
- PASS/FAIL を記録する。
- 不具合は再現可能とする。

---

# 6. Integration Test

Integration Test はモジュール間の連携を確認する。

---

## 対象

- API
- Configuration
- Logger
- Calendar
- Poem
- Retry
- Scheduler

---

## 基本方針

- モジュール間I/Fを確認する。
- データ整合性を確認する。
- ログ出力を確認する。

---

# 7. System Test

System Test はシステム全体を対象とする。

---

## 対象

- ESP32
- GAS
- Spreadsheet
- センサー
- 表示
- 電源

---

## 基本方針

- 実機で確認する。
- 通常系・異常系を確認する。
- 運用を想定する。

---

# 8. Acceptance Test

Acceptance Test は最終受入試験である。

---

## 確認内容

- 要件充足
- 品質確認
- 長時間運転
- 運用確認

---

## 判定

|RESULT|意味|
|---|---|
|PASS|受入可能|
|FAIL|修正必要|

---

# 9. 試験順序

試験は以下の順序で実施する。

```text
Unit Test
      │
      ▼
Integration Test
      │
      ▼
System Test
      │
      ▼
Acceptance Test
```

各段階で PASS した場合のみ次工程へ進む。

---

# 10. 試験データ

試験では再現可能なデータを使用する。

---

## 基本方針

- 同一条件を維持する。
- 必要に応じて固定データを利用する。
- 実データと試験データを区別する。
- Secret情報を使用しない。

---

# 11. 判定基準

試験結果は RESULT により判定する。

|RESULT|意味|
|---|---|
|PASS|期待どおり|
|FAIL|期待を満たさない|

GO / NG は開発判断に使用し、試験合否には使用しない。

---

# 12. ログ確認

試験ではログも確認対象とする。

---

## 確認対象

|ログ|確認内容|
|---|---|
|System Log|状態遷移|
|Error Log|例外|
|Observation Log|観測|
|Event Log|イベント|

ログ仕様は **03_LOG_FORMAT.md** を正式情報とする。

---

# 13. エラー試験

エラー処理および障害耐性を確認する。

---

## 13.1 確認対象

|対象|確認内容|
|---|---|
|API異常|適切なエラー応答|
|通信異常|Retry実施|
|Spreadsheet異常|Error Log出力|
|Gemini異常|RetryおよびError Log|
|設定異常|Validation|

---

## 13.2 基本方針

- 異常系を意図的に発生させる。
- Retry動作を確認する。
- エラー分類を確認する。
- Secret情報が出力されないことを確認する。

---

# 14. 長時間試験

システムの安定性を確認する。

---

## 確認内容

- 長時間連続動作
- メモリリーク有無
- ログ増加
- Retry継続動作
- スケジューラ動作

---

## 基本方針

- 実運用条件を想定する。
- 定期ジョブを継続実行する。
- 障害発生有無を確認する。

---

# 15. 品質判定

品質判定は試験結果全体で評価する。

---

## 基本方針

- 各試験はPASS/FAILで判定する。
- FAIL項目を残したまま次工程へ進めない。
- 修正後は再試験を実施する。
- 判定根拠を記録する。

---

## 判定例

|項目|RESULT|
|---|---|
|Unit Test|PASS|
|Integration Test|PASS|
|System Test|PASS|
|Acceptance Test|PASS|

---

# 16. 試験記録

試験結果は記録として保存する。

---

## 記録内容

- 試験日
- 試験担当者
- 試験環境
- 実施内容
- 結果
- 不具合
- 修正履歴

---

## 基本方針

- 再現可能な情報を残す。
- 実施内容を省略しない。
- 判定理由を明記する。

---

# 17. 設計方針

試験設計は以下を原則とする。

---

## 単一責務

各試験は一つの目的のみを持つ。

---

## Single Source of Truth

|情報|正式管理|
|---|---|
|試験方針|本書|
|API仕様|06_GAS_API_SPEC.md|
|ログ仕様|03_LOG_FORMAT.md|
|Retry仕様|18_GAS_RETRY_STRATEGY.md|

---

## 保守性

- 試験追加を容易にする。
- 試験項目を独立管理する。
- 判定方法を統一する。

---

## 拡張性

将来的な試験追加に対応できる構成を維持する。

---

# 18. 制約事項

本書では試験方針を定義する。

以下は対象外とする。

|項目|管理文書|
|---|---|
|実装コード|ソースコード|
|API仕様詳細|06_GAS_API_SPEC.md|
|Spreadsheet構造|14_SPREADSHEET_SCHEMA.md|
|障害対応手順|17_TROUBLESHOOTING.md|
|Retry詳細|18_GAS_RETRY_STRATEGY.md|

---

# 19. 将来拡張

本章では将来的に追加を検討する試験機能を示す。

本章は構想であり、実装を保証するものではない。

---

## 19.1 試験追加候補

|試験|STATUS|備考|
|---|---|---|
|Performance Test|PROPOSED|性能評価|
|Stress Test|PROPOSED|高負荷試験|
|Recovery Test|PROPOSED|障害復旧確認|
|Regression Test|PROPOSED|回帰試験|
|Security Test|PROPOSED|セキュリティ評価|

---

## 19.2 自動化

将来的に以下を検討する。

- 自動試験
- CI連携
- 自動レポート生成
- 自動品質判定

詳細仕様は今後決定する。

---

# 20. 未定義事項

|項目|状態|
|---|---|
|CI/CD構成|今後決定|
|試験自動化ツール|今後決定|
|性能評価基準|今後決定|
|長期試験期間|今後決定|
|品質メトリクス|今後決定|

---

# CHANGE LOG

|日付|内容|
|---|---|
|2026-07-15|vNext 1.3文書体系に合わせ全面刷新。試験方針文書として再設計し、README・CURRENT_STATUS・ROADMAP・03_LOG_FORMAT・06_GAS_API_SPEC・15_GAS_IMPLEMENTATION_GUIDE・17_TROUBLESHOOTING・18_GAS_RETRY_STRATEGYとの責務を明確化。Single Source of Truthに基づき、試験体系・判定基準・品質評価・試験記録を整理し、STATUS・RESULT表記および文書構成を共通規約へ統一。|
|2026-07-14|System Test、Acceptance Test、長時間試験およびエラー試験を整理。|
|2026-06-21|Phase1 Health CheckおよびConfiguration Manager試験結果を反映。|

---

# 付録A. 関連文書の責務

|文書|責務|
|---|---|
|README.md|プロジェクト概要・入口|
|CURRENT_STATUS.md|現在の開発状況|
|ROADMAP.md|中長期計画|
|03_LOG_FORMAT.md|ログ仕様|
|06_GAS_API_SPEC.md|API仕様|
|15_GAS_IMPLEMENTATION_GUIDE.md|実装ガイド|
|16_TESTING_STRATEGY.md|試験方針（本書）|
|17_TROUBLESHOOTING.md|障害対応|
|18_GAS_RETRY_STRATEGY.md|Retry仕様|

---

# 付録B. 更新ルール

本書は以下の場合に更新する。

- 試験区分追加・削除
- 判定基準変更
- 試験手順変更
- 品質評価方法変更
- 試験運用変更
- 文書体系変更

日常的な試験結果は記載しない。

試験実施結果および進捗は **CURRENT_STATUS.md** を正式情報とする。

---

# 自己査読チェックリスト

- [x] 文書内矛盾なし
- [x] READMEとの責務分離
- [x] CURRENT_STATUSとの責務分離
- [x] ROADMAPとの責務分離
- [x] 00_PROJECT_CONVENTIONSとの整合
- [x] 03_LOG_FORMATとの責務分離
- [x] 06_GAS_API_SPECとの責務分離
- [x] 15_GAS_IMPLEMENTATION_GUIDEとの責務分離
- [x] 17_TROUBLESHOOTINGとの責務分離
- [x] 18_GAS_RETRY_STRATEGYとの責務分離
- [x] STATUS表記統一
- [x] RESULT表記統一
- [x] Single Source of Truth維持
- [x] GitHub表示崩れなし
- [x] vNext 1.3文書体系へ適合

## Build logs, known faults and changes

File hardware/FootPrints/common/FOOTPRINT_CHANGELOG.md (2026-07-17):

# PowerModules Library Change Log
**Document ID**: PM-FP-007
**Document Name**: FOOTPRINT_CHANGELOG.md
**Version**: Release v2.0
**Status**: RELEASED
**Last Updated**: 2026-07-17

---

# 1. 目的

本書は PowerModules.pretty ライブラリの変更履歴を管理する。

単なる更新履歴ではなく、

- 設計方針
- 設計変更理由
- 採択理由
- 廃止理由

を含む設計履歴として管理する。

---

# 2. 管理方針

変更履歴は

「何を変更したか」

だけではなく

「なぜ変更したか」

を必ず記録する。

設計判断が追跡できることを目的とする。

---

# 3. Version管理

|Version|意味|
|---|---|
|Major|設計思想変更|
|Minor|仕様追加|
|Patch|誤記修正|

例

```
v2.0.0
```

Release版

```
v2.1.0
```

仕様追加

```
v2.1.1
```

誤記修正

---

# 4. Release履歴

## v2.0.0

初回正式Release

PowerModules.pretty運用開始

---

# 5. USB_C_Breakout_6Pin

### 新規追加

PowerModulesライブラリ第1号として登録。

---

### 採択事項

#### 原点

変更前

```
Pad1中心
```

変更後

```
基板中心
```

理由

左右対称モジュールでは
Pad基準より
基板中心基準の方が

- 機械設計
- PCB設計
- レビュー

すべて容易になるため。

---

#### USBシェル寸法

実測

```
7.42
7.39
```

採択

```
7.40
```

---

#### Pad

Pad径

```
1.80mm
```

穴径

```
1.00mm
```

---

#### 固定穴

```
NPTH Mechanical
```

採択。

---

#### Pin1

Pad1

```
RoundRect
```

採択。

---

#### F.SilkS

追加

```
USB-C 6P
```

```
VBUS
```

```
GND
```

```
CC1
```

```
D-
```

```
D+
```

```
CC2
```

理由

配線確認性向上。

---

#### F.Courtyard

追加。

USB突出部を含め

```
+0.50mm
```

採択。

---

### 保存手順

今回発生した

ライブラリ認識問題を受け

以下を正式採択。

```
保存
```

↓

```
エディタ終了
```

↓

```
ライブラリ再読込
```

↓

```
レビュー
```

---

# 6. ライブラリ共通ルール制定

今回新たに制定。

・基板中心原点

・実測優先

・推測禁止

・Pad番号のみ管理

・信号名は回路図側

・端子名称はF.SilkS

・Description必須

・Keywords必須

・レビュー必須

・GitHub管理

---

# 7. 今後の予定

以下を順次追加予定。

```
TPS63802_Module
```

```
IP5306_Module
```

```
DS3231_AT24_Module
```

```
OLED_0_91_Module
```

```
SPS30_Module
```

```
LD2410C_Module
```

```
BME680_Module
```

```
LTR390_Module
```

```
XIAO_ESP32S3_Plus
```

---

# 8. 更新ルール

変更時は

以下を必ず記録する。

・Version

・日付

・変更内容

・変更理由

・担当者

---

# 9. Change Log

|Version|Date|内容|
|---|---|---|
|2.0.0|2026-07-17|PowerModules Library Release第1版公開|

---

# 10. Design History

## 採用した設計

- 基板中心原点
- 実測優先
- F.SilkS端子名称
- F.Courtyard追加
- 保存→再読込確認
- GitHub文書管理

---

## 採用しなかった設計

### Pad1原点

理由

左右対称部品では

機械設計との整合が悪いため。

---

### Padへ信号名付与

理由

信号管理は

回路図シンボル側へ集約するため。

---

# 11. 変更履歴

|Version|内容|
|---|---|
|v2.0|Release第1版制定|

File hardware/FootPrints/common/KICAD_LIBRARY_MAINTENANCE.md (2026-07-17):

# KiCad Library Maintenance Guide
**Document ID**: PM-FP-009
**Version**: Release v2.1

---

# 1. 目的

PowerModules.pretty の長期運用手順を定義する。

---

# 2. ディレクトリ構成

PowerBoard/

PowerModules.pretty/

docs/

backup/

---

# 3. バックアップ

変更前に

PowerModules.pretty

を丸ごとコピーする。

推奨

```
PowerModules_20260717.pretty
```

---

# 4. KiCad更新時

確認項目

- ライブラリ読込

- Description

- Keywords

- Reference

- Courtyard

- DRC

---

# 5. ライブラリ追加

追加前

レビュー実施

↓

追加

↓

保存

↓

再読込

↓

PCB確認

↓

GitHub更新

---

# 6. ライブラリ名称変更

変更禁止

PowerModules.pretty

固定

---

# 7. フォルダ移動

移動後

必ず

```
フットプリントライブラリ管理
```

で確認する。

---

# 8. GitHub運用

更新対象

- pretty

- md

- ChangeLog

同一コミットを推奨。

---

# 9. リリース

Major

設計思想変更

Minor

部品追加

Patch

誤記修正

---

# 10. 障害対応

ライブラリが見えない

↓

ライブラリ管理確認

↓

pretty存在確認

↓

再読込

↓

PCB確認

---

# 11. 推奨バックアップ

毎週

GitHub Push

主要更新時

ZIP保存

リリース時

Tag作成

---

# 12. 保守チェックリスト

□ ライブラリ読込

□ Description

□ Keywords

□ Reference

□ Value

□ DRC

□ GitHub

□ Tag

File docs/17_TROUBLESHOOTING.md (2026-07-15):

# 17 Troubleshooting

**タイトル**  
17 Troubleshooting

**最終更新**  
2026-07-15

**文書版**  
vNext 1.3

**STATUS**  
FINALIZED

**責務**  
本書は digital-kakejiku における障害調査、原因切り分け、復旧手順および保守時の対応方針を定義する正式設計書である。

**Single Source**  
本書は障害対応手順を管理する唯一の文書である。

障害分類、調査手順、復旧方針および保守対応は本書を正式情報とし、他文書では重複管理しない。

---

# 対象読者

- 保守担当者
- GAS開発者
- ESP32開発者
- システム設計者

---

# 関連文書

## 前提

- docs/00_PROJECT_CONVENTIONS.md

## 参照

- README.md
- CURRENT_STATUS.md
- ROADMAP.md

## 関連

- docs/03_LOG_FORMAT.md
- docs/06_GAS_API_SPEC.md
- docs/11_SECURITY_MANAGEMENT.md
- docs/13_GAS_OPERATION_POLICY.md
- docs/16_TESTING_STRATEGY.md
- docs/18_GAS_RETRY_STRATEGY.md

## 後続

- 障害解析
- 修正実施
- 再試験

---

# 1. 文書の目的

本書はシステム障害発生時の調査および復旧方針を定義する。

本書では以下を管理する。

- 障害分類
- 調査手順
- 復旧手順
- ログ確認
- 原因切り分け
- 保守ルール

実装コードや障害修正方法そのものは本書では管理しない。

---

# 2. 基本方針

本システムでは以下を基本方針とする。

- 再現性を確認する。
- ログを優先して確認する。
- 原因を切り分ける。
- Secret情報を保護する。
- 修正後は再試験を実施する。
- Single Source of Truth を維持する。

---

# 3. 障害分類

|分類|内容|STATUS|
|---|---|---|
|Hardware|ハードウェア障害|CONFIRMED|
|Firmware|ESP32障害|CONFIRMED|
|GAS|Google Apps Script障害|CONFIRMED|
|Spreadsheet|データ障害|CONFIRMED|
|Network|通信障害|CONFIRMED|
|Configuration|設定障害|CONFIRMED|

---

# 4. 調査手順

障害発生時は以下の順序で調査する。

```text
障害確認
     │
     ▼
再現確認
     │
     ▼
ログ確認
     │
     ▼
原因切り分け
     │
     ▼
修正
     │
     ▼
再試験
```

---

# 5. ログ確認

障害解析ではログを最優先で確認する。

---

## 5.1 確認順序

|順序|ログ|
|---:|---|
|1|Error Log|
|2|System Log|
|3|Event Log|
|4|Observation Log|

---

## 5.2 基本方針

- Error Logから確認する。
- 障害発生時刻を特定する。
- 関連ログを時系列で確認する。
- Secret情報が出力されていないことを確認する。

ログ仕様は **03_LOG_FORMAT.md** を正式情報とする。

---

# 6. Hardware障害

Hardware障害は物理機器を対象とする。

---

## 確認項目

- 電源電圧
- 配線
- コネクタ
- センサー接続
- SPI/I2C通信
- 基板実装状態

---

## 基本方針

- 電源から確認する。
- 配線ミスを除外する。
- 導通確認を実施する。
- モジュール単位で切り分ける。

---

# 7. Firmware障害

Firmware障害はESP32側を対象とする。

---

## 確認項目

- 起動ログ
- API通信
- センサー取得
- Display更新
- State Machine

---

## 基本方針

- シリアルログを確認する。
- 設定値を確認する。
- 再現性を確認する。

---

# 8. GAS障害

Google Apps Script の障害を確認する。

---

## 確認項目

- Health Check
- Logger
- Configuration Manager
- Calendar Manager
- Poem Manager
- API

---

## 基本方針

- Health Checkを最初に実施する。
- Script Propertiesを確認する。
- Spreadsheet接続を確認する。
- Error Logを確認する。

---

# 9. Spreadsheet障害

Spreadsheet構造またはデータ異常を確認する。

---

## 確認項目

- シート存在
- 必須カラム
- 主キー
- 設定値
- データ整合性

---

## 基本方針

- 必須シートを確認する。
- キー重複を確認する。
- 必須設定を確認する。

Spreadsheet構造は **14_SPREADSHEET_SCHEMA.md** を正式情報とする。

---

# 10. Network障害

通信障害を確認する。

---

## 確認項目

- HTTPS通信
- API応答
- Timeout
- Retry

---

## 基本方針

- 通信経路を確認する。
- Retry動作を確認する。
- APIレスポンスを確認する。

Retry仕様は **18_GAS_RETRY_STRATEGY.md** を正式情報とする。

---

# 11. Configuration障害

設定異常を確認する。

---

## 確認項目

- system_config
- source_config
- Script Properties
- 必須キー

---

## 基本方針

- 必須キーを確認する。
- 型を確認する。
- Secret情報を確認する。

設定仕様は **12_CONFIGURATION_MANAGEMENT.md** を正式情報とする。

---

# 12. 復旧方針

復旧は原因を特定した後に実施する。

---

## 基本方針

- 原因未特定で設定変更しない。
- 一度に複数箇所を変更しない。
- 修正後は再試験する。
- 復旧内容をEvent Logへ記録する。

試験方針は **16_TESTING_STRATEGY.md** を正式情報とする。

---

# 13. 障害記録

障害対応では調査内容を記録として残す。

---

## 13.1 記録内容

以下を記録する。

- 発生日時
- 障害分類
- 発生条件
- 原因
- 対応内容
- 修正内容
- 再試験結果
- 判定結果

---

## 13.2 基本方針

- 原因と推測を区別する。
- 再現条件を明記する。
- 修正内容を記録する。
- PASS / FAIL を明記する。

---

# 14. エスカレーション

障害内容に応じて調査範囲を拡大する。

---

## 14.1 基本方針

- 原因が判明しない場合は上位レイヤへ切り分ける。
- 修正前にログを保存する。
- Secret情報を外部へ送信しない。
- 暫定対策と恒久対策を区別する。

---

## 14.2 切り分け順序

```text
Hardware
     │
Firmware
     │
Network
     │
GAS
     │
Spreadsheet
     │
Configuration
```

障害が複数レイヤへ波及している場合は、最初に発生した原因を優先して特定する。

---

# 15. 障害分類と対応

|障害分類|初期対応|RESULT|
|---|---|---|
|Hardware|電源・配線確認|GO|
|Firmware|シリアルログ確認|GO|
|Network|通信確認|GO|
|GAS|Health Check実施|GO|
|Spreadsheet|シート・データ確認|GO|
|Configuration|設定値確認|GO|

GO は調査開始可否を示すものであり、障害解決を意味しない。

---

# 16. 再試験

障害修正後は再試験を実施する。

---

## 基本方針

- 修正箇所のみで終了しない。
- 関連機能も確認する。
- PASS を確認する。
- 再現しないことを確認する。

試験方針は **16_TESTING_STRATEGY.md** を正式情報とする。

---

# 17. 設計方針

障害対応は以下を設計原則とする。

---

## 単一責務

- 障害調査
- 原因分析
- 修正
- 再試験

を明確に分離する。

---

## Single Source of Truth

|情報|正式管理|
|---|---|
|障害対応|本書|
|ログ仕様|03_LOG_FORMAT.md|
|試験方針|16_TESTING_STRATEGY.md|
|Retry仕様|18_GAS_RETRY_STRATEGY.md|

---

## 保守性

- 調査手順を統一する。
- ログを共通利用する。
- 原因分析を容易にする。

---

## 拡張性

将来的な障害分類追加に対応できる構成を維持する。

---

# 18. 制約事項

本書では障害対応方針を定義する。

以下は対象外とする。

|項目|管理文書|
|---|---|
|実装修正方法|ソースコード|
|API仕様|06_GAS_API_SPEC.md|
|Spreadsheet構造|14_SPREADSHEET_SCHEMA.md|
|Retryアルゴリズム|18_GAS_RETRY_STRATEGY.md|
|実装ガイド|15_GAS_IMPLEMENTATION_GUIDE.md|

---

# 19. 将来拡張

本章は将来的な障害対応機能を示す。

---

## 19.1 拡張候補

|項目|STATUS|備考|
|---|---|---|
|自己診断機能|PROPOSED|詳細未定|
|障害レポート生成|PROPOSED|詳細未定|
|自動復旧機能|PROPOSED|詳細未定|
|統計分析|PROPOSED|詳細未定|
|監視ダッシュボード|PROPOSED|詳細未定|

---

## 19.2 保守支援

将来的に以下を検討する。

- 障害分析支援
- 自動ログ解析
- 根本原因分析支援
- 障害履歴検索

詳細仕様は今後決定する。

---

# 20. 未定義事項

|項目|状態|
|---|---|
|障害通知方式|今後決定|
|自動復旧条件|今後決定|
|障害統計保持期間|今後決定|
|監視方式|今後決定|
|外部通知連携|今後決定|

---

# CHANGE LOG

|日付|内容|
|---|---|
|2026-07-15|vNext 1.3文書体系に合わせ全面刷新。障害対応文書として再設計し、README・CURRENT_STATUS・ROADMAP・03_LOG_FORMAT・06_GAS_API_SPEC・11_SECURITY_MANAGEMENT・12_CONFIGURATION_MANAGEMENT・13_GAS_OPERATION_POLICY・16_TESTING_STRATEGY・18_GAS_RETRY_STRATEGYとの責務を明確化。Single Source of Truthに基づき、障害分類・調査手順・復旧方針・再試験・障害記録を整理し、STATUS・RESULT表記および文書構成を共通規約へ統一。|
|2026-07-14|Health Checkを中心としたGAS障害調査手順を更新。|
|2026-06-21|Phase1 Health CheckおよびConfiguration Manager確認手順を反映。|

---

# 付録A. 関連文書の責務

|文書|責務|
|---|---|
|README.md|プロジェクト概要・入口|
|CURRENT_STATUS.md|現在の障害状況・進捗|
|ROADMAP.md|中長期計画|
|03_LOG_FORMAT.md|ログ仕様|
|06_GAS_API_SPEC.md|API仕様|
|11_SECURITY_MANAGEMENT.md|セキュリティ|
|12_CONFIGURATION_MANAGEMENT.md|設定管理|
|13_GAS_OPERATION_POLICY.md|運用方針|
|16_TESTING_STRATEGY.md|試験方針|
|17_TROUBLESHOOTING.md|障害対応（本書）|
|18_GAS_RETRY_STRATEGY.md|Retry仕様|

---

# 付録B. 更新ルール

本書は以下の場合に更新する。

- 障害分類変更
- 調査手順変更
- 復旧方針変更
- ログ運用変更
- 保守手順変更
- 文書体系変更

日常的な障害発生状況は記載しない。

現在の障害状況は **CURRENT_STATUS.md** を正式情報とする。

---

# 自己査読チェックリスト

- [x] 文書内矛盾なし
- [x] READMEとの責務分離
- [x] CURRENT_STATUSとの責務分離
- [x] ROADMAPとの責務分離
- [x] 00_PROJECT_CONVENTIONSとの整合
- [x] 03_LOG_FORMATとの責務分離
- [x] 06_GAS_API_SPECとの責務分離
- [x] 11_SECURITY_MANAGEMENTとの責務分離
- [x] 12_CONFIGURATION_MANAGEMENTとの責務分離
- [x] 13_GAS_OPERATION_POLICYとの責務分離
- [x] 16_TESTING_STRATEGYとの責務分離
- [x] 18_GAS_RETRY_STRATEGYとの責務分離
- [x] STATUS表記統一
- [x] RESULT表記統一
- [x] Single Source of Truth維持
- [x] GitHub表示崩れなし
- [x] vNext 1.3文書体系へ適合

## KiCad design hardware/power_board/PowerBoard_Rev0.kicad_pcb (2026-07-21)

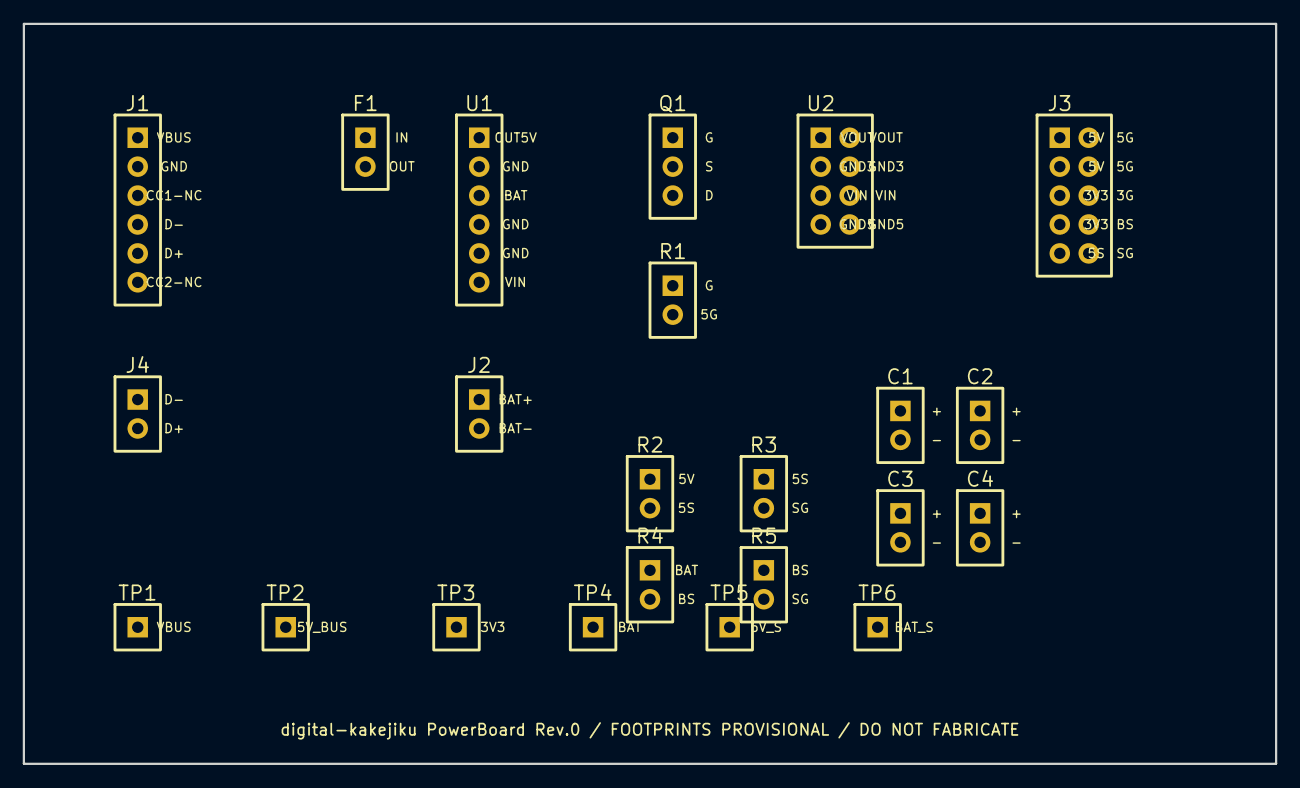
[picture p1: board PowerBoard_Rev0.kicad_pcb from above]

Board: 2 copper layers, 110.0 x 65.0 mm, 23 parts (0 on the bottom side), 15 nets, no tracks yet.

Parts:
C1: 0.1u; C1
C2: 470u; C2
C3: 0.1u; C3
C4: 220u; C4
F1: PTC; F1
J1: USB-C BREAKOUT; J1
J2: 18650; J2
J3: MAIN POWER 10PIN; J3
J4: USB DATA; J4
Q1: DMG2305UX-13; Q1
R1: 100k; R1
R2: 150k; R2
R3: 100k; R3
R4: 100k; R4
R5: 100k; R5
TP1: VBUS; TP1
TP2: 5V_BUS; TP2
TP3: 3V3; TP3
TP4: BAT; TP4
TP5: 5V_S; TP5
TP6: BAT_S; TP6
U1: IP5306 MODULE; U1
U2: TPS63802 MODULE; U2

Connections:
3V3_GND: C3.2, C4.2, J3.6, U2.3, U2.4
3V3_OUT: C3.1, C4.1, J3.5, J3.7, TP3.1, U2.1, U2.2
5V_BUS: C1.1, C2.1, J3.1, J3.3, Q1.3, R2.1, TP2.1, U2.5, U2.6
5V_GND: J1.2, J1.3, J1.6, J3.2, J3.4, R1.2, U1.2, U1.4, U1.5
5V_SENSE: J3.9, R2.2, R3.1, TP5.1
BAT: J2.1, R4.1, TP4.1, U1.3
BATTERY_SENSE: J3.8, R4.2, R5.1, TP6.1
OUT_5V: Q1.2, U1.1
Q_GATE: Q1.1, R1.1
SENSE_GND: J3.10, R3.2, R5.2
TPS_IN_GND: C1.2, C2.2, U2.7, U2.8
USB_D+: J1.5, J4.2
USB_D-: J1.4, J4.1
VBUS: F1.1, J1.1, TP1.1
VIN_IP5306: F1.2, U1.6

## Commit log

2026-05-31 DOC:電源アーキテクチャ確定(IP5306 + TPS63802 + UPS)
2026-06-02 Doc:刷新
2026-06-28 DOC:Power Renewal
2026-07-10 DOC:電源方針変更
